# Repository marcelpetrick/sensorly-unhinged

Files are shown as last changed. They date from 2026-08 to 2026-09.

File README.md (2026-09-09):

# sensorly-unhinged








A battery-powered indoor temperature and humidity node, developed as **one
electrical platform in two physical implementations** so that the cost of
compactness can be measured instead of guessed.

**Author: Marcel Petrick <mail@marcelpetrick.it>**

**License: GPLv3 or later. See `LICENSE`.**

**Note: project is generated with AI.**

```
                    ESP32-C6-MINI-1 + SHT45-AD1F + BQ24074 + TPS62840
                    1S LiPo · USB-C · deep sleep · BLE provisioning · MQTT/TLS
                                          |
                 +------------------------+------------------------+
                 |                                                 |
         Variant A - Compact                        Variant B - Thermally isolated
         30 × 34 mm, one rectangle                  28 × 51 mm, milled sensor island
         sensor 11.3 mm from the                    on a 3.5 x 8 mm FR-4 neck,
         nearest heat source                        sensor 16.5 mm away;
                                                    thermal benefit unmeasured
```

| | |
|---|---|
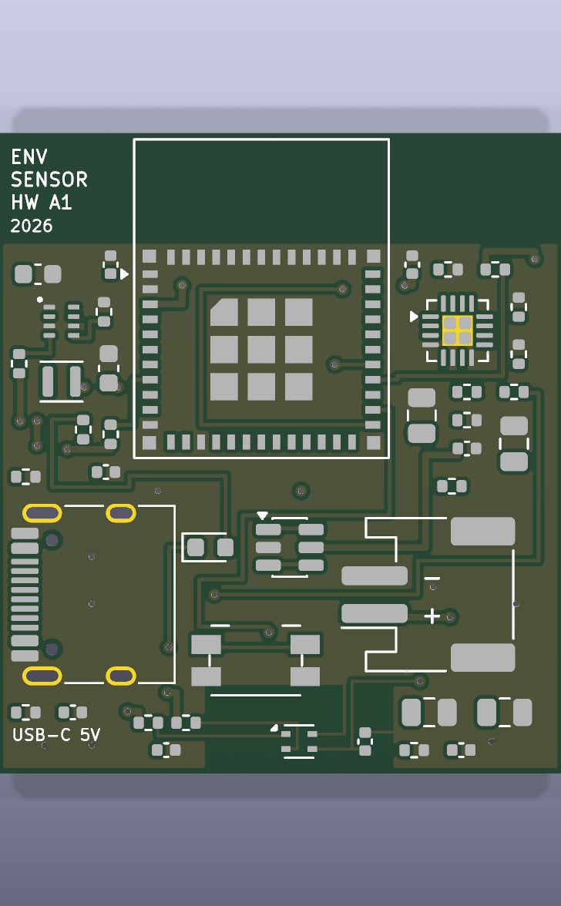
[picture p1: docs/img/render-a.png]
Variant A
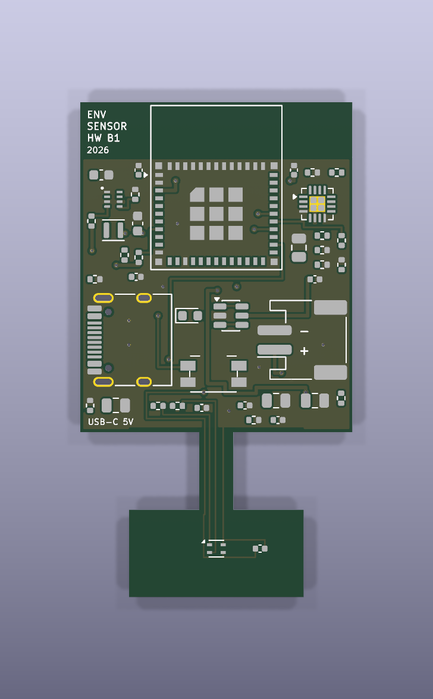
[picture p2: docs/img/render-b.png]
Variant B
|  |  |
| **A — Compact** (HW A1) | **B — Thermally isolated** (HW B1) |
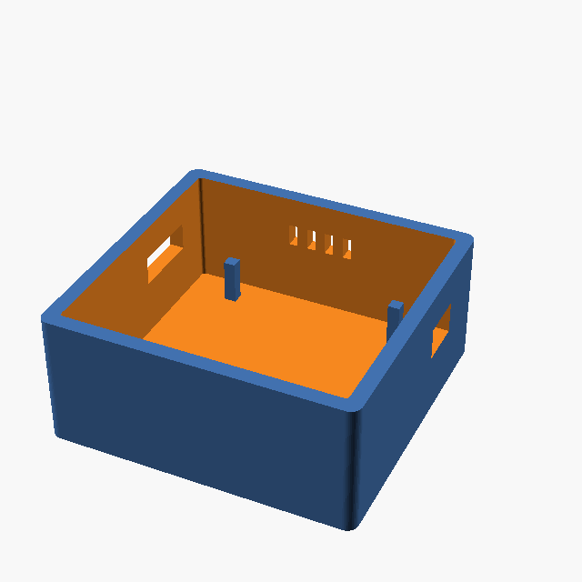
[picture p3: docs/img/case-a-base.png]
Case A
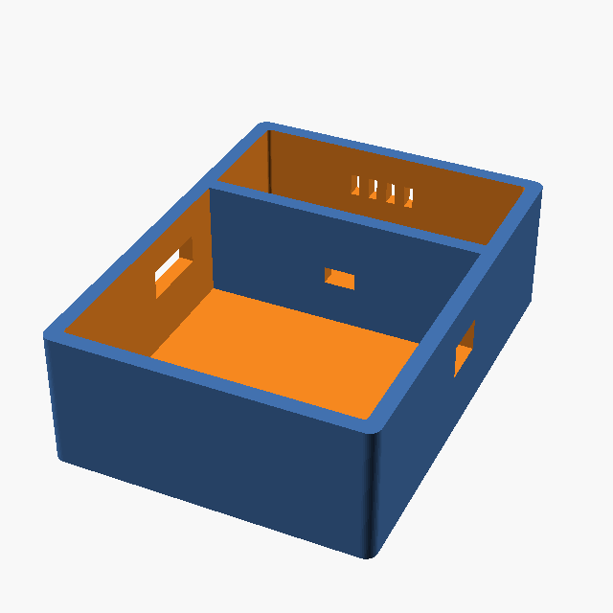
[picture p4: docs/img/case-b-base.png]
Case B
|  |  |
| 47.0 × 39.2 × 18.8 mm, one chamber | 47.0 × 56.2 × 18.8 mm, two chambers, wall at the neck |

Build 5 of each, put them next to a reference instrument, and let the data pick
the design. The decision gate is written down in
[`docs/50-thermal-ab-test-plan.md`](docs/50-thermal-ab-test-plan.md) *before* the
boards exist, including the thresholds under which A wins.

## Status

**Engineering prototype; not ready for fabrication or use.** The
[twenty-finding review](docs/90-expert-review.md) records corrective work and
unresolved qualification. `make outputs` produces explicitly marked draft
review files. `make release-check` requires complete routing, clean DRC/parity
and the evidence listed in `hardware/release-readiness.json`. A development
pipeline pass does not imply a working sensor or safe battery charging.

**Partially routed:** 59 unconnected items on A and 60 on B. The sensor routes
and some power/ground fan-out are generated; the fine-pitch escapes and other
main-board connections remain incomplete. Development DRC has zero errors,
with explicitly limited warnings; it is not a clean manufacturing DRC.
Phase 6 of 14 — see [`docs/00-plan.md`](docs/00-plan.md).

```
KiCad ERC      0 violations
KiCad DRC      0 errors, 7 / 17 development warnings on A / B (KiCad 10.0.6)
Sch/PCB parity 0 differences  (both are generated from one model)
Ratsnest       A: 59 remaining; B: 60 remaining (see hardware/drc-budget.json)
Outputs        4-layer gerbers, drill, CPL, assembly PDF, STEP, schematic PDF, BOM
```

schematic

## Build

Everything runs from `make`. If a step cannot, it is not part of the build.

```bash
./localPipeline.sh   # everything below, with a PASS/FAIL summary
```

Or step by step:

```bash
make license   # every authored source carries an SPDX header
make check     # generator rule checks   (Python only, no KiCad needed)
make test      # fault-injection regressions for electrical, build and model failures
make gen       # regenerate the schematic, both boards, project files, rules, SVGs
make erc       # KiCad ERC on the shared schematic
make drc       # KiCad DRC + schematic/PCB parity gate on both variants
make bom       # BOM + netlist from the shared design model
make thermal   # regenerate the thermal model from the live geometry
make cost      # regenerate the manufacturing estimate from the real design
make mech      # enclosure model + checks + OpenSCAD params (STL if openscad)
make outputs   # gerbers, drill, CPL, assembly PDF, STEP
make render    # KiCad 3D renders
make mech-render # optional enclosure PNG previews (requires a graphics display)
make power     # illustrative battery-side charge budget; replace inputs with measurements
make release-check # fails until routing and qualification are complete
make release-package RELEASE_TAG=hw-a1 # gated ZIP + SHA-256 for one printed revision
make all
```

Python-only checks include `check`, `test`, `bom`, `thermal`, `cost`, and `power`.
ERC/DRC, board renders and exports require KiCad 10 (`kicad-cli`); mesh checks
require OpenSCAD. Offline checks alone cannot establish hardware readiness.

GitHub's **Hardware Quality** workflow runs the same `localPipeline.sh` gate and
retains draft Gerbers, reports and enclosure meshes for 14 days. The separate,
manual **Hardware Release** workflow accepts only a tag matching the revision
printed on the selected PCB (`hw-a1` or `hw-b1` today). It cannot package or
publish until `make release-check` proves clean routing, clean DRC/parity and
all seven qualification-evidence categories. Publishing is opt-in and draft by
default; a successful package contains a SHA-256 checksum and source provenance.

## How the two boards stay one design

`tools/boardgen/` holds the parts, values, netlist, net classes and design
rules **once**. `variants.py` is the only variant-specific file, and it contains
outline, sensor position and thermal zones — nothing electrical. Both
`.kicad_pcb` files are emitted from that model, so a rule change cannot silently
apply to only one board.

The four sensor-island nets are routed by the generator rather than by hand,
because they carry a rule — 0.15 mm wide, no vias, nothing else near them — and
the same rule is written into each variant's `.kicad_dru`. A number that only
lives in a designer's memory gets widened the first time a route is awkward.

## Documents

| | |
|---|---|
| [`AGENTS.md`](AGENTS.md) | working agreement — read before changing anything |
| [`docs/00-plan.md`](docs/00-plan.md) | 14 phases with gates, schedule, risks, non-goals |
| [`docs/10-requirements.md`](docs/10-requirements.md) | numbered requirements, locked vs open |
| [`docs/20-component-selection.md`](docs/20-component-selection.md) | why SHT45 and not BME280; why C6 and not C3 |
| [`docs/30-electrical-design-spec.md`](docs/30-electrical-design-spec.md) | the circuit, every value traced to a datasheet |
| [`docs/40-floorplans.md`](docs/40-floorplans.md) | A vs B, and what the layout decided |
| [`hardware/outputs/schematic/env-sensor.pdf`](hardware/outputs/schematic/env-sensor.pdf) | the schematic, as built |
| [`docs/45-thermal-model.md`](docs/45-thermal-model.md) | generated screening model |
| [`docs/50-thermal-ab-test-plan.md`](docs/50-thermal-ab-test-plan.md) | the experiment and its decision gate |
| [`docs/60-manufacturing-cost.md`](docs/60-manufacturing-cost.md) | generated cost estimate, from the real joint count |
| [`docs/61-cost-reduction.md`](docs/61-cost-reduction.md) | what would make it cheaper, and what each saving costs |
| [`docs/62-fabrication-3-boards.md`](docs/62-fabrication-3-boards.md) | who makes three boards, and what the antenna needs from them |
| [`docs/70-what-the-board-can-do.md`](docs/70-what-the-board-can-do.md) | what firmware alone unlocks — three radios, one board |
| [`docs/80-enclosure.md`](docs/80-enclosure.md) | generated enclosure model, and the requirements it breaks |
| [`docs/vision.md`](docs/vision.md) | the original transcript this was distilled from |

## Layout

```
docs/            requirements, specs, trade studies, test plans
hardware/
  lib/           project footprint library (vendored + authored, verified)
  variant-a/     HW A1 - compact
  variant-b/     HW B1 - thermally isolated
  outputs/       gerbers, drill, BOM, CPL, STEP  (regenerated by CI)
hardware/schematic/  one generated schematic, shared by both variants
tools/boardgen/  the shared model: design, schematic, geometry, placer, router, checks
mechanical/      OpenSCAD enclosures, generated parameters from the board
firmware/        ESP-IDF application (not started)
```

## Licence

**GPL-3.0-or-later** — see [`LICENSE`](LICENSE). That covers everything authored
here: the generator, the schematic and both boards, the enclosure model, the
documents. Every authored source file carries an SPDX header, the generated
KiCad files carry it in their title block, and `make license` fails the build if
one is missing — a licence that only exists at the repository root stops
travelling the moment a file is copied out.

Two things in the tree are not ours and keep their own terms:

| | |
|---|---|
| `hardware/lib/sensorly.pretty/*` and `hardware/lib/sensorly.kicad_sym` (except the two authored parts) | from the [official KiCad libraries](https://gitlab.com/kicad/libraries), CC-BY-SA 4.0 **with the KiCad library exception** — which explicitly permits unlimited use in your own designs without imposing licence terms on the design itself. See `hardware/lib/README.md`. |
| Datasheet figures quoted in `docs/` | the manufacturers'. Cited, not reproduced. |

The KiCad library exception is what makes this combination clean: the footprints
can sit inside a GPL project without the CC-BY-SA terms propagating to the board.

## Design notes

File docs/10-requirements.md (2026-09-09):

# 10 — Product Requirements v1

Every row is a **target** until a prototype measurement promotes it. Rows marked
🔒 are locked and may only change through an ADR.

## Functional

| ID | Requirement | Target | Verified by |
|---|---|---|---|
| F-01 | Measure air temperature | ±0.3 °C system accuracy, in enclosure, in still air | Test 1 + reference comparison |
| F-02 | Measure relative humidity | ±3 %RH system accuracy, in enclosure | Test 6 |
| F-03 | Measurement interval | 5 min, configurable 1–60 min | firmware config test |
| F-04 | Upload interval | 15 min, configurable | firmware config test |
| F-05 | Connectivity 🔒 | 2.4 GHz Wi-Fi, WPA2/WPA3 | bring-up |
| F-06 | Provisioning 🔒 | BLE (no screen, no keyboard, no AP-mode captive portal) | bring-up |
| F-07 | Telemetry 🔒 | MQTT over TLS, JSON payload | backend integration |
| F-08 | Outage buffering | ≥ 500 measurements retained in flash | firmware failure test |
| F-09 | Firmware update 🔒 | OTA, signed | OTA test |
| F-10 | Battery reporting | battery voltage + charging flag in every payload | bring-up |
| F-11 | Device identity 🔒 | per-device serial `ENV-00xx` + per-device credentials | factory test |
| F-12 | Self-test | factory test mode reporting PASS/FAIL per subsystem | 20 stored test records |

## Electrical / power

| ID | Requirement | Target |
|---|---|---|
| E-01 | Battery 🔒 | 1S LiPo, protected cell, replaceable |
| E-02 | Capacity 🔒 | 550 mAh LP702040 configured pack; PCM + 10 kΩ NTC, three-wire PicoBlade harness |
| E-03 | Charging 🔒 | USB-C, 5 V, **100–250 mA** (deliberately slow — the charger is the largest heat source in the product) |
| E-04 | Runtime | > 3 months per charge at F-03/F-04 defaults |
| E-05 | Deep-sleep system current | < 25 µA total (MCU + regulator Iq + leakage) |
| E-06 | System rail | 3.0 V or 3.3 V — **decided by measurement**, see EDS open item |
| E-07 | Peak supply capability | ≥ 500 mA (module TX peaks ~382 mA) |
| E-08 | Charging-state visibility | firmware must know USB is present and flag readings as thermally suspect |

## Mechanical / thermal

| ID | Requirement | Target |
|---|---|---|
| M-01 | Variant A envelope | PCB ~30 × 34 mm; selected-pack case about 47 × 39 × 19 mm |
| M-02 | Variant B envelope | PCB ~28 × 48 mm incl. 12–20 mm sensor tongue |
| M-03 | Sensor air access 🔒 | vents directly at the sensor, small dead volume |
| M-04 | Antenna clearance 🔒 | ≥ 15 mm free space around the module antenna; no battery, metal or copper behind it |
| M-05 | Thermal isolation (B) 🔒 | two routed slots, narrow FR-4 neck, four thin traces, **no inner-layer copper across the neck**, no thermal vias |
| M-06 | Chamber separation (B) 🔒 | enclosure wall between sensor chamber and electronics chamber |
| M-07 | Battery position 🔒 | not behind the antenna, not under the sensor; 0.5 mm XY clearance and 1.0 mm thickness/swelling allowance |
| M-08 | Enclosure | 3D printed for Rev 1 and Rev 2; battery user-replaceable |

## Manufacturing

| ID | Requirement | Target |
|---|---|---|
| P-01 | PCB 🔒 | 4-layer FR-4, standard thickness, standard finish |
| P-02 | Assembly 🔒 | turnkey SMT, essentially single-sided |
| P-03 | Minimum passive 🔒 | 0402 normal minimum; 0603 where space allows; no 0201 |
| P-04 | No exotic processes 🔒 | no BGA, no blind/buried vias, no rigid-flex, no press-fit |
| P-05 | Test access 🔒 | pogo-compatible test pads for power, programming, I²C and charger status |
| P-06 | Quantities 🔒 | Rev 1: 5 × A + 5 × B. Rev 2/series: 20 |
| P-07 | Revision marking 🔒 | revision string on silkscreen (`HW A1`, `HW B1`, …) |

## Compliance (Germany / EU) — Rev 1 posture

| ID | Requirement |
|---|---|
| C-01 | Use a pre-certified radio module (ESP32-C6-MINI-1) and keep its integration conditions; the finished product still requires its own assessment. |
| C-02 | Document the RED/EMC assessment path; do **not** run a certification campaign for 20 prototypes. |
| C-03 | Li-ion transport rules apply to shipping cells — plan for it, do not discover it. |
| C-04 | WEEE/battery-directive obligations noted for any distribution beyond personal use. |
| C-05 | Security: unique per-device credentials, signed OTA, no shared cloud password across the fleet (CRA direction of travel). |

## Non-goals for Rev 1

Mains power · display · rigid-flex or FPC sensor cable (that is Variant C) ·
air quality / CO₂ / pressure · Matter certification · injection moulding ·
double-sided assembly · fuel-gauge IC · formal RED certification campaign ·
more than 20 units.

## Open questions

| # | Question | Closes at |
|---|---|---|
| R-1 | 3.0 V vs 3.3 V rail | prototype power measurement |
| R-3 | Exact vent geometry / open area | thermal Test 5 response-time data |
| R-4 | TWT available on deployment APs? | firmware bring-up |
| R-5 | Sensor tongue neck width vs mechanical strength | first bare-PCB inspection |
| R-8 | **Board retention.** Only 2 lid hold-down pillars fit on A and 1 on B — no bare board is left. Rev 2 should carry two **nylon** M2 holes; the M-04 objection to fasteners near the antenna is about metal, and nylon is not metal. | Rev 2 |
| R-9 | Qualify the selected pack's controlled drawing, NTC curve, protection behavior, lead routing, swelling space and assembled retention | before enclosed charging |

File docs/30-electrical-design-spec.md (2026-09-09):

# 30 — Rev 1 Electrical Design Specification (EDS)

Status: **locks the schematic**. Rev A1 / B1 share this document entirely.
Every value below traces to a datasheet section or a calculation shown inline.
Anything not yet decided sits in §10 Open items — it is not silently assumed.

Datasheet sources used:
- ESP32-C6-MINI-1/1U Datasheet **v1.5** (Espressif) — Table 3-1 Pin Definitions, Table 6-8, Fig. 11-1 land pattern
- TPS62840 **SLVSEC6D** (TI) — §6 Pin Functions, Table 1 RSET, §9.2.2 externals
- BQ24072/73/74/75/79 **SLUS810N** (TI) — Table 7-2 EN1/EN2, §7.5 K-factors, §10.2.2
- SHT4x Datasheet v7.x (Sensirion), SHT45-AD1F product page
- [LP702040 drawing FD_3245_20](https://www.li-polymer-battery.com/wp-content/uploads/2021/09/LP702040-550mAh-1032AT-2Molex-51021-0300.pdf) and [configured-pack page](https://li-polymer-battery.com/3-7v-rechargeable-li-polymer-battery-lp702040-550mah-with-ntc-and-molex-connector/) — selected pack and purchasability
- [Semitec 103AT thermistor data](https://www.semitec-global.com/products/thermistor_at/) — pack NTC family/R-T data
- [Molex 53261 series](https://www.molex.com/en-us/products/series-chart/53261) and drawing 532610271-SD — J2 land pattern and ratings
- [Nexperia 2N7002](https://assets.nexperia.com/documents/data-sheet/2N7002.pdf) and [onsemi 2N7002L](https://www.onsemi.com/pdf/datasheet/2n7002l-d.pdf) — Q1 primary/alternate G-S-D pinout and limits

---

## 1. Rail architecture

```
USB-C VBUS ─┬─ ESD ─ IN ┐
            │           │  BQ24074  power path
            └─ CC1/CC2  │  ┌──────────────┐
                        └──┤ IN       OUT ├──► VSYS ──► TPS62840 ──► +3V0 ──► ESP32-C6
                           │              │                 (buck)      │
 LP702040 + PCM + NTC ─────┤ BAT      TS  ├── pack 10k NTC              ├──► SHT45  (island in B)
              1S LiPo      │ ISET ILIM    │                             └──► LED / pull-ups
                           └──────────────┘
```

| Net | Nominal | Notes |
|---|---|---|
| `VBUS` | 5.0 V | USB-C, sink only |
| `VSYS` | mode/load dependent | BQ24074 `OUT`: battery-fed without USB; do not assume a 3.6 V minimum throughout discharge |
| `VBAT` | 3.0–4.2 V | protected 1S LiPo at `BAT` |
| `+3V0` | **3.30 V baseline** | historical net name retained for both build options; R6 sets actual voltage |
| `GND` | — | single net, solid L2 plane (except the Variant-B neck) |

---

## 2. U1 — ESP32-C6-MINI-1-N4

Module, not bare silicon: carries flash, crystal, RF matching, PCB antenna and
Espressif's RED/CE type examination. 13.20 × 16.60 × 2.40 mm, 53 pads
(48 perimeter + 5 ground), land pattern per datasheet Fig. 11-1.

### 2.1 Pin assignment (locked)

| Net | GPIO | Module pin | Rationale |
|---|---|---|---|
| `SDA` | IO6 | **15** | `LP_I2C_SDA` — lets the LP core read the sensor without waking the HP core (future power option) |
| `SCL` | IO7 | **16** | `LP_I2C_SCL` |
| `VBAT_SENSE` | IO2 | **5** | `ADC1_CH2` |
| `CHG_N` | IO23 | **29** | charger `/CHG`, open-drain, external 100 k pull-up |
| `PG_N` | IO22 | **28** | charger `/PGOOD` — this is the "USB is present" flag required by E-08 |
| `LED_N` | IO19 | **25** | status LED, active low |
| `BTN_PROV` | IO9 | **23** | strapping pin with internal weak pull-up: button low at reset = download mode, low at runtime = start BLE provisioning. One button, two jobs. |
| `USB_DM` | IO12 | **17** | native USB Serial/JTAG |
| `USB_DP` | IO13 | **18** | native USB Serial/JTAG |
| `UART_TX` | TXD0/IO16 | **31** | test pad only (fallback console) |
| `UART_RX` | RXD0/IO17 | **30** | test pad only |
| `TEST_MODE` | IO20 | **26** | test pad; fixture pulls low to enter factory test |
| `USB_ISEL` | IO21 | **27** | charger EN1; 100 kΩ pull-down makes USB100 the reset/fault default; firmware may assert only after USB configuration |
| `CHARGE_ENABLE` | IO18 | **24** | drives Q1 gate; external pull-down defaults low, and Q1 can pull charger `/CE` low only after firmware validates pack temperature |
| `PACK_TS` | IO3 / ADC1_CH3 | **6** | reads the pack's 103AT-2 NTC/charger TS voltage; not a spare GPIO |
| *(reserved)* | IO0, IO1 | 12, 13 | `XTAL_32K_P/N` — **left free** for an optional 32.768 kHz crystal if deep-sleep timing accuracy proves insufficient |
| *(spare)* | IO4, IO5, IO14 | 9, 10, 19 | available for later use |
| **NC** | IO8, IO15 | 22, 20 | strapping pins (boot-mode / JTAG-select) — deliberately unconnected |
| `+3V0` | 3V3 | 3 | |
| `EN` | EN | 8 | see §2.2 |
| `GND` | GND | 1, 2, 11, 14, 36–53 | all tied, all via-stitched |

**Deliberate choices to note in review:**
- USB D+/D− *are* connected (the vision document left this optional). The native
  USB Serial/JTAG on the C6 removes any need for a UART bridge IC, makes
  bring-up and debugging vastly easier, and costs two traces plus one ESD array.
  Production programming still uses the pogo fixture.
- IO8 and IO15 are left NC rather than used as spares: both are latched
  strapping pins, and an unexpected external load on them is a classic
  "boots on the bench, not in the enclosure" failure.

### 2.2 Support circuitry

| Ref | Value | Purpose / source |
|---|---|---|
| C1 | 22 µF / 6.3 V X5R 0805 | bulk at supply entrance. Espressif requires ≥ 10 µF; TX peaks reach ~382 mA (datasheet §6.4) |
| C2 | 100 nF / 16 V X7R 0402 | HF decoupling, at pin 3 |
| C3 | 1 µF / 16 V X7R 0402 | mid-frequency decoupling |
| R1 | 10 kΩ 0402 | EN pull-up to +3V0 |
| C4 | 1 µF 0402 | EN RC delay (≈10 ms with R1) — "do not leave EN floating" (datasheet Table 3-1) |
| SW1 | SMD tactile, 3.5 × 2.9 mm | `BTN_PROV` → GND, no external pull-up needed (internal weak PU) |
| C5 | 100 nF 0402 | SW1 debounce |
| D1 | LED 0603, green | status |
| R2 | 3.3 kΩ 0402 | LED series — ~0.5 mA at 3.0 V; the LED is a diagnostic, not a lamp |

Active-low current path: `+3V0 → R2.1 → R2.2 → D1.2 (A) → D1.1 (K)
→ U1.25 (LED_N)`. Pin names are verified against the vendored KiCad LED
symbol and LED_0603 footprint; their geometry and rotation are unchanged.
`make test` guards this path and charger timer wiring for both variants.

---

## 3. U2 — SHT45-AD1F (environmental sensor)

DFN-4, 1.5 × 1.5 × 0.5 mm, no central pad. I²C address **0x44**.

| Symbol pin | Name | Net |
|---|---|---|
| 1 | SDA | `SDA` |
| 2 | SCL | `SCL` |
| 3 | VDD | `+3V0` |
| 4 | VSS | `GND` |

| Ref | Value | Notes |
|---|---|---|
| C6 | 100 nF 0402 | VDD decoupling, placed **on the island** immediately at pin 3 — the only passive allowed there |
| R3, R4 | 10 kΩ 0402 | SDA/SCL pull-ups to +3V0 — **placed on the main board, never on the island** (§3.1) |

### 3.1 Sensor-island electrical rules (apply to both variants; mandatory for B)

1. Exactly **four** nets cross to the sensor: `+3V0`, `GND`, `SDA`, `SCL`.
2. Those four traces are **0.15 mm** wide across the neck and are the *only*
   copper there. No pour, no plane, no stitching vias, no thermal vias.
3. Inner layers L2 and L3 carry **no copper at all** across the neck.
4. `GND` reaches the sensor as a trace, not as a plane. The sensor's ground is
   a stub of the main plane, deliberately high-impedance thermally.
5. No LED, regulator, charger, inductor or battery within the island.
6. Pull-ups sit on the main board so their (small) dissipation stays there.

The B spatial DRC rules name these four nets explicitly, including supply and
ground, and enforce 0.15 mm on every track entering the island rule area.
Membership in the broad Power net class does not permit VBAT/VBUS/VSYS there.
The spatial width rule follows generic width defaults so it takes precedence.
KiCad expression semantics: [custom rules](https://docs.kicad.org/10.0/en/pcbnew/pcbnew.html#custom_design_rules).
The generator also counts conductors through successive neck cross-sections:
one trace per named net, all on F.Cu at 0.15 mm. C6 must connect locally on B's
island; a second ground detour through the neck is a thermal-rule failure even
though it introduces no new electrical net. B routes the ground tap before its
supply feed and searches for plane access just above the neck, always excluding
the neck from via placement. These search seeds are geometry assumptions, not
fixed electrical values. A has no neck and retains its existing routing order
and fan-out. Both variants retain the same circuit and netlist.

**Why trace width is the primary lever** — first-order conduction through the
Variant-B neck (3.5 mm wide × 8.0 mm long × 1.6 mm FR-4, four 0.15 mm traces in
35 µm copper), using k(FR-4) ≈ 0.3 W/m·K and k(Cu) = 385 W/m·K:

| Path | Conductance |
|---|---|
| FR-4 bridge | 0.3 × (3.5e-3 × 1.6e-3) / 8e-3 = **0.21 mW/K** |
| 4 × copper trace | 4 × 385 × (0.15e-3 × 35e-6) / 8e-3 = **1.01 mW/K** |
| **Total neck** | **≈ 1.2 mW/K** |

The four hair-thin traces conduct **five times more heat than the entire FR-4
bridge**. Widening them to 0.3 mm would double total neck conduction. This is
the single most important number in the Variant-B design, and it is why §3.1.2
is a hard rule rather than a preference. (First-order estimate, 1-D conduction,
no convection along the neck — to be validated by Test 1–4.)

---

## 4. U3 — TPS62840DLC (system regulator)

SON-8 (DLC), 1.5 × 2.0 mm. 1.8–6.5 V in, 750 mA, **60 nA typical operating Iq**
(datasheet Table: I<sub>Q_VIN</sub> 36 nA typ / I<sub>Q_VOS</sub> 56 nA typ).

| Pin | Name | Net |
|---|---|---|
| 1 | GND | `GND` |
| 2 | VIN | `VSYS` |
| 3 | MODE | `GND` — low = Power-Save Mode, automatic PFM/PWM. Must be terminated. |
| 4 | EN | `EN_REG`, connected to `VSYS` **only through R5**; removing R5 isolates EN for fixture control (never leave the enabled pin floating) |
| 5 | VSET | via R6 to `GND` |
| 6 | STOP | `GND` — normal operation (STOP costs 70 µA, never used here) |
| 7 | SW | `L1` |
| 8 | VOS | `+3V0`, routed directly to C8 with a short trace |

| Ref | Value | Source |
|---|---|---|
| L1 | **2.2 µH**, DFE201612E-2R2M (2.0 × 1.6 × 1.2 mm), DCR ≈ 116 mΩ | datasheet Table 4 |
| C7 | 4.7 µF / 10 V X5R 0603 (input) | "a 4.7-µF ceramic capacitor is required" at VIN |
| C8 | 10 µF / 6.3 V X5R 0603 (output) | datasheet §9.2.2.2 |
| R5 | 0 Ω 0402 | EN tie (a resistor, not a short, so EN can be lifted for current measurement) |
| **R6** | **267 kΩ 1 % 0402 → V<sub>OUT</sub> = 3.3 V baseline** | datasheet Table 1 (E96 nominal) |
| *R6 characterization* | *52.3 kΩ 1 % → V<sub>OUT</sub> = 3.0 V* | controlled characterization only; same table |

### 4.1 Rail margin and controlled characterization

The shared baseline is now **3.3 V**. The [ESP32-C6-MINI-1 datasheet,
Recommended Operating Conditions](https://www.espressif.com/sites/default/files/documentation/esp32-c6-mini-1_datasheet_en.pdf)
specifies 3.0–3.6 V at the module. A nominal 3.0 V leaves no allowance for
regulator error, trace loss or TX transients. R6 = 267 kΩ selects 3.3 V for the
DLC part ([TI SLVSEC6D, Table 1](https://www.ti.com/lit/ds/symlink/tps62840.pdf)).
The historical `+3V0` net name is not a voltage guarantee.

All ten initial units use 267 kΩ for the primary A/B experiment. Only after
baseline testing may matched A/B units be reworked to 52.3 kΩ for a separate
3.0 V characterization run, with new as-built records. This does not qualify
3.0 V for normal use; EDS-5 remains open.

Measure module-pin minimum/maximum voltage during boot, TX and supply switching
across the selected pack's usable discharge range. A buck in 100% duty cannot
maintain its setpoint below dropout. Stop operation before the rail leaves the
module specification; test brownout/recovery and retained records. Required
cutoff depends on measured path loss, pack and transient load, not just nominal
cell voltage. Owner: hardware/firmware maintainer; gate: prototype power test.

---

## 5. U4 — BQ24074RGTR (charger + power path)

VQFN-16 3 × 3 mm with exposed pad (EP → `GND`).

| Pin | Name | Net / value |
|---|---|---|
| 1 | TS | `PACK_TS`: J2.2 → selected pack's **103AT-2 NTC** → J2.1/GND; also U1 ADC1_CH3 (see §5.2) |
| 2, 3 | BAT | `VBAT` |
| 4 | /CE | `CHARGE_EN_N`: R18 = 47 kΩ to `VBUS`, Q1 drain; VBUS disables charging before MCU power-up |
| 5 | EN2 | `GND` — resistor-programmed ILIM mode cannot be selected in normal operation |
| 6 | EN1 | `USB_ISEL` (IO21) + R8 = 100 kΩ to GND |
| 7 | /PGOOD | `PG_N` (open drain) + R9 = 100 kΩ pull-up to `+3V0` |
| 8, 17(EP) | VSS | `GND` |
| 9 | /CHG | `CHG_N` (open drain) + R10 = 100 kΩ pull-up to `+3V0` |
| 10, 11 | OUT | `VSYS` |
| 12 | ILIM | R11 (see below) |
| 13 | IN | `VBUS` |
| 14 | TMR | **NC** — default safety timers enabled; grounding this pin disables them (TI SLUS810N, Pin Functions) |
| 15 | ITERM | R12 (see below) |
| 16 | ISET | R13 (see below) |

EN2 is hard-low. EN1 low selects USB100; EN1 high selects USB500 (datasheet
Table 7-2). R8 keeps EN1 low while the ESP32 is off, reset or high-impedance.
The 500 mA state therefore requires an explicit firmware action after USB
enumeration/configuration; no boot transient can select it.

### 5.1 Charge current — the most thermally consequential resistor on the board

Datasheet K-factors: K<sub>ISET</sub> = 890 AΩ, K<sub>ILIM</sub> = 1550 AΩ,
K<sub>ITERM</sub> = 0.0300 (ISET mode).

| Ref | Function | Equation | Value | Result |
|---|---|---|---|---|
| R13 | fast charge | nominal 890/4420; worst case 975/(4420 × 0.99) | **4.42 kΩ 1 %** | 201 mA nominal, **≤223 mA** worst case |
| R11 | ILIM fallback | nominal 1550/8000; worst case 1720/(8000 × 0.99) | **8.00 kΩ 1 %** | **194 mA nominal, ≤217 mA** if EN2 is reworked high; mode is unreachable as built |
| R12 | termination | nominal 0.0300 × 3010/4420 | **3.01 kΩ 1 %** | ≈20.4 mA nominal, ≤26.1 mA worst case |

The 4.42 kΩ value is selected against E-03's 250 mA ceiling, using the BQ24074
maximum K<sub>ISET</sub> and the resistor's negative tolerance. It is also below
both public pack figures: the product page says 225 mA and drawing FD_3245_20
says 275 mA. The stricter figure governs until the supplier resolves that
conflict in writing. Nominal arithmetic alone is not the safety limit. The
optional 8.87 kΩ slow build remains available for thermal tests.

**Dissipation check.** The BQ24074 is a linear charger, so
P = (V<sub>IN</sub> − V<sub>BAT</sub>) × I<sub>CHG</sub>. Using the bounded
223 mA charge current, (5.0 − 3.4) × 0.223 = **0.357 W** in a 3 × 3 mm QFN.
This is not a
worst-case bound: input/current tolerances, lower cell voltage and power-path
load require separate evaluation. Another point is
(5.0 − 3.8) × 0.223 = 0.268 W. **This is the largest heat source in the product —
larger than the radio, and unlike the radio it runs for hours.** It is the
reason Variant B exists and the reason `PG_N` is wired to a GPIO: firmware must
flag or suspend environmental reporting while charging (E-08).

At 100 mA the same example is 0.16 W. The prototype run will tell us whether
the bounded 223 mA is acceptable inside the enclosure or whether the series build drops to
100 mA and a longer charge time.

### 5.2 Pack temperature and charge qualification

J2.2 connects the selected pack's Semitec 103AT-2 NTC directly to TS and to
U1 ADC1_CH3. The BQ24074 direct-NTC window is approximately 0–50 °C for that
thermistor, while pack drawing FD_3245_20 permits charging only from 0–45 °C.
The charger TS input alone therefore cannot enforce the pack's upper limit.

R18 = 47 kΩ pulls `/CE` directly to VBUS. This reaches a valid high before the
BQ24074's 4.35 V minimum operating input, rather than depending on the later
3 V MCU rail. Q1 (onsemi 2N7002LT1G; G-S-D pins 1-2-3) isolates IO18 from
VBUS. R7 = 100 kΩ holds Q1's gate low at reset or with missing firmware, so Q1
is off and charging is disabled. Firmware may drive `CHARGE_ENABLE` high only
after `PG_N` indicates VBUS and repeated calibrated
`PACK_TS` readings prove the NTC is inside the pack's 0–45 °C charge range with
an uncertainty guard band. It must release CE on out-of-range, implausible,
open/short, ADC, watchdog or timing fault. The BQ24074's own TS hot/cold window
and floating-TMR safety timers remain independent backups.

R18 is checked against TI's approximately 285 kΩ internal CE pull-down:
at the 4.35 V minimum operating input, 4.35 × 285/(285 + 47) = **3.73 V**, above
the 1.4 V high threshold; nominally CE crosses 1.4 V at 1.63 V VBUS, below
charger UVLO. When Q1 is on, R18 asks it to sink only about 5/47 kΩ = **106 µA**.
The onsemi part's maximum 2.5 V gate threshold is specified at 250 µA, so a
3.0 V GPIO drive has margin at this lower drain load. The slow-ramp/startup
waveform is nevertheless part of EDS-9Q because the internal pull-down is only
specified as approximate.

Obtain written confirmation that the shipped pack matches FD_3245_20, then
calculate the firmware thresholds from the Semitec 103AT-2 R/T curve and the
BQ24074 worst-case 72–78 µA TS current. Test cold, hot, sensor-open,
sensor-short, charge termination, safety-timer expiry and recovery on five
packs. Charging in a closed enclosure remains prohibited until that evidence
is linked from `hardware/release-readiness.json`; the circuit implementation
alone is not qualification.

| Ref | Value | Purpose |
|---|---|---|
| C9 | 10 µF / 16 V X5R 0805 | IN bypass (datasheet: 1–10 µF) |
| C10 | 10 µF / 6.3 V X5R 0805 | OUT bypass |
| C11 | 10 µF / 6.3 V X5R 0805 | BAT bypass |
| C12 | 100 nF 0402 | IN HF bypass |

---

## 6. Battery measurement

Requirement F-10, E-05.

| Ref | Value |
|---|---|
| R14 | 2.2 MΩ 1 % 0402, `VBAT` → `VBAT_SENSE` |
| R15 | 2.2 MΩ 1 % 0402, `VBAT_SENSE` → `GND` |
| C13 | 100 nF 0402 at `VBAT_SENSE` |

Divider ratio 0.5: 4.20 V → 2.10 V, comfortably inside ADC1 range with 12 dB
attenuation. Source impedance 1.1 MΩ with C13 gives RC = 110 ms. After first
energization use at least 550 ms (5 RC, engineering target), not 20 ms, and
validate ADC acquisition/calibration against a meter. The continuously powered
divider is already settled on normal deep-sleep wake. See `71-firmware-contract.md`.

**Deviation from the vision document, deliberately.** The vision specified a
*switched* divider (MOSFET or high-side switch) to avoid continuous drain. We
use a permanent divider instead:

- continuous drain = 4.2 V / 4.4 MΩ = **0.95 µA**, i.e. **3.8 % of the 25 µA
  sleep budget** (E-05) and ≈ 8 mAh per *year* against a 500–1000 mAh cell;
- a switched divider costs a MOSFET plus a gate resistor, a GPIO, board area,
  and adds its own off-state leakage and a failure mode where a stuck switch
  reports a flat battery on a full cell;
- the divider sits in the electronics chamber and dissipates 4 µW — thermally
  irrelevant.

Buying 0.95 µA back is not worth three extra parts on a board this size. Recorded
here so the reviewer sees it was a decision, not an oversight.

---

## 7. USB-C (J1) — charge and debug, sink only

| Ref | Part / value | Notes |
|---|---|---|
| J1 | USB-C receptacle, 16-pin SMD, through-hole mounting lugs | mechanical strength is the selection criterion, not pin count |
| R16, R17 | 5.1 kΩ 1 % 0402, CC1→GND, CC2→GND | UFP (sink) advertisement — **two separate resistors, never one shared** |
| U5 | USBLC6-2SC6, SOT-23-6 | ESD on D+/D− and VBUS |
| C14 | 100 nF 0402 | VBUS local |
| — | shield → `GND` | direct tie for Rev 1; document if EMC testing later wants an RC |

D+/D− route to IO13/IO12 as a differential pair, 90 Ω target, kept short and
away from the antenna and the inductor.

### 7.1 Source-current policy — fail-safe USB100, enumerated USB500

The supported policy is explicit:

1. On attach, reset, firmware crash or unconfigured operation, R8 holds EN1 low
   while EN2 is hard-low. The BQ24074 USB100 state limits total input current to
   100 mA maximum (system load plus battery charge).
2. A USB 2.0/3.x data host may be used for charging/debugging. Firmware may set
   `USB_ISEL` high only after the device reaches the USB configured state and
   must clear it on suspend, deconfiguration, detach or USB-stack failure. This
   selects USB500, whose datasheet maximum is 500 mA.
3. USB-C power adapters and charge-only/unknown sources are supported only at
   the 100 mA default because this design does not decode Rp current or charging
   port signatures. They never justify `USB_ISEL=1`.
4. Radio operation from USB with a missing or deeply depleted pack is not
   supported: ESP32 transmit peaks can exceed the 100 mA default. The protected
   battery supplies the transient through the BQ24074 power path. Factory
   battery-less testing uses the declared regulated fixture supply and disables
   radio until USB configuration.

R11 is retained because TI requires ILIM to be terminated, but EN2 low makes its
mode unreachable as assembled. Its 8.00 kΩ value also bounds a deliberate EN2
rework to 217 mA worst case. Qualify with a USB current analyzer: attach/reset,
configuration, suspend/resume, detach, firmware crash, low-battery TX and VBUS
transients on representative USB 2.0 and USB 3.x hosts plus a charge-only source.
The policy and circuit are locked; measured evidence is still required before
the USB release gate closes.

---

## 8. Selected battery and connector (locked architecture)

The shared A/B pack is **LiPol drawing FD_3245_20**, an LP702040 1S1P assembly:
550 mAh minimum / 560 mAh typical, 3.7 V / 2.04 Wh, PCM protected, Semitec
103AT-2 NTC, 45 ± 3 mm AWG-28 UL1571 leads and Molex 51021-0300 connector.
The drawing's maximum assembled envelope is 42 × 20.5 × 7.3 mm. Cavity order is:

| J2 / housing cavity | Wire | Net |
|---:|---|---|
| 1 | black | `GND` (−) |
| 2 | yellow | `TS` / NTC |
| 3 | red | `VBAT` (+) |

J2 is Molex **53261-0371**, the 1.25 mm PicoBlade right-angle SMT header mating
with 51021-0300. The board silk prints `− T +` in cavity order. Its footprint is verified against
Molex drawing 532610271-SD; incoming inspection must continuity-check every pack
before mating because reverse polarity can destroy the charger and vent a cell.

The supplier webpage establishes that this configuration can be purchased in
five-piece prototype quantity and the dated drawing defines the assembly.
Procurement must obtain written lot confirmation, reconcile the page's 225 mA
with the drawing's 275 mA maximum charge current, and supply the applicable
transport test record. No visually similar
two-wire or unprotected LP702040 is an approved substitute. This configured
pack is a single-source prototype risk; a second pack source must be qualified
or explicitly accepted before the 20-unit series.

---

## 9. Design for test (J3 pogo field)

Test pads: **1.5 mm** round exposed copper, **2.54 mm** grid, all on the bottom
side, all within one rectangular region so the fixture is a simple plate.

| # | Pad | Purpose |
|---|---|---|
| 1 | `GND` | fixture ground (two pads, opposite corners) |
| 2 | `VBUS` | inject 5 V without a cable |
| 3 | `VSYS` | power-path output check |
| 4 | `+3V0` | rail check |
| 5 | `VBAT` | battery injection / cell voltage |
| 6 | `EN` | force reset |
| 7 | `BTN_PROV` (IO9) | force download mode |
| 8 | `UART_TX` | console |
| 9 | `UART_RX` | console |
| 10 | `USB_DP` | native USB flashing via fixture |
| 11 | `USB_DM` | native USB flashing via fixture |
| 12 | `SDA` | I²C bring-up / sensor probe |
| 13 | `SCL` | I²C bring-up / sensor probe |
| 14 | `CHG_N` | charger state |
| 15 | `PG_N` | USB-present state |
| 16 | `TEST_MODE` (IO20) | fixture pulls low → factory test firmware |

---

## 10. Open items (this document does **not** close them)

| # | Item | Closing gate |
|---|---|---|
| EDS-1 | Exact USB-C receptacle MPN (JLCPCB basic-part availability drives this) | before prototype order |
| EDS-4 | Whether the bounded 223 mA charging design is thermally acceptable in the enclosure, or the 100 mA option is required | thermal Test 3 |
| EDS-5 | 3.0 V vs 3.3 V — R6 value for the series build | prototype power + RF measurement |
| EDS-6 | Whether the 32.768 kHz crystal on IO0/IO1 is needed | deep-sleep timing drift measurement |
| EDS-7 | Antenna: flush with board edge (Rev 1) vs overhanging the outline | RF test in the finished enclosure |
| EDS-8 | Neck width 3.0 / 3.5 / 5.0 mm for Variant B | first bare-PCB mechanical inspection + Test 1 |
| EDS-9Q | Qualify LP702040 supplier drawing, pack NTC thresholds, protection, timer/fault behavior and assembled retention; owner: hardware maintainer | before enclosed battery charging |
| EDS-10Q | Measure the locked USB100/USB500 policy on representative hosts and fault transitions; owner: hardware/firmware maintainer | before unrestricted USB use |

## 11. Review checklist for this spec

- [ ] every ESP32 module pin number re-checked against datasheet v1.5 Table 3-1
- [ ] SHT4x pin 1 orientation re-checked against the Sensirion land pattern
- [ ] BQ24074 EP tied to GND with a via array
- [ ] no strapping pin loaded (IO8, IO9, IO15, MTMS/IO4, MTDI/IO5)
- [ ] every open-drain charger output has exactly one pull-up
- [ ] CC1 and CC2 have separate 5.1 kΩ resistors
- [ ] battery connector polarity printed on silkscreen
- [ ] all four island nets, and only those four, cross the neck at 0.15 mm

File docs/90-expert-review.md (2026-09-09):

# 90 — Expert review and corrective work

Reviewed 2026-09-08 against `038b3ca`. Ranked by consequence, then likelihood.
This is a prototype design review, not a declaration of electrical safety,
manufacturability, RF performance, or measured accuracy.

The strongest idea is the controlled comparison of compactness against thermal
isolation. A shared electrical model, vendored libraries, explicit requirements,
and generated layouts make design intent unusually inspectable. Keep those.
The central weakness is that successful generation is too easily confused with
a working instrument. Neither board is connected completely, and several
important physical assumptions contradict the generated geometry.

As a product, the strongest potential promise is trustworthy indoor readings
with predictable maintenance. The repository still needs an explicit deployment
profile: who operates the MQTT service, how users recognize stale/charging-biased
data, and what battery replacement and provisioning feel like. Extra radio
capabilities do not answer those questions. The firmware contract and charge
budget make those omissions visible without expanding Rev 1's non-goals.

| Rank | Severity / domain | Finding and evidence at review baseline | Corrective work |
|---|---|---|---|
| 1 | Critical / battery | TMR is grounded, disabling safety timers while EDS claims they are enabled. TS is fixed and CE grounded; enclosed charging is called acceptable without pack qualification. | Leave TMR open for default timers; remove unsupported safety acceptance. Pack-temperature protection remains a release blocker. |
| 2 | Critical / manufacturing | Both boards have 58 unconnected items, but `make outputs` and CI publish a “fab-package”. | Separate draft exports from a release target that rejects unfinished routing and unresolved qualification. Routing remains open. |
| 3 | High / electrical | D1 anode (pin 2) is grounded; its cathode reaches a GPIO through R2. The active-low LED cannot work. | Wire supply → R2 → anode, cathode → GPIO; regenerate both boards and schematic. |
| 4 | High / electrical | Folding `EN_REG` into `VSYS` puts both R5 terminals on one net. Lifting R5 cannot disable U3. | Preserve the enable net and test resistor isolation. |
| 5 | High / power integrity | Nominal 3.0 V is the ESP32 module's minimum, leaving no tolerance or load-transient margin. EDS describes dropout as graceful. | Use 3.3 V as the baseline; reserve 3.0 V for controlled characterization and require measured rail limits. |
| 6 | High / USB power | R11 permits ~502 mA independent of source advertisement or USB configuration. The documentation implies any USB source is suitable. | Specify the supported bench source and require source-current qualification before release; host negotiation remains open. |
| 7 | High / mechanical | The lid locating lip is a solid plate and pillars start at `lid_total`, extending 1.2 mm too far when assembled. | Use a perimeter lip and measure pillar reach from the lid seating surface. |
| 8 | High / mechanical | B's divider at y=33.5 overlaps the full-width body ending at y=34; the USB aperture is centred on the PCB plane, covering only half the connector height. | Place the divider inside the actual neck and centre the USB opening on the connector; add geometry checks. |
| 9 | High / product fit | The 35×30×5 mm planning battery does not fit either permitted bay; volume-derived mAh is presented as available capacity. | Check the actual planning dimensions and stop inferring purchasable cell capacity; selected pack/retention remain open. |
| 10 | High / battery life | The >3-month requirement has no numerical energy allocation and the enclosure cannot hold the assumed capacity. | Add a reproducible battery-side charge budget and feasible-upload calculation. |
| 11 | High / thermal model | The model assumes four full-width copper planes to A's sensor, but `_zones` removes all pours around it; the README promises “57x less conduction”. | Label the slab calculation as a hypothetical bound, derive shared constants, remove predicted accuracy claims. |
| 12 | High / experimental design | One-minute MQTT logging changes the default duty cycle; reference placement is geometrically inconsistent; rail subgroups are pooled; decision branches overlap. | Define acquisition independently of upload, matched positions/rails, reference uncertainty, and an ordered inconclusive-capable decision gate. |
| 13 | High / firmware and UX | F-03…F-12 have no implementation; stale, charging-biased or unauthenticated readings have no executable product contract. | Define an implementation/acceptance contract and expose missing firmware as a release blocker. Firmware and device testing remain open. |
| 14 | High / sourcing | `bom.py` calls every nonempty alternate “qualified”, including U3's incompatible TPS62841 and alternative footprints. | Distinguish candidates from qualification and report single-source risks honestly. |
| 15 | High / assembly | BOM grouping ignores `Part.dnp`; CPL export does not explicitly exclude DNP/fixture pads. | Carry population state through BOM and filter placement exports. |
| 16 | High / verification | DRC accepts entire warning types and missing parity as success. This machine reports 12/14 accepted warnings versus README's 5/4. | Validate report structure and review exact warning identities rather than unlimited categories. |
| 17 | High / build reliability | Shell loops in `outputs`, `mech`, `render`, and `drc` can conceal earlier tool failures behind a final successful command. | Make failures propagate, retain diagnostics, and test failed-tool behavior. |
| 18 | High / reproducibility | Filled-board cache excludes schematic/library dependencies; `make -j all` may run generation and checks concurrently. | Declare dependencies and serialize mutation-dependent aggregate builds. |
| 19 | High / thermal rules | B's neck rule allows every Power net, including VBAT/VBUS/VSYS; the width rule covers only SDA/SCL. | Limit the neck to the four named nets and constrain power traces there too. |
| 20 | High / model integrity | Net-to-pad dictionaries silently overwrite duplicate assignments; unknown pads and shorted resistor terminals can reach generated files. | Validate connectivity before writing artifacts, with fault-injection regression tests. |

Repository corrections can be verified here. Battery safety, finished routing,
RF/rail measurements, physical enclosure fit, and firmware behavior cannot be
closed by a document or a green generator check. The final disposition below
will record what was actually verified.

Model integrity: `tools/boardgen/validate.py` runs before schematic generation.
Fault-injection tests reject duplicate references, multiply assigned pins,
unknown pads and bypassed passives, including the original R5 regression.

Build failure propagation: Make recipes use `-eu` and delete failed targets.
Mesh export retains OpenSCAD diagnostics; optional PNG previews are explicitly
`make mech-render` so a headless mesh gate needs no graphics display.
Filled-board prerequisites include schematic, symbols, footprints, project rules
and the Makefile. Aggregate builds are serialized even with `make -j` because
generation writes inputs to subsequent checks.
DRC development waivers are capped per violation type and item UUID set in
`hardware/drc-budget.json`; missing parity, omitted severity checks, ignored
checks and reports for another board fail. Release requires zero warnings.
KiCad 10 disables five checks by default; the generated project enables them
explicitly so the report cannot silently omit those checks.
Mesh verification rejects missing/nonfinite files and reads both ASCII and
binary STL; all three axes, including pillar height, are checked.
Isolated build tests inject failing KiCad/OpenSCAD executables and verify that
the first failed export terminates its recipe without a success message.

Verification exposed another model-integrity failure under finding 20: J1's four
SH pads have different lengths, but the parser kept only the last length. After
the LED correction this caused a real 0.18 mm clearance on B against a 0.20 mm
rule. The parser now conservatively retains the largest repeated-pad dimensions;
the library land pattern itself is unchanged.
`make mech` also renders the seated lid/base intersection for each variant;
it accepts only OpenSCAD's explicit empty-intersection result, not a generic
export failure. This checks the corrected lid/divider relationship in 3D.
Enabling the default-ignored via-centering check exposed a 0.1 mm CHG_N stub
past a via centre. The generator trims only collinear endpoints already wholly
inside same-net via copper; it neither moves vias nor redirects other routes.
`make test-kicad` injects VBAT and widened GND tracks into scratch copies of B
and requires KiCad to report the corresponding island-rule violations.
The routing audit also found five physical B neck traces: C6 ground detoured to
the main board. C6 taps are now confined to the island, and every neck cut must
contain exactly four conductors. This corrects finding 19 beyond net-class rules.
The injected tracks use B.Cu to avoid KiCad associating a touching test track
with an existing F.Cu sensor net; both tests assert the actual named DRC rule.
An additional fault-injection test verifies that one reviewed warning passes
but two occurrences of the same warning exceed its allowance and fail.

## Final disposition

The review is documented and corrective changes are retained as atomic local
commits after `038b3ca`. **This is still an unfinished prototype, not a released
instrument.** Repository-level corrections address findings **3, 4, 5, 7, 8,
10, 11, 12, 14, 15, 16, 17, 18, 19 and 20**. This means the identified circuit,
geometry, tooling or documentation defect is corrected; it does not mean the
resulting physical product has been qualified.

Five findings are only partially addressed:

| Finding | Completed here | Required to close |
|---|---|---|
| 1 — Battery safety | Selected LP702040 drawing FD_3245_20; J2 is three-wire; the 103AT-2 drives TS and an ADC; CE now defaults disabled until firmware validates the pack's tighter 0–45 °C range; charge current is bounded; default timers remain enabled. | Confirm the production lot, implement the firmware gate and pass `51-power-safety-qualification.md`; no enclosed charging before then. |
| 2 — Manufacturing readiness | Draft outputs clearly separated from gated release. | Finish A's 59 and B's 60 unconnected items, resolve release warnings, and review the finished layouts. |
| 6 — USB current | EN2 is hard-low; EN1 has a 100 kΩ pull-down and IO21 control. The locked policy is USB100 by default and USB500 only while configured by a data host. Firmware behavior and tests are specified. | Implement the ESP-IDF state machine and pass representative-host/fault measurements in `51-power-safety-qualification.md`. |
| 9 — Battery fit | Both generated enclosures now fit FD_3245_20's 42 × 20.5 × 7.3 mm maximum envelope, reserve XY and swelling allowance, use the shorter PicoBlade header, and meet the target case thickness. | Physically inspect all five packs in both printed cases, including insulation, retention and the 45 ± 3 mm lead path. |
| 13 — Firmware/product behavior | Added the [firmware and acceptance contract](71-firmware-contract.md). | Implement the ESP-IDF application and pass the contract's device tests. |

The [release evidence inventory](../hardware/release-readiness.json) additionally
requires measured rail/runtime, assembly/sourcing, RF and instrument-accuracy
qualification. None of those evidence slots has been filled with assumptions.
The [charge budget](35-power-budget.md) and thermal calculations are planning
models, not measured battery life or accuracy.

The pack/charger architecture and supported USB policy were implemented on 2026-09-09
in response to findings 1, 6 and 9. Their release evidence remains deliberately
empty: selecting and modeling parts is not physical qualification. Remaining
engineering order is to obtain the controlled pack drawing and source samples,
finish routing and J2 assembly review, implement the minimal USB state machine,
then run `51-power-safety-qualification.md` before any enclosed charging and the
revised A/B experiment. The current generated boards remain non-release drafts.

### Verification record — 2026-09-09

`./localPipeline.sh` completed with exit status 0 against committed design
sources at `eafb7d3`, using Python 3.14.7 and KiCad 10.0.6. All 14 pipeline
stages passed; none was skipped.

| Check | Observed result |
|---|---|
| Offline regression tests | 44 passed, including injected electrical, report, packaging and export failures. |
| KiCad negative-rule tests | 2 passed: forbidden VBAT and widened GND in B's island region are rejected. |
| Generator and reproducibility | Zero model-rule errors; schematic, both boards and generated reports regenerate identically. |
| Electrical rules | Zero ERC violations. |
| PCB rules and parity | A: 0 errors, 7 reviewed warnings, 0 parity differences, 59 unconnected items. B: 0 errors, 17 reviewed warnings, 0 parity differences, 60 unconnected items. |
| Mechanical geometry | Four STL parts match XYZ bounds; seated lid/base intersections are empty for both variants. One generated board-retention warning plus the recorded physical fit checks remain open. |
| Documentation and BOM | 19/19 checked figures match the model; BOM generated with 43 lines/43 populated placements. This is not sourcing qualification. |
| Draft export | Four-layer Gerbers, drill files, CPL and STEP produced for both variants. Board and enclosure previews refreshed. |
| Release rejection | `make release-check` exited 2 as expected: A/B warnings and routing gaps plus all seven missing qualification evidence categories blocked release. |

Local diagnostic logs are `_build/review-pipeline.log` and
`_build/review-release-check.log` (ignored build artifacts; rerun the commands to
reproduce). The committed record here preserves the results without treating
temporary logs as release evidence. No hardware was fabricated, powered,
charged, radio-tested or measured during this review. No firmware implementation
or physical qualification is claimed.

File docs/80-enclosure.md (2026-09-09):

# 80 — Enclosure (generated)

<!-- Generated by `make mech` from tools/boardgen/enclosure.py. -->

The case is derived from the board model: outline, sensor position,
antenna keep-out and every connector position are read from it, never
retyped. `mechanical/env-sensor-case.scad` turns these numbers into
solids.

The lid uses a perimeter locating ring. Hold-down reach is measured
from the lid seating face, not from the ring tip; `make mech` checks
the full XYZ mesh extent to catch PCB interference.

Variant B's divider lies wholly inside the physical neck span, with
printing clearance from the body and island; the electrical rule
zone boundary is not used as a mechanical wall position.

The perimeter lip is relieved where it crosses B's divider. The
OpenSCAD `interference` mode intersects the closed lid with the base;
the expected result is empty. This does not prove pack/PCB fit.

USB opening height is centred on the connector body above the PCB,
not on the PCB surface. Cable-shell reach through the recessed wall
still requires a physical fit check with the intended cable.

## Component heights

| Ref | Height | Source |
|---|---:|---|
| SW1 | 3.50 mm | Panasonic EVQ-PU tactile - TBC against the datasheet |
| J2 | 3.40 mm | Molex PicoBlade 53261-0371 drawing, mated height |
| J1 | 3.16 mm | HRO TYPE-C-31-M-12, 8.94 x 7.35 x 3.16 |
| U1 | 2.40 mm | ESP32-C6-MINI-1 datasheet v1.5 S10.1, 13.2 x 16.6 x 2.4 |
| C1 | 1.45 mm | 0805 MLCC, typical maximum |
| C9 | 1.45 mm | 0805 MLCC, typical maximum |
| C10 | 1.45 mm | 0805 MLCC, typical maximum |
| C11 | 1.45 mm | 0805 MLCC, typical maximum |
| L1 | 1.20 mm | Murata DFE201612E, 2.0 x 1.6 x 1.2 |
| U4 | 1.00 mm | VQFN-16 3x3, typical maximum |
| U2 | 0.50 mm | SHT4x DFN, 1.5 x 1.5 x 0.5 |

## Result

| | Variant A | Variant B |
|---|---:|---:|
| Outer size (mm) | 47.0 × 39.2 × 18.8 | 47.0 × 56.2 × 18.8 |
| Internal cavity height | 14.8 mm | 14.8 mm |
| Battery bay below board | 7.3 mm | 7.3 mm |
| Clearance above board | 4.1 mm | 4.1 mm |
| Tallest part | SW1 at 3.50 mm | SW1 at 3.50 mm |
| Modeled maximum pack envelope | 42.0 × 20.5 × 7.3 mm | 42.0 × 20.5 × 7.3 mm |
| Selected pack | LP702040, 550 mAh | LP702040, 550 mAh |
| Selected pack fits modeled bay | yes | yes |
| Vent slots over the sensor | 1 in the lid + 4 in the wall | 2 in the lid + 4 in the wall |
| Lid hold-down pillars | 2 | 0 |
| Chambers | 1 | 2, divided at the neck |
| Solid material beyond the antenna | 2.6 mm | 2.6 mm |

## Selected battery and connector

Both cases are sized for the selected **LP702040 550 mAh** protected pack. Drawing FD_3245_20 specifies 550 mAh minimum, maximum assembled dimensions 42 × 20.5 × 7.3 mm, a Semitec 103AT-2 NTC and a 45 ± 3 mm three-wire Molex 51021-0300 PicoBlade harness. J2 is the mating 53261-0371 right-angle header at 3.40 mm mated height.

The generated case is **18.8 mm** thick. The model reserves 0.5 mm around every pack edge and 1.0 mm above the drawing's maximum pouch thickness for manufacturing tolerance and swelling. The support shelves begin above that allowance; nothing rigid may occupy it.

Incoming inspection must confirm the drawing and cavity order `1=black/-`, `2=yellow/NTC`, `3=red/+` before mating. An assembled lead-bend/retention test remains part of the battery qualification gate.

## Board retention, and a decision coming back around

The board rests on four ribs and is meant to be pinned by short pillars from the lid onto bare copper-free board. The generator searches the placement for room rather than assuming a corner is empty, and finds **2 on Variant A** but only **0 on Variant B** - B's electronics chamber carries all 43 populated parts in a narrower body, and there is no bare board left.

The first attempt put two of B's pillars *on the sensor island*: plastic bridging the lid straight into the thermally isolated part, which would have quietly wrecked the experiment the island exists for. That is now a hard check.

The real fix is two M2 nylon screws through the lid into bosses - and the board has no holes for them, because `40-floorplans.md` decided against mounting holes on the grounds that M-04 forbids metal near the antenna and a nylon boss costs 19 mm² of a 1000 mm² board. That was a reasonable call in the PCB phase and it is now a retention problem in the mechanical phase. Nylon screws are not metal; the antenna objection does not actually apply to them. **Rev 2 should carry two nylon M2 holes in the electronics chamber**, which costs a little copper and solves this cleanly.

## Battery qualification still requires hardware

The selected pack passes the parametric plan-view and height checks in both variants. That is a design check, not evidence that a pouch, its protection board and leads tolerate the printed retention scheme. Before enclosed charging, inspect supplier samples, print and assemble both cases, then run the EDS §5.2 temperature, timer and fault tests.

**Variant A checks:** all pass

**Variant B checks:** 
- ⚠️ only 0 lid hold-down pillar(s) fit - the electronics chamber has no bare board left. The board needs a different retention scheme; see the note below

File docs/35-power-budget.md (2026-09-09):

# 35 — Battery-side power budget

`make power` runs an explicit scenario, not a runtime prediction. Inputs are
usable rated pack capacity, sleep current and integrated **battery-side** charge
per sample/upload. Event charge is additional to the continuous sleep baseline;
include wake, association, retries, TLS, flash writes and shutdown. Measuring at
the battery includes regulator/power-path loss. Do not mix rail-side and
battery-side charge without conversion.

For the default 5/15-minute schedule there are 288 samples and 96 uploads/day.
25 µA continuous sleep consumes 0.6 mAh/day. The selected LP702040 pack is rated
550 mAh; an illustrative 80% usable-capacity assumption permits 4.89 mAh/day
for 90 days. The default illustrative
upload charge is 160,000 µA·s (80 mA for two seconds); with 2,000 µA·s per sample
the scenario exceeds that allowance. These are chosen scenarios, not datasheet
claims or measured performance. Rated capacity does not close E-04: usable
capacity, cutoff loss, aging and event charge must still be measured on the
selected protected pack.

Run `python3 -m tools.power_budget --help` for measured-input overrides. A
negative max_upload_uas means sleep and sampling alone exceed the target.
Runtime must exceed the declared test duration, not merely equal it. Use the
actual calendar interval for a literal three-month claim; 90 days is a planning
approximation. Include aging, temperature, self-discharge and cutoff losses in
usable capacity. Owner: hardware/firmware maintainer; gate: E-04/E-05 closure
with current traces and repeated normal/outage runs, not this calculator.

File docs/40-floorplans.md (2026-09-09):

# 40 — Floorplans A and B

Both boards are emitted from one model (`tools/boardgen/`). The parts, values,
netlist, net classes and design rules are identical; `variants.py` is the only
file that differs between them, and it contains outline, sensor position and
thermal zones — nothing electrical.

| | Variant A | Variant B |
|---|---|---|
| | **A — Compact**, HW A1 | **B — Thermally isolated**, HW B1 |

KiCad renders of the same two files: `img/render-a.png`, `img/render-b.png`.

## Side by side

| | **A — Compact** | **B — Thermally isolated** |
|---|---|---|
| PCB | 30 × 34 mm (1020 mm²) | 28 × 51 mm (1310 mm² incl. island) |
| Layers | 4, FR-4, 1.6 mm | identical |
| Parts | 41 placements | identical |
| Sensor position | bottom edge, board centre | on a 18 × 9 mm island |
| Neck | — | 3.5 × 8.0 mm FR-4, 4 × 0.15 mm traces |
| Nearest heat source to the sensor | **11.3 mm** (D1) | **16.5 mm** (R13) |
| Idealized slab / neck conductance (not actual A/B coupling) | **70 mW/K** | **1.2 mW/K** |
| Hypothetical slab / neck ratio | — | **57×**, not a performance claim |
| Assembly difficulty | identical (single-sided SMT, same stencil apertures) | identical |
| Panel area / PCB cost | lower | ~28 % more area |
| Mechanical risk | none | the neck: 3.5 mm of FR-4 carrying an island |
| Enclosure | one chamber, vents at the sensor edge | two chambers with a dividing wall at the neck |

## What the layout actually decided

**The connectors moved to the side edges.** In B the bottom edge is where the
thermal neck leaves the board, and both variants share one placement table — so
the USB-C receptacle sits on the left edge and the PicoBlade pack header on the right in *both*.
This is a good example of the shared-model discipline paying off: a decision
forced by B automatically applies to A, and the two boards stay comparable.

**The antenna keep-out costs 170 mm².** Espressif ask for ~15 mm clear around
the module antenna. Neither board is 30 mm wider than the module, so in-plane we
give the antenna the **full width of the board for its whole length** and buy the
rest of the clearance from the enclosure. That is ~17 % of variant A's area
spent on a strip with no copper on any layer. It is also the only place on the
board with room for a silkscreen title block, which is where it now lives.

**There are no mounting holes.** M-04 forbids metal fasteners near the antenna;
a nylon M2 boss costs ~19 mm² on a board this size; and the printed enclosure can
register the board on ribs against the USB-C and pack-header cut-outs. Revisit at Rev 2
if that retention proves unreliable.

**Reference designators are not on the silkscreen.** Forty 0402s on 30 × 34 mm
cannot be silk-labelled legibly — KiCad's silk DRC said so, 93 times. The
assembly drawing (`F.Fab`/`B.Fab`, exported to `hardware/outputs/*/assembly/`)
carries every reference. The silkscreen carries what a human needs while holding
the board: name, revision, battery polarity, USB and pogo labels.

## Thermal interpretation

`45-thermal-model.md` compares a hypothetical solid slab with B's thin neck.
The slab has a **112×** copper/FR-4 conductance ratio, but A's actual sensor
quiet zone removes pours on every layer. Neither this ratio nor 57× describes
the actual comparison. The experiment must remain capable of choosing A.

## Why B is not obviously right either

1. **The neck is 3.5 mm of FR-4 holding an island.** Bare-board handling, depanel
   and assembly all apply force there. First bare-PCB inspection has to check it
   (open item EDS-8: 3.0 / 3.5 / 5.0 mm).
2. **Both variants depend on their enclosure.** Chamber walls, ribs, vents and
   battery placement create heat paths omitted by the slab calculation.
3. **28 % more board area, a longer enclosure, and a shape that is harder to
   panelise.** Real money at 20 units, and more at 200.
4. The four island traces are the entire electrical path to the sensor and they
   are 0.15 mm wide with no redundancy. An I²C bus that flakes there is a scrap
   board, not a rework.

## Routing status — stated plainly

Both boards are **partially routed**: **54** ratsnest items on A and **58** on B
with KiCad 10.0.6. What the generator routes, and why:

| | |
|---|---|
| **Sensor island** — 4 nets | They carry a *rule* (0.15 mm, no vias, nothing else near them) that is also written into each `.kicad_dru`, so DRC enforces it against whoever routes the rest. |
| **Power fan-out** | Stubs to In2 plane vias where the router finds clearance; several pads remain unconnected. |
| **GND** | F.Cu/B.Cu pours and stitching, with isolated fragments explicitly tracked as development warnings. |
| **Whatever else it could reach** | Track/via counts are printed by `make gen`; KiCad connectivity is the completion criterion. |

The rest — mostly escapes from the 0.5 mm-pitch charger and the
USB-C receptacle's interleaved D+/D− pairs — is a KiCad session.
`hardware/drc-budget.json` records each variant's count and warning identities.

**Why the router stops there.** It has no rip-up and no shoving: once a net is
placed it stays, so a net routed early can permanently block one routed later.
That is a deliberate trade. A better autorouter exists — freerouting, via
Specctra DSN — but its output is a one-off artifact, and this repository's
central claim is that a rule change regenerates *both* boards identically. Route
by hand or by freerouting once, and the next time the neck width moves, someone
has to do it again and hope they make the same decisions twice.

KiCad DRC on both variants: **0 errors, 0 unreviewed warnings, 0 schematic
parity differences.**

## Prior expectation, to be falsified

75 % on B. The number is a prior, not a result. `50-thermal-ab-test-plan.md`
is how we find out, and it is designed to be able to say "A is good enough" —
which, for a room-comfort sensor that spends 99.9 % of its life asleep and cold,
is a real possible answer.

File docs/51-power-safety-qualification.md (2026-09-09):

# 51 — Battery and USB power qualification

This protocol supplies the missing physical evidence for EDS-9Q and EDS-10Q.
Passing generated ERC/DRC does not satisfy it. Owner: hardware maintainer, with
firmware maintainer for the USB state-machine cases. Raw logs, instrument IDs,
calibration dates, board/pack serials and photos go under
`measurements/power-safety/<run-id>/`; the release manifest links the reviewed
run summary.

Primary sources are the [BQ24074 datasheet](https://www.ti.com/lit/ds/symlink/bq24074.pdf),
[LP702040 drawing FD_3245_20](https://www.li-polymer-battery.com/wp-content/uploads/2021/09/LP702040-550mAh-1032AT-2Molex-51021-0300.pdf),
the [configured LP702040 product page](https://li-polymer-battery.com/3-7v-rechargeable-li-polymer-battery-lp702040-550mah-with-ntc-and-molex-connector/),
and the [Molex 53261 series record](https://www.molex.com/en-us/products/series-chart/53261).
Q1 limits and pinout come from the
[onsemi 2N7002L datasheet](https://www.onsemi.com/pdf/datasheet/2n7002l-d.pdf),
with [Nexperia 2N7002](https://assets.nexperia.com/documents/data-sheet/2N7002.pdf)
as the recorded second source.
The supplier page is not a controlled pack drawing; any conflict is resolved in
favor of the signed drawing obtained with the lot, then reviewed as a design
change if it alters the locked interface.

## Stop conditions

Do not charge a pack in either enclosure until the supplier-document, incoming
inspection, TS fault and current-limit stages below pass on the bench. Stop a
test immediately for swelling beyond the controlled drawing, damaged insulation,
unexpected odor/noise, pack voltage or temperature outside the supplier limits,
reversed/unstable current, or failure of a commanded charge suspension. Isolate
the unit using the lab's lithium-battery incident procedure; do not continue to
collect data from a suspect pack.

## Pack and charger qualification

Use at least five production-intent LP702040 assemblies from the intended lot.

| Stage | Method | Acceptance |
|---|---|---|
| Supplier record | Obtain written confirmation that the lot matches FD_3245_20, including 103AT-2, 45 ± 3 mm AWG-28 UL1571 leads, cavity order and applicable transport-test record. Reconcile the web page's 225 mA and drawing's 275 mA charge limits. | Every field is present and the more restrictive unresolved limit is used. |
| Incoming inspection | Photograph and measure every pack; continuity-check cavity 1 to negative, cavity 3 to positive, and cavity 2 only to the NTC. Measure NTC resistance at a recorded room temperature before mating. | Polarity is `1=black/-`, `2=yellow/NTC`, `3=red/+`; maximum envelope is 42 × 20.5 × 7.3 mm and resistance agrees with 103AT-2 data. |
| Geometric fit | Install each pack in printed A and B bases with the production insulation/retention materials. Inspect the 45 ± 3 mm lead path and connector mating/unmating. Close the lid and run the existing interference check plus physical inspection. | No pinch, sharp bend, abrasion, compression or rigid material occupies the 0.5 mm XY / 1.0 mm Z allowance; the pack cannot reach the antenna or sensor chamber. |
| NTC characterization | Stabilize a pack and calibrated reference at multiple temperatures spanning 0–45 °C. Record pack NTC resistance, ADC code and TS voltage. Establish firmware enable/disable guard bands from the 103AT-2 curve, ADC uncertainty and BQ24074's 72–78 µA TS bias before applying charge current. | Firmware permits CE only when the full temperature uncertainty interval is within 0–45 °C on all five packs; charger TS remains an independent wider backup window. |
| TS/firmware faults | With a battery simulator or protected pack at safe state of charge, open and short the NTC conductor separately; inject stale ADC, conversion-error and watchdog paths; then restore it. Record `CHARGE_ENABLE`, CE, BAT current, `/CHG`, `/PGOOD`, TS and VBUS. Include a no-battery cold attach and slow VBUS ramp to verify startup ordering. | R7 holds Q1 off and R18 raises CE with VBUS before charger operation. Every invalid/fault condition turns Q1 off, releases CE and stops charging; no missing firmware or sensor fault can enable charging. |
| Charge current | At safe pack temperatures and declared initial states of charge, log input current, BAT current/voltage and charger/pack temperature in USB100 and enumerated USB500. | Input never exceeds the respective 100 mA / 500 mA datasheet maximum; BAT charge current never exceeds the design's 223 mA worst-case bound. |
| Termination/recharge | Charge every pack through normal termination, observe recharge behavior after controlled discharge, and repeat across the supplier's allowed temperature range. | No limit from the controlled pack drawing is exceeded; termination and recharge are repeatable and `/CHG` agrees with measured current. |
| Safety timers | Use a battery simulator/electronic load to hold precharge and fast-charge conditions; do not abuse a pouch cell to create timeout. TMR remains physically open. | Precharge timeout occurs within 1440–2160 s and fast-charge timeout within 14400–21600 s, the BQ24074 floating-TMR limits. |
| Enclosed charge | Only after all prior stages pass, run one full charge in each finished A/B enclosure while logging charger, pack, sensor and ambient temperature. | No supplier limit or mechanical stop condition is crossed; data are retained for thermal Test 3. |

## USB source-policy qualification

Use a calibrated USB current/voltage analyzer and at least two USB 2.0 hosts,
two USB 3.x hosts (including USB-C where available), and one charge-only USB-C
source. Test with a normally charged pack, the lowest permitted operating pack
voltage, and no pack where the case permits it. The no-pack case keeps radio off.

| Event | Required state and acceptance |
|---|---|
| Cable attach, reset and boot | `USB_ISEL=0`; total input is at or below 100 mA. |
| Before USB configured | `USB_ISEL=0`, including long enumeration and rejected-device cases. |
| Configured by data host | Firmware may set `USB_ISEL=1`; total input remains at or below 500 mA. |
| Suspend, deconfigure and detach | Firmware clears `USB_ISEL` before/at the transition; no retained 500 mA authorization. |
| Charge-only/unknown source | It never reaches configured state, so `USB_ISEL` remains low and input stays at or below 100 mA. |
| Watchdog reset or induced USB-stack crash | External R8 returns EN1 low without firmware; input returns to the USB100 bound. |
| Low-pack radio transmit after configuration | Source remains within 500 mA and the battery safely supplies any power-path supplement current. |
| Missing/depleted pack before configuration | Firmware does not start radio; it reports/records a bounded power-policy fault where possible. |

Capture GPIO, VBUS, input current, VBAT, BAT current, `PG_N`, `CHG_N` and USB
stack state on one time base. A table saying “worked” is not evidence. Any
source-specific workaround becomes a documented supported-source restriction,
not an unrecorded exception.

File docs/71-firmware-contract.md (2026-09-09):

# 71 — Firmware implementation and acceptance contract

**Not implemented.** There is no ESP-IDF application in this repository yet.
The hardware build must not report F-03…F-12 as passing. This contract defines
the work needed to turn the boards into instruments; a contract is not firmware.
Owner: firmware maintainer. Record device-test evidence before the firmware
entry in `hardware/release-readiness.json` can close.

## Acquisition and trustworthy telemetry

Wake → inspect reset cause → acquire sensor with radio stopped → check read/CRC
→ persist sample → optionally connect/upload → stop radio → deep sleep.
Use bounded timeouts and retries. Failure must still reach sleep. Never substitute
zero, a previous value, or an unmarked stale value for a failed sensor read.

Every sample carries schema version, serial (`ENV-00xx` per F-11), variant,
hardware revision, firmware hash, boot identity, monotonic sequence, acquisition
time, clock-valid flag, units, temperature/RH, battery voltage, USB-present and
charging states, and quality flags. Unavailable values are null. Label USB-present
readings thermally suspect even after charging terminates; retain a cooldown
quality state whose duration is established by Test 3. Batch receive time must
never overwrite acquisition time. The consumer can show last-seen age and
quality without inventing accuracy from a numeric payload.

Persist at least 500 measurements in a bounded journal with CRC and recovery
from power loss during writes. Delete only after acknowledgement under the
defined MQTT delivery contract. Duplicate delivery is allowed and deduplicated
by serial/boot/sequence. Declare and count overflow; never silently overwrite
unacknowledged samples. Bound outage radio activity with exponential backoff and
a maximum energy budget, so an absent AP cannot exhaust the battery.

## Provisioning, credentials and updates

BLE provisioning requires a physical button action and per-device proof of
possession, expires after a bounded window, and is disabled in normal sleep.
Explain provisioned, connecting, queued/offline and failed states using brief LED
patterns; leave the LED off in sleep. Factory reset requires a deliberate long
press and removes credentials while preserving the immutable serial.

Use unique device credentials and broker permissions scoped to that serial;
authenticate the broker certificate and hostname. Define trustworthy time
bootstrap before certificate validation; an unset clock must not disable TLS
checks. Never print credentials or commit private keys. Store secrets using the
selected ESP-IDF protection features, and document provisioning/recovery.

OTA accepts only authorized signed images for this hardware, verifies before
activation, keeps a bootable rollback image, and marks the new image healthy
only after self-test. Test interrupted download, interrupted activation, corrupt
and unsigned images, wrong hardware, and a crashing image. Key lifecycle and
irreversible eFuse choices need a reviewed production procedure and hardware
tests; no key-burning operation is part of this review.

## USB input-current state machine

Charging is separately fail-safe. `CHARGE_ENABLE` is IO18 and drives Q1's gate;
external R7 holds the gate low at reset. Separate R18 pulls BQ24074 `/CE` to
VBUS, so charging is disabled before the MCU rail exists. After `PG_N` asserts,
sample `PACK_TS` on IO3/ADC1_CH3 repeatedly,
convert using the Semitec 103AT-2 curve and the measured BQ24074 TS bias, and
drive `CHARGE_ENABLE` high only when the entire uncertainty interval lies inside the pack
drawing's 0–45 °C charge range. Release CE immediately on out-of-range,
implausible/open/short readings, ADC error, stale sample, watchdog warning,
suspend or loss of VBUS; clearing the GPIO turns Q1 off and releases CE high.
Thresholds and hysteresis are generated from reviewed
calibration constants, not raw ADC magic numbers. Until this code and its tests
exist, the board must remain in its default charging-disabled state.

`USB_ISEL` is IO21 and drives BQ24074 EN1. Configure it as an input/high-Z or
drive it low from the first startup instruction; the external 100 kΩ pull-down
then guarantees USB100. Drive it high only from the native USB stack's
**configured** callback. Clear it before acknowledging suspend,
deconfiguration or detach, and on every USB-stack error path. A charge-only
adapter never configures the USB device and therefore remains at 100 mA.

Do not infer source current from `PG_N`, VBUS voltage or the Type-C Rd resistors.
They establish presence/attachment, not host configuration. Do not start Wi-Fi
from USB100 with a missing or deeply depleted pack; report a power-policy fault
and remain in bounded low-power/debug operation. Persist no “500 mA allowed”
state across reset. Telemetry and factory output must expose the selected
USB100/USB500 state alongside USB-present and charging state.

## Required executable acceptance cases

Measure-before-radio ordering; sensor timeout/CRC failure; flash write power
loss; 501 queued records; duplicate/missing MQTT acknowledgement; AP and broker
outages; bad broker certificate/hostname; expired provisioning; unauthorized OTA;
brownout during OTA; rollback; button factory reset; USB-present cooldown; deep
sleep timing and energy; battery ADC calibration; fixture PASS/FAIL records;
USB100 at reset/charge-only attach; USB500 only after configuration; USB100
before suspend/deconfigure/detach; firmware-crash fallback; low-battery TX while
recording source current; CE disabled at reset; valid-temperature charge enable;
hot/cold/open/short/stale-NTC disable and watchdog recovery.

The divider's Thevenin resistance is 1.1 MΩ with 100 nF: RC = 110 ms. A 20 ms
delay is not startup settling. Wait at least 5 RC (550 ms, an engineering settling
target) after first energization, then verify ADC acquisition and calibration
against an external meter across the selected pack range. The divider remains
powered during normal deep sleep; repeated wakeups need not repeat startup delay
unless discharge or power switching occurred.

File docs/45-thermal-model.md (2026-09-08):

# 45 — Thermal Screening Model (generated)

<!-- Generated by `make thermal` from tools/boardgen/thermal.py. Do not edit:
     change the model, re-run, commit both. -->

Purpose: compare idealized conduction paths and expose assumptions. Neck
dimensions come from the generated model, but the A-sized solid copper slab
does not represent A's actual copper-free sensor zone. This calculation cannot
rank the finished instruments or predict their temperature errors.

k(FR-4) = 0.30 W/m·K · k(Cu) = 385 W/m·K · 35 µm copper · 1.6 mm FR-4

### Hypothetical slab comparison — not the routed board

A's generated sensor quiet zone excludes pours on all four layers.
The full-width copper slab below therefore overstates its copper path.
Its ratio is NOT actual A/B isolation or a prediction of accuracy.

| Idealized path | Conductance |
|---|---:|
| Full-width A-sized slab, FR-4 | 0.62 mW/K |
| Full-width A-sized slab, copper | 69.2 mW/K |
| Full-width slab total | 70 mW/K |
| B neck FR-4 | 0.21 mW/K |
| Four 0.15 mm traces | 1.01 mW/K |
| Neck total | 1.22 mW/K |
| Hypothetical slab / neck ratio | 57× |

Thickness and trace width come from the shared electrical model.
Conductivity values and convection are explicit engineering assumptions,
not measurements of this laminate or enclosure.

### Illustrative convection sensitivity

Coupling = G / (G + 2 h area). The two-face assumption ignores case
obstruction. h values are scenarios, not classified room conditions.

| h (W/m²·K) | Slab coupling | Neck coupling |
|---:|---:|---:|
| 5 | 0.97 | 0.43 |
| 10 | 0.95 | 0.27 |
| 25 | 0.89 | 0.13 |

No measured electronics-to-ambient thermal resistance exists to
derive a chamber temperature rise. Air exchange, rib conduction,
radiation and transients are omitted. No kelvin error or assertion
that A cannot win is justified. Tests 1–4 establish the real result.

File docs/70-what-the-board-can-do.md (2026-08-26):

# 70 — What This Board Can Do

The question behind this document: *once the hardware exists, what do I get by
writing only software?*

The short answer is that the board is a **general-purpose 2.4 GHz wireless node
with a laboratory-grade hygrometer and a battery**, and that the radio silicon
is considerably more capable than the product it was chosen for. Most of the
list below costs firmware and nothing else.

---

## 1. The raw capability surface

What the parts physically give you, before any decisions:

| | |
|---|---|
| **Compute** | RISC-V @160 MHz, 4 MB flash, plus a **separate low-power RISC-V core** that can run while the main core sleeps |
| **Radios (all three, same chip)** | Wi-Fi 6 (802.11ax, 2.4 GHz) · Bluetooth LE 5.3 · **IEEE 802.15.4** |
| **Sense** | ±0.1 °C / ±1.0 %RH, factory calibrated, PTFE filtered, with an on-chip heater |
| **Power** | 1S LiPo, USB-C charge with power path, ~7 µA deep sleep, battery voltage on an ADC |
| **Know its own state** | USB present, charging, battery volts, RSSI, reset reason |
| **Talk to you** | one LED, one button, native USB serial/JTAG, 16 pogo test pads |
| **Grow** | 8 spare GPIOs and the I²C bus brought out to test pads |

---

## 2. Three radios, one board — this is the big one

The ESP32-C6 was chosen for Target Wake Time. What comes with it is that the
*same board, unmodified*, can be any of these depending on what you flash:

| Firmware | What it becomes | Why you'd want it |
|---|---|---|
| **Wi-Fi + MQTT/TLS** | the baseline: talks to Home Assistant, InfluxDB, Grafana, or anything | no extra infrastructure, works today |
| **Matter over Thread** | a native Apple Home / Google Home / Alexa sensor | no custom app, no cloud account, no bridge — it just appears |
| **Zigbee** | a Zigbee2MQTT / deCONZ sensor | joins an existing Zigbee mesh, very low power |
| **BLE sensor / beacon** | broadcasts readings as BLE advertisements | phone reads it directly, no network at all; months of battery |
| **ESP-NOW** | peer-to-peer link to another ESP32 | no router, no association, milliseconds to send, ideal for a shed or garage out of Wi-Fi range |
| **Thread + Wi-Fi at once** | a sensor *and* a Thread border router | one node covers both worlds |

That is not a hardware roadmap. It is a firmware choice, one build flag deep.
It is also the strongest argument for having spent the extra euro on the C6
rather than the C3 — the C3 can do only the first and the fourth.

**Battery consequence.** Thread and BLE are dramatically cheaper per message
than Wi-Fi, because there is no association, no DHCP and no TLS handshake. If
runtime ever disappoints on Wi-Fi, Matter-over-Thread is the escape hatch, and
it needs no new PCB.

---

## 3. What one sensor measures once you do the arithmetic

The SHT45 reports two numbers. Those two numbers, plus air pressure assumed at
sea level, give you a surprising amount:

- **Dew point** — the temperature at which condensation starts on a surface.
- **Absolute humidity** (g/m³) — the honest measure of "how much water is in
  this air". Unlike RH, it does not change when the room warms up, so it is what
  you compare between two rooms.
- **Vapour pressure deficit** — the number greenhouses and grow tents actually
  control.
- **Mould risk** — surface RH on a cold wall, from indoor dew point and an
  assumed wall temperature. This is the number that tells a German flat owner
  whether to open a window, and it is genuinely useful.
- **Comfort index / "should I ventilate now?"** — comparing indoor absolute
  humidity to an outdoor feed makes airing-out advice correct rather than
  folklore: in winter, cold outdoor air is *drier* even at 90 %RH.
- **Rate of change** — d(T)/dt shows heating cycles, open windows and doors
  opening, without any extra sensor.

The on-chip **heater** is a real instrument, not a footnote: pulse it and watch
the RH recover, and you get a self-check of whether the sensor is still
breathing or has been sealed in by dust.

---

## 4. What the board knows about itself

Every payload can carry, for free:

`battery_v` · `charging` · `usb_present` · `rssi_dbm` · `firmware` ·
`reset_reason` · `uptime` · `wifi_retries` · `queued_samples`

That turns a fleet of twenty into something you can operate: which unit is
about to go flat, which one sits at the edge of coverage, which one rebooted
last night. It also makes the A/B experiment possible at all — `charging` is
what lets us mark readings as thermally suspect.

**A quietly useful trick:** a unit left plugged in reports `usb_present`. When
mains fails, the flag drops and the node keeps running on its own battery — so
the fleet doubles as a **power-outage logger** with timestamps, for free.

---

## 5. The low-power core changes what "always on" means

`SDA`/`SCL` are on IO6/IO7 deliberately: those are the pins the **LP I²C**
peripheral can reach. That means firmware can eventually read the sensor from
the low-power core while the main CPU stays powered down, and only wake the big
core when something is worth reporting.

Concretely, that unlocks:
- **fast sampling, rare transmission** — 10-second resolution on a battery,
  because 10-second sampling no longer means 10-second wakeups;
- **event-driven reporting** — wake the radio only when temperature moves more
  than a threshold, or when dew point crosses a line;
- **min/max/mean between uploads** instead of instantaneous snapshots, which is
  what you actually want from a 15-minute reporting interval.

None of that needs a hardware change. All of it needs firmware.

---

## 6. Local storage: it survives your network

4 MB of flash holds a ring buffer of ≥ 500 measurements (requirement F-08).
With a compact record that is comfortably **days** of history at the default
interval. The router can reboot, the broker can be down, you can move house —
the data queues and drains when the network comes back.

Room enough as well for two OTA slots, so updates are safe and reversible.

---

## 7. The eight spare pins and the exposed I²C bus

Free GPIOs: **IO3, IO4, IO5, IO14, IO18, IO21**, plus **IO0/IO1** held in
reserve for an optional 32.768 kHz crystal. `SDA` and `SCL` are on test pads
TP12/TP13.

That is a real extension port. Without touching the PCB you could hang on:

| Add | Bus | What it turns the node into |
|---|---|---|
| SCD40/SCD41 | I²C | a **CO₂** monitor — the single most useful indoor-air number after temperature |
| LPS22HH / DPS310 | I²C | barometric pressure, and with it altitude and weather trend |
| SGP41 / BME688 | I²C | VOC / air-quality index (on the *bus*, away from our sensor — which is exactly where a heated part belongs) |
| VEML7700 / LTR-303 | I²C | ambient light, occupancy inference, blind automation |
| Reed switch or PIR | GPIO | door/window state, or presence |
| E-paper display | SPI on spare GPIOs | a battery-powered room display |

Note the pattern: **the thing this design deliberately refused to put next to
its own thermometer — a heated gas sensor — it can still support, on a wire,
where the heat belongs.** That was the point of rejecting the BME680 rather
than the point of rejecting air quality.

---

## 8. What it honestly cannot do

Worth being explicit, so nobody plans on it:

- **No display, no sound, no motion sensing** as built.
- **No mains metering, no relay, no actuator.** It observes; it does not switch.
- **No GPS, no cellular, no LoRa.** 2.4 GHz only, indoor range.
- **No CO₂, VOC or pressure** without adding a part (§7).
- **No external antenna** — that is the `-1U` module variant and a different
  footprint.
- **Wall-clock time survives a reset but not a flat battery**; there is no
  coin-cell RTC. Time comes from the network on boot.
- **±0.3 °C is a system target, not a promise**, and it is the whole reason
  Variant B exists. Firmware cannot fix a thermal path.
- **It is not certified.** Pre-certified module, personal project, no RED/EMC
  campaign. That is a legal boundary, not a technical one.

---

## 9. A reasonable firmware order

If you want the shortest path from bare board to something useful:

| Stage | What you write | What you get |
|---|---|---|
| 1 | blink, USB console, I²C scan | the board is alive and the sensor answers |
| 2 | SHT45 driver + ADC read | temperature, humidity, battery over serial |
| 3 | deep sleep + RTC wake | measured battery life; the first real number |
| 4 | Wi-Fi + MQTT/TLS | readings in Home Assistant |
| 5 | BLE provisioning + NVS | no hard-coded credentials; a device you can hand to someone |
| 6 | ring buffer + bounded retries | survives the router rebooting |
| 7 | factory-test mode on `TEST_MODE` | twenty units become a production run |
| 8 | OTA | you stop unscrewing enclosures |
| 9 | derived metrics (§3), LP core (§5) | it stops being a thermometer and starts being useful |

Stages 1–4 are a weekend. Stages 5–8 are what turn ten prototypes into twenty
deployable devices, and they are where the effort actually goes.

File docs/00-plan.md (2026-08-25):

# 00 — Master Plan (distilled)

One page. Everything else in `docs/` is detail hanging off this.

## The product

A battery-powered indoor temperature/humidity node: ESP32-C6 + SHT45, USB-C
charged 1S LiPo, deep-sleep duty cycled, MQTT/TLS telemetry, BLE provisioning,
3D-printed enclosure. Target: >3 months per charge, ±0.3 °C / ±3 %RH **as a
finished product in its case** — not as a datasheet number.

## The central bet

> One electrical platform. Two physical implementations. Decide by measurement.

**Variant A — Compact.** Everything on ~30 × 34 mm. Smallest possible node.
**Variant B — Thermally isolated.** ~28 × 48 mm, the sensor sits on a milled
tongue joined by a narrow FR-4 neck with four thin traces and *no* inner-layer
copper; the enclosure splits into a sensor chamber and an electronics chamber.

Both share schematic, netlist, BOM and firmware. Build 5 + 5, put them side by
side, measure the systematic offset, then pick. Prior expectation: B wins with
~75 % probability — but the point is that we will have the data.

## Phase plan and gates

| Phase | Work | Deliverable | Gate |
|---|---|---|---|
| **0** | Requirements | `10-requirements.md` | targets agreed |
| **1** | Component selection | `20-component-selection.md` | ✅ done |
| **2** | Electrical design spec | `30-electrical-design-spec.md` | every value has a source |
| **3** | Schematic (shared) | `hardware/schematic/` | ERC clean, review checklist signed |
| **4** | Libraries | verified symbols/footprints | pin-1, rotation, land pattern checked vs datasheet |
| **5** | Floorplans A + B | `40-`/`41-floorplan-*.md`, `boardgen` model | envelopes fit the enclosure concept |
| **6** | Layout A ∥ Layout B | two `.kicad_pcb` | DRC clean, RF + thermal keepouts honoured |
| **7** | Enclosures A + B | `mechanical/` OpenSCAD | vents at the sensor, 15 mm antenna clearance |
| **8** | Production package | `hardware/outputs/rev-a1`, `rev-b1` | gerber/drill/BOM/CPL/STEP, DFM reviewed |
| **9** | Prototype order | 5 × A + 5 × B PCBA | quotes compared, boards on order |
| **10** | Firmware bring-up | ESP-IDF app + factory test | self-test PASS on every board |
| **11** | **A/B thermal experiment** | `50-thermal-ab-test-plan.md` + data | **the decision gate** |
| **12** | Rev 2 | corrected board + enclosure | issues from Rev 1 closed |
| **13** | 20-unit series | serialised, tested, deployed | 20 test records in `measurements/` |

Phases 6 and 7 run **A and B in parallel** — that is the whole point of the
parametric generator in `tools/boardgen/`: both boards are emitted from one
model, so a rule change cannot silently apply to only one variant.

## Schedule (focused part-time)

W1 requirements + parts · W2 schematic + libraries · W3 layout A∥B + enclosure
concept · W4 DRC/DFM + order prototypes · W5–6 firmware, backend, fixture,
printed cases · W6–7 bring-up, power, RF, **thermal A/B** · W8 Rev 2 ·
W9–10 Rev 2 build + verify · W11 freeze · W12–13 build/program/test the 20.

≈ 8–13 weeks clean sheet → tested small series.

## Budget envelope (planning only, not a quote)

Prototype programme (5+5, boards + batteries + cases + accessories):
≈ €300–600 low-cost route, ≈ €500–1100 EU-centric route.
Final 20 units: ≈ €20–45 per finished unit, excluding engineering time and
formal compliance.

## Top risks

| Risk | Mitigation |
|---|---|
| **Thermal bias** (the product-defining risk) | sensor island, thin neck, no inner copper, chamber wall, measure-before-radio, reduced charge current — and Variant B exists precisely to bound it |
| **Charger heat** ≥ radio heat | 100–250 mA charge current, physical separation, charging-state flag in telemetry |
| Battery life | deep sleep + bounded retries + batched uploads + TWT; measured, not assumed |
| RF range in case | module antenna keep-out, no LiPo behind the antenna, range test in the finished enclosure |
| RH contamination | filtered sensor variant, no-clean flux, material rules, heater schedule |
| 20 inconsistent handbuilds | turnkey PCBA, frozen BOM, pogo fixture, factory-test firmware, serial numbers, stored records |

## Non-goals for Rev 1

No rigid-flex, no BGA, no blind/buried vias, no 0201, no custom RF, no
mains power, no display, no injection moulding, no formal RED certification
campaign (module pre-certification + documented assessment only), no
double-sided assembly, no fuel-gauge IC.

## Success criterion

Not "a PCB that works". A platform that can be **rebuilt, re-measured and
improved without losing its design history**. Rev 1 is an experiment. Rev 2 is
an engineering product. The 20-unit run is the first controlled series.

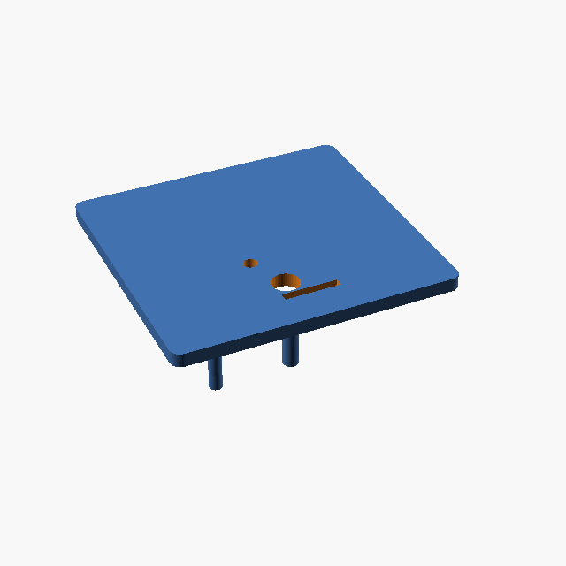
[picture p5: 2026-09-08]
docs/img/case-a-lid.png

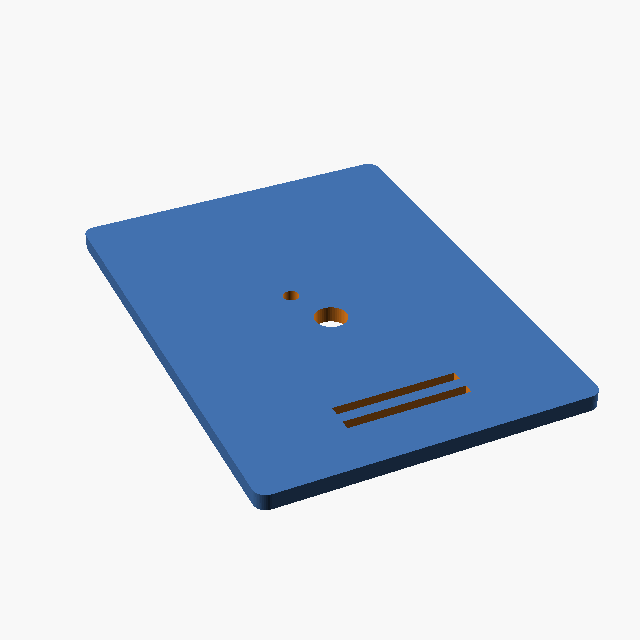
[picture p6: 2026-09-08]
docs/img/case-b-lid.png

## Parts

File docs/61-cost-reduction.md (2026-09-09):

# 61 — Cost Reduction (generated)

<!-- Generated by `make cost` from tools/cost.py. Do not edit. -->

`60-manufacturing-cost.md` costs the design as drawn and stays as it is. This
file asks the separate question: **what would actually make it cheaper, and what
does each saving cost us?**

Same rate table, same researched sources, same caveat — planning estimates, not
quotes.

## The ladder

Each row includes the ones above it.

| Change | Assembly (USD) | Per finished unit | Saved |
|---|---:|---:|---:|
| Baseline — two separate orders | $84–118 | €26.28–47.58 | — |
| Panelise A and B on one panel | $52–70 | €22.55–41.32 | 14–13 % |
| + all-SMD USB-C, fewer extended parts | $33–43 | €20.45–38.37 | 22–19 % |
| + SHT40-AD1F instead of SHT45-AD1F | $33–43 | €18.70–36.26 | 29–24 % |

## Why each one works

**Panelise A and B on one panel.** A and B carry the **identical BOM**, so one panel means one setup, one stencil and one feeder load instead of two. Costs one panel fee ($8.21) and buys back everything else.

**+ all-SMD USB-C, fewer extended parts.** A fully-SMD USB-C receptacle removes the 4 through-hole shield lugs, and with them the hand-soldering line entirely. Sourcing the connector, inductor, button and battery header from the basic library halves the per-part feeder fees.

**+ SHT40-AD1F instead of SHT45-AD1F.** Keeps the PTFE membrane — the part that protects the multi-year measurement — and drops only the accuracy bin, ±0.2 °C / ±1.8 %RH instead of ±0.1 / ±1.0. Same footprint, same I²C address, same driver.

## The single biggest lever is free

Panelising A and B together saves roughly
$32 on the assembly line and costs
nothing in the design. It works only because of the decision made at the very
start — *one electrical platform, two physical implementations*. Two genuinely
different boards could not share a feeder setup.

There is one condition, and it belongs on the order: **the panel rails and
break-off tabs must not sit in the antenna keep-out or across Variant B's
3.5 mm neck.** A tab in the neck puts a stress riser at the weakest point of
the board. See `62-fabrication-3-boards.md`.

## What we are deliberately not doing

| Change | Saves | Why not |
|---|---:|---|
| ESP32-C3-MINI-1 instead of C6 | ~$1.60–1.70/board | Loses 802.15.4 and TWT — that is Thread, Zigbee and Matter gone, which is most of what `70-what-the-board-can-do.md` promises. One euro is the cheapest option this project buys. |
| MCP73831 instead of BQ24074 | ~$0.30/board | Loses the power path, so the load hangs off the cell while charging, and loses the NTC input. Different footprint too. Bad trade at any price. |
| SHT40-AD1B (no membrane) | ~$1.20/board more than the -AD1F | Contamination is the dominant multi-year failure mode. Removing the filter to save a euro is exactly the saving that costs you the product in year three. |
| Drop the LED and button | ~$0.30/board | Provisioning and status would move to USB-only. Not worth it. |
| 3 + 3 prototypes instead of 5 + 5 | ~4 × board BOM | Statistically, this is the expensive one. See below. |

## About building fewer prototypes

Cutting 5 + 5 to 3 + 3 saves roughly
$37–62 of components — real money,
but the smallest lever on this page, and it is the only one that costs
*information* rather than features.

`50-thermal-ab-test-plan.md` already says five samples support a difference with
a range, not a p-value. With three, the within-group range is estimated from
three numbers, and a single outlier — one bad solder joint on one sensor, one
unit sitting nearer a radiator — moves the group mean enough to flip the
decision gate. The gate's 0.15 °C and 0.3 °C thresholds were chosen assuming
n = 5.

If budget forces it: **build 3 + 3, but treat the result as a screen rather than
a decision.** If A and B separate by more than a degree it will be obvious with
three. If they separate by two tenths, three units cannot tell you that, and the
honest response is to build more before choosing — which costs more than doing
it once with five.

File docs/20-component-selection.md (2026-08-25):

# 20 — Component Selection Trade Study (sensor + MCU)

Status: **decided for Rev 1**, revisit at the Rev 2 gate
Date: 2026-08-25
Supersedes: the provisional picks in `docs/vision.md` §1 / §4 / §5

The vision document *assumed* SHT40 + ESP32-C6-MINI-1. This document tests that
assumption against the alternatives, including the ones explicitly raised in
review: **Bosch BME280/BME680**, other **ESP32 variants**, and **long-term
(multi-year) behaviour** rather than day-one accuracy.

---

## 0. The decision criteria

For *this* product, in priority order:

| # | Criterion | Why it dominates |
|---|---|---|
| 1 | **Temperature accuracy at the die**, incl. self-heating | The whole product exists to report temperature. A ±0.5 °C part makes the entire A/B thermal experiment unmeasurable — our expected A-vs-B difference is of the same order. |
| 2 | **Multi-year drift** | Devices get installed and forgotten. A sensor that is right in week 1 and 4 %RH wrong in year 3 has failed. |
| 3 | **Sleep current & measurement energy** | Target > 3 months on 500–1000 mAh. |
| 4 | **Contamination resistance** | Reflow flux, outgassing plastics, dust. This is the #1 cause of permanent RH offset in the field. |
| 5 | Availability / assembly (JLCPCB-class) | 5 + 5 then 20 units, turnkey. |
| 6 | Size | Matters for A. It is *criterion 6*, not criterion 1. |

Note criterion 1 vs 6: the vision doc's Approach A optimises for size. This
trade study deliberately does not.

---

## 1. Humidity / temperature sensor

### 1.1 Candidates

| Part | T accuracy (typ) | RH accuracy (typ) | T drift | RH drift | Package | Filter option | Notes |
|---|---|---|---|---|---|---|---|
| **Sensirion SHT40** | ±0.2 °C | ±1.8 %RH | <0.04 °C/y (max) | <0.25 %RH/y typ, <0.5 max | DFN 1.5×1.5×0.5 | SHT40-BD1B / SF2 cap | baseline in vision.md |
| **Sensirion SHT45** | ±0.1 °C (5–60 °C) | ±1.0 %RH (20–70 %) | <0.04 °C/y | <0.25 %RH/y | DFN 1.5×1.5×0.5, **pin-compatible** | **SHT45-AD1F = integrated PTFE membrane** | strictly better bin of the same die |
| Sensirion SHT43 | ±0.2 °C | ±1.8 %RH | **<0.01 °C/y** | <0.25 %RH/y | same | — | temperature-stability bin |
| **TI HDC3022** | ±0.1 °C class | **±0.5 %RH** | — | **0.19 %RH long-term** | 2.5×2.5 DEJ | **IP67 PTFE cover integral**, 99.99 % @100 nm | + on-chip *offset error correction* for ageing/contamination |
| Bosch BME280 | **±0.5 °C** (0–65 °C) | ±3 %RH | — | **0.5 %RH/y** | LGA 2.5×2.5×0.93 | none | adds pressure |
| Bosch BME680/688 | ±0.5 °C (+ heater self-heat) | ±3 %RH | — | — | LGA 3.0×3.0 | none | adds VOC gas, needs BSEC blob |
| Aosong AHT20/DHT-class | ±0.3 °C | ±2 %RH | poor/unspecified | poor | — | none | not considered further |

Sources: Sensirion SHT4x datasheet v7.x; SHT45-AD1F product page; TI HDC3022
datasheet; Bosch BST-BME280-DS002.

### 1.2 Why **not** BME280 — the honest version

The BME280 is a fine part and it is everywhere, but it is the wrong part *here*,
for three independent reasons:

1. **±0.5 °C beats our experiment.** The A/B question we are trying to answer is
   "how many tenths of a degree does compactness cost?". With a ±0.5 °C sensor,
   unit-to-unit spread swamps the effect we are measuring. We would need to
   individually calibrate all 10 prototypes against a reference just to run the
   test — which is the cost we were trying to avoid.
2. **±3 %RH nominal, 0.5 %RH/y drift.** After 3 years you are at ±4.5 %RH
   worst-case before enclosure effects. And RH error is *amplified by
   temperature error*: near 90 %RH, 1 °C of thermal bias ≈ 5 %RH of humidity
   error (Sensirion design guide). A part that is worse on *both* axes
   compounds, it does not average out.
3. **Documented field behaviour.** Independent side-by-side testing repeatedly
   reports BME280 units running 1–2 °C hot and, in bad cases, 15 %RH low against
   a bench of other sensors. Some of that is self-heating in the host design —
   which is exactly the failure mode this product is built to avoid — but it
   tells you the part has little margin to give away.

**Pressure is not a reason to pick it.** If barometric pressure is later wanted,
add a dedicated pressure sensor (e.g. LPS22HH/DPS310) on the same I²C bus for
~€1 — do not degrade the primary measurement to get a free secondary one.

**BME680/BME688 are actively disqualified.** The VOC gas element is a hotplate
that runs at 200–400 °C in pulses on the *same die* as the temperature and
humidity elements. Putting a deliberate heater inside a battery-powered
temperature sensor is a contradiction in terms; it also costs mA-scale current
and requires Bosch's closed-source BSEC binary, which conflicts with §3 of
`AGENTS.md`. If air quality is wanted later, it belongs on a separate,
mains-powered node.

### 1.3 The real contest: SHT45-AD1F vs HDC3022

This is close, and both are defensible.

| | **SHT45-AD1F** | **HDC3022** |
|---|---|---|
| RH accuracy | ±1.0 %RH | ±0.5 %RH |
| T accuracy | ±0.1 °C | ±0.1 °C class |
| Long-term RH | <0.25 %RH/y | 0.19 %RH stated |
| Contamination | integrated PTFE membrane | integrated IP67 PTFE cover |
| Ageing correction | on-chip heater (condensation/creep recovery) | **on-chip offset error correction** |
| Size | **1.5×1.5×0.5 mm** | 2.5×2.5 mm |
| Ecosystem | ESP-IDF + Sensirion drivers everywhere; Sensirion publish the definitive PCB/enclosure design guide this whole product is built on | good TI docs, thinner hobby/IDF ecosystem |
| Second source | SHT40/41/43/45 pin-compatible family | HDC3020/3021/3022 family |

**Decision: SHT45-AD1F, with SHT40-AD1B as the drop-in cost-down option and
HDC3022 as the qualified second source.**

Rationale:
- The SHT4x family gives us a **pin-compatible accuracy ladder** (SHT40 →
  SHT43 → SHT45) on *one footprint*. We can populate different bins across the
  10 prototypes without a board change — which is itself useful experimental
  freedom.
- Sensirion's design-in guidance (slots, copper removal, thin necks, chamber
  separation) is the literal basis of Variant B. Using their sensor keeps our
  design and our reference document aligned.
- The **-AD1F filter membrane directly addresses criterion 4**, which is the
  dominant long-term failure mode. This is the single most important upgrade
  over the vision doc's bare SHT40 and it costs about €1.
- HDC3022's ±0.5 %RH and offset-correction are genuinely attractive; it stays on
  the BOM as the alternate and as a candidate for the Rev 2 gate if our
  prototypes show RH creep.

**Change vs. vision.md:** SHT40 (bare) → **SHT45-AD1F (filtered)**. Same
footprint, same I²C address (0x44), same driver, ~€1–2 more per unit,
substantially better on the two criteria that actually matter over 3 years.

### 1.4 Long-term usage measures (independent of part choice)

These are firmware/process items, tracked in the EDS and the firmware backlog:

- **Periodic heater pulse.** SHT4x has an integrated heater specifically for
  removing condensation and reversing RH creep. Schedule a low-duty pulse
  (e.g. 200 mW / 100 ms, once per day, *and always after a >80 %RH excursion*),
  then discard readings for a defined cool-down. Energy cost is negligible;
  it measurably extends calibrated life.
- **No-clean flux, no aqueous wash near the sensor, sensor placed last** in the
  assembly sequence where the vendor allows it; sensor kept in its ESD/dry bag
  until placement. Contamination during *assembly* is the most common cause of
  a permanent offset on an otherwise perfect design.
- **Enclosure materials matter.** No silicone (siloxane poisoning), no
  fresh-printed PLA/ABS outgassing directly against the sensor cavity; bake or
  age printed parts before final assembly. Specify materials in the mechanical
  spec, do not leave it to whoever prints the case.
- **Annual field check.** Each device reports firmware version and a
  `sensor_health` field; a 10-minute side-by-side against a reference at
  deployment gives every unit an as-installed offset record.

---

## 2. MCU / radio

### 2.1 Candidates

| Part | Radio | Deep sleep | Why / why not |
|---|---|---|---|
| **ESP32-C6-MINI-1** | Wi-Fi 6 (11ax) 2.4 GHz, BLE 5.3, **802.15.4** | ~7 µA | **chosen** — see below |
| ESP32-C3-MINI-1 | Wi-Fi 4, BLE 5.0 | ~5 µA | cheaper (~€1 less), same 13.2×16.6 module outline, mature. But no TWT, no Thread/Zigbee/Matter path. |
| ESP32-H2-MINI-1 | **802.15.4 + BLE only, no Wi-Fi** | ~7 µA | *the best battery answer* — Thread/Zigbee avoids the Wi-Fi association cost entirely. Rejected for Rev 1 only because it requires a border router / Zigbee coordinator. Kept as the Variant-C radio option. |
| ESP32-C5 | dual-band 2.4/5 GHz Wi-Fi 6 | higher | 5 GHz is pure cost and power for a 100-byte-per-15-minutes payload. |
| ESP32-S3 | Wi-Fi 4, BLE | ~7 µA | dual-core Xtensa, USB-OTG, more RAM — all irrelevant here, more energy per wake. |
| ESP32 (original) | Wi-Fi 4, BT Classic | ~10 µA + slower boot | older, higher wake energy, no reason. |
| nRF52840 / STM32WB | BLE/Thread | ~1–2 µA | genuinely lower power, but abandons Wi-Fi and the ESP-IDF ecosystem. Out of scope. |

### 2.2 The point almost everyone gets wrong

For a duty-cycled Wi-Fi sensor, **deep-sleep current is not the battery
budget** — the wake-and-connect energy is. A wake cycle spends its energy on
scan → auth/assoc → DHCP → TLS handshake → publish, and that is *seconds* of
tens-to-hundreds of mA. 5 µA vs 7 µA of sleep current is noise by comparison.

That reframes the C3-vs-C6 question completely:

- **C3 wins on sleep current and price. It loses on the thing that matters.**
- **C6 supports 802.11ax Target Wake Time (TWT)**, which lets the node stay
  *logically associated* and wake only in negotiated slots — eliminating the
  20–50 ms association handshake and the DHCP round trip on every single upload.
  Reported real-world idle drain improvements are in the tens of percent.
- TWT requires a Wi-Fi 6 AP. **If the deployment AP is not Wi-Fi 6, C6 degrades
  gracefully to exactly the C3 behaviour** — we lose nothing but the €1.

So the C6 is bought as an *option on a better power mode*, plus an option on
Thread/Matter, for about one euro. On a 20-unit run that is €20 total. Take it.

### 2.3 Decision

**ESP32-C6-MINI-1-N4 confirmed** (module, not bare silicon — the module carries
the crystal, RF matching, antenna and an existing RED/CE type examination, which
removes the single largest RF risk from a 20-unit project).

Firmware must implement both paths and *measure* them on the prototypes:
1. classic deep-sleep + reconnect (baseline, always works),
2. TWT-assisted (used when the AP negotiates it).

That measurement is a Rev-1 prototype deliverable, not an assumption.

---

## 3. Summary of changes to the vision baseline

| Item | vision.md | This study | Impact |
|---|---|---|---|
| Sensor | SHT40 (bare) | **SHT45-AD1F** (filtered, ±0.1 °C / ±1.0 %RH) | same footprint & driver; +~€1.5; large long-term gain |
| Sensor 2nd source | — | **HDC3022** (alt footprint on B only, see EDS) | risk removed |
| BME280/680 | not considered | **rejected, with reasons** | avoids a common default |
| MCU | ESP32-C6-MINI-1 | **confirmed**, with the reasoning corrected (TWT, not sleep µA) | firmware must test TWT |
| MCU fallback | — | C3-MINI-1 pin-strategy noted; H2 as Variant-C | supply-chain resilience |
| Long-term care | contamination noted | heater schedule, material rules, assembly rules, health field | multi-year fitness |

---

## 4. Open questions this study did **not** close

| # | Question | Closes at |
|---|---|---|
| CS-1 | SHT45-AD1F vs SHT40-AD1B for the *final 20* — is ±1.0 %RH worth €1.5/unit at series scale? | Rev 2 gate, using prototype data |
| CS-2 | JLCPCB/LCSC stock + price for SHT45-AD1F and ESP32-C6-MINI-1-N4 at 10 and 20 pcs | before prototype order |
| CS-3 | Does the -AD1F membrane change the required vent geometry / response time? | mechanical design, verified in Test 5/6 |
| CS-4 | Is TWT actually available on the deployment APs? | firmware bring-up |

Sources:
[SHT4x datasheet](https://sensirion.com/resource/datasheet/sht4x) ·
[SHT45-AD1F](https://sensirion.com/products/catalog/SHT45-AD1F) ·
[HDC3022](https://www.ti.com/product/HDC3022) ·
[BME280 datasheet](https://www.bosch-sensortec.com/media/boschsensortec/downloads/datasheets/bst-bme280-ds002.pdf) ·
[field sensor comparison](https://olegtarasov.me/environmental-sensors/) ·
[ESP32-C6 TWT vs deep sleep](https://industrialmonitordirect.com/blogs/knowledgebase/esp32-c6-wi-fi-6-twt-power-saving-vs-deep-sleep-analysis)

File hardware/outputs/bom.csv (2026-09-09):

Qty | Populate | Refs | Value | Footprint | MPN | Manufacturer | Second source | Sourcing status | Notes
1 | yes | C1 | 22uF/6.3V X5R | C_0805_2012Metric |  |  |  | generic specification; purchasing must qualify exact MPN | ESP32 bulk, >=10uF required by Espressif
1 | yes | C2 | 100nF/16V X7R | C_0402_1005Metric |  |  |  | generic specification; purchasing must qualify exact MPN | ESP32 HF decoupling
1 | yes | C3 | 1uF/16V X7R | C_0402_1005Metric |  |  |  | generic specification; purchasing must qualify exact MPN | ESP32 mid-frequency decoupling
1 | yes | C4 | 1uF/16V X7R | C_0402_1005Metric |  |  |  | generic specification; purchasing must qualify exact MPN | EN RC delay (~10 ms)
1 | yes | C5 | 100nF/16V X7R | C_0402_1005Metric |  |  |  | generic specification; purchasing must qualify exact MPN | SW1 debounce
1 | yes | C6 | 100nF/16V X7R | C_0402_1005Metric |  |  |  | generic specification; purchasing must qualify exact MPN | sensor VDD decoupling - ONLY passive on the island
1 | yes | C7 | 4.7uF/10V X5R | C_0603_1608Metric |  |  |  | generic specification; purchasing must qualify exact MPN | buck input - 4.7 uF required at VIN
1 | yes | C8 | 10uF/6.3V X5R | C_0603_1608Metric |  |  |  | generic specification; purchasing must qualify exact MPN | buck output
1 | yes | C9 | 10uF/16V X5R | C_0805_2012Metric |  |  |  | generic specification; purchasing must qualify exact MPN | charger IN bypass
1 | yes | C10 | 10uF/6.3V X5R | C_0805_2012Metric |  |  |  | generic specification; purchasing must qualify exact MPN | charger OUT bypass
1 | yes | C11 | 10uF/6.3V X5R | C_0805_2012Metric |  |  |  | generic specification; purchasing must qualify exact MPN | charger BAT bypass
1 | yes | C12 | 100nF/16V X7R | C_0402_1005Metric |  |  |  | generic specification; purchasing must qualify exact MPN | charger IN HF bypass
1 | yes | C14 | 100nF/16V X7R | C_0402_1005Metric |  |  |  | generic specification; purchasing must qualify exact MPN | VBUS local
1 | yes | C13 | 100nF/16V X7R | C_0402_1005Metric |  |  |  | generic specification; purchasing must qualify exact MPN | ADC filter
1 | yes | D1 | LED_GREEN | LED_0603_1608Metric | KP-1608SGC | Kingbright | any 0603 green LED, Vf < 2.4 V at 0.5 mA | single-sourced, accepted risk for design exploration only; alternate is unqualified, do not substitute | status LED, active low
1 | yes | J1 | USB-C 16P | USB_C_Receptacle_HRO_TYPE-C-31-M-12 | TYPE-C-31-M-12 | HRO | GCT USB4085 (different land pattern - do not swap without relayout) | single-sourced, accepted risk for design exploration only; alternate is unqualified, do not substitute | USB-C receptacle, sink only, TH mounting lugs
1 | yes | J2 | Molex PicoBlade 3P | Molex_PicoBlade_53261-0371_1x03-1MP_P1.25mm_Horizontal | 53261-0371 | Molex | single-sourced connector family; accepted for prototypes pending pack qualification | single-sourced, accepted risk for design exploration only; alternate is unqualified, do not substitute | LP702040 pack: pin 1 GND(-), pin 2 PACK_TS/103AT-2, pin 3 VBAT(+)
1 | yes | L1 | 2.2uH | L_Murata_DFE201610P | DFE201612E-2R2M | Murata | DFE201210S-2R2M (thinner, same land pattern family) | single-sourced, accepted risk for design exploration only; alternate is unqualified, do not substitute | 2.2 uH, DCR 116 mOhm - datasheet SLVSEC6D Table 4
1 | yes | Q1 | 2N7002 | SOT-23 | 2N7002LT1G | onsemi | 2N7002,215 (Nexperia; same G-S-D pinout and SOT-23 land pattern) | single-sourced, accepted risk for design exploration only; alternate is unqualified, do not substitute | low-side /CE driver; VBUS pull-up keeps charging disabled at power-up
1 | yes | R1 | 10k 1% | R_0402_1005Metric |  |  |  | generic specification; purchasing must qualify exact MPN | EN pull-up
1 | yes | R2 | 3k3 1% | R_0402_1005Metric |  |  |  | generic specification; purchasing must qualify exact MPN | LED series, ~0.5 mA
1 | yes | R3 | 10k 1% | R_0402_1005Metric |  |  |  | generic specification; purchasing must qualify exact MPN | SDA pull-up - main board, never on the island
1 | yes | R4 | 10k 1% | R_0402_1005Metric |  |  |  | generic specification; purchasing must qualify exact MPN | SCL pull-up - main board, never on the island
1 | yes | R5 | 0R | R_0402_1005Metric |  |  |  | generic specification; purchasing must qualify exact MPN | EN tie - a resistor so EN can be lifted to measure Iq
1 | yes | R6 | 267k 1% | R_0402_1005Metric |  |  |  | generic specification; purchasing must qualify exact MPN | VSET -> 3.30 V. Characterization only: 52k3 -> 3.00 V
1 | yes | R7 | 100k 1% | R_0402_1005Metric |  |  |  | generic specification; purchasing must qualify exact MPN | Q1 gate pull-down: charge enable defaults low/off
1 | yes | R8 | 100k 1% | R_0402_1005Metric |  |  |  | generic specification; purchasing must qualify exact MPN | EN1 pull-down: USB100 is the fail-safe reset/unconfigured state
1 | yes | R9 | 100k 1% | R_0402_1005Metric |  |  |  | generic specification; purchasing must qualify exact MPN | /PGOOD pull-up
1 | yes | R10 | 100k 1% | R_0402_1005Metric |  |  |  | generic specification; purchasing must qualify exact MPN | /CHG pull-up
1 | yes | R11 | 8k00 1% | R_0402_1005Metric |  |  |  | generic specification; purchasing must qualify exact MPN | ILIM fallback: <=217 mA incl. KILIM and resistor tolerance; mode not selected
1 | yes | R12 | 3k01 1% | R_0402_1005Metric |  |  |  | generic specification; purchasing must qualify exact MPN | ITERM: 0.03*3010/4420 = 20.4 mA nominal
1 | yes | R13 | 4k42 1% | R_0402_1005Metric |  |  |  | generic specification; purchasing must qualify exact MPN | ISET: 890/4420 = 201 mA nominal; <=223 mA worst case
1 | yes | R18 | 47k 1% | R_0402_1005Metric |  |  |  | generic specification; purchasing must qualify exact MPN | /CE pull-up to VBUS: charger disabled before MCU power-up
1 | yes | R16 | 5k1 1% | R_0402_1005Metric |  |  |  | generic specification; purchasing must qualify exact MPN | CC1 pull-down - UFP advertisement
1 | yes | R17 | 5k1 1% | R_0402_1005Metric |  |  |  | generic specification; purchasing must qualify exact MPN | CC2 pull-down - separate resistor, never shared
1 | yes | R14 | 2M2 1% | R_0402_1005Metric |  |  |  | generic specification; purchasing must qualify exact MPN | VBAT divider top
1 | yes | R15 | 2M2 1% | R_0402_1005Metric |  |  |  | generic specification; purchasing must qualify exact MPN | VBAT divider bottom - 0.95 uA continuous, see EDS S6
1 | yes | SW1 | SW_PROV | Panasonic_EVQPUJ_EVQPUA | EVQ-PUJ02K | Panasonic | TS-1187A-B-A-B (generic 3.5x2.9) | single-sourced, accepted risk for design exploration only; alternate is unqualified, do not substitute | provisioning / boot button
1 | yes | U1 | ESP32-C6-MINI-1-N4 | ESP32-C6-MINI-1 | ESP32-C6-MINI-1-N4 | Espressif | ESP32-C6-MINI-1U-N4 (u.FL, needs external antenna) | single-sourced, accepted risk for design exploration only; alternate is unqualified, do not substitute | Wi-Fi 6 / BLE 5.3 / 802.15.4 module, 4 MB flash
1 | yes | U2 | SHT45-AD1F | Sensirion_DFN-4_1.5x1.5mm_P0.8mm_SHT4x_NoCentralPad | SHT45-AD1F-R2 | Sensirion | SHT40-AD1B (cost-down, same footprint) / HDC3022 (2nd source, alt FP) | single-sourced, accepted risk for design exploration only; alternate is unqualified, do not substitute | +-0.1 C / +-1.0 %RH, integrated PTFE filter membrane, I2C 0x44
1 | yes | U3 | TPS62840DLC | TI_DLC0008B_VSON-HR-8_2x1.5mm_P0.5mm | TPS62840DLCR | Texas Instruments | TPS62841DLCR (lower Vout range - NOT drop-in for 3.0 V) | single-sourced, accepted risk for design exploration only; alternate is unqualified, do not substitute | 750 mA buck, 60 nA Iq, 16 VSET-selectable outputs
1 | yes | U4 | BQ24074RGTR | VQFN-16-1EP_3x3mm_P0.5mm_EP1.6x1.6mm | BQ24074RGTR | Texas Instruments | BQ24075RGTR (same pinout, different DPPM/timer defaults) | single-sourced, accepted risk for design exploration only; alternate is unqualified, do not substitute | 1S Li-ion charger with power path, NTC, status outputs
1 | yes | U5 | USBLC6-2SC6 | SOT-23-6 | USBLC6-2SC6 | STMicroelectronics | PRTR5V0U2X | single-sourced, accepted risk for design exploration only; alternate is unqualified, do not substitute | USB ESD protection array

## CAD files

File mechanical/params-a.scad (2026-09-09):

// SPDX-FileCopyrightText: 2026 Marcel Petrick <mail@marcelpetrick.it>
// SPDX-License-Identifier: GPL-3.0-or-later
// Generated by tools/boardgen/enclosure.py for variant A (Compact). Do not edit.
variant = "a";
board_w = 30.0; board_h = 34.0; board_t = 1.6;
wall = 2.0; floor_t = 2.0; lid_t = 2.0;
clear_xy = 0.6; fillet = 1.5; tol = 0.35;
rib_w = 1.6; support_h = 0.8;
inner_w = 43.0; inner_h = 35.2; inner_z = 14.8;
board_z = 9.100000000000001; top_clear = 4.1;
outer_w = 47.0; outer_h = 39.2; outer_z = 18.8;
batt = [42.0, 20.5, 7.3];
// battery bay in BOARD coordinates; it may extend past the
// board edge, because the cavity is sized to the cell, not the PCB
batt_bay = [-6.0, 7.349999999999998, 36.0, 27.849999999999998];
divider_y = -1;
neck_slot = [0, 0];
antenna_keepout = [0.0, 0.0, 30.0, 5.9];
// [x, y, w, h] on the board, in board coordinates
vents = [[12.0, 30.299999999999997, 8.0, 1.2]];
vent_wall = "bottom";
// [centre, width, height] on the sensor-chamber wall
side_vents = [[10.6, 1.2, 3.0], [13.2, 1.2, 3.0], [15.799999999999999, 1.2, 3.0], [18.4, 1.2, 3.0]];
// [x, y, diameter] hold-down pillars, board coordinates
holddowns = [[12.6, 31.9, 2.2], [28.4, 31.1, 1.8]];
// [wall, x, y, width, height, z] - x,y in board coordinates
cutouts = [["left", 5.5, 24.5, 9.549999999999999, 3.5100000000000002, 1.58], ["lid", 13.7, 28.0, 4.0, 4.0, 0.0], ["lid", 11.3, 22.0, 2.0, 2.0, 0.0]];
board_outline = [[0, 0], [30.0, 0], [30.0, 34.0], [0, 34.0]];

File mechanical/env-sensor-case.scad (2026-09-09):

// SPDX-FileCopyrightText: 2026 Marcel Petrick <mail@marcelpetrick.it>
// SPDX-License-Identifier: GPL-3.0-or-later
// ENV sensor enclosure - common geometry for both variants.
//
// Do not edit the numbers here. Every dimension comes from params-<variant>.scad,
// which tools/boardgen/enclosure.py generates from the board model, so the case
// cannot drift away from the PCB it is meant to hold.
//
//   openscad -D 'part="base"' -o case-a-base.stl mechanical/case-a.scad
//   openscad -D 'part="lid"'  -o case-a-lid.stl  mechanical/case-a.scad
//
// The enclosure is part of the instrument: on Variant B the dividing wall at the
// neck and the vents over the island are what the thermal model's convection
// term actually depends on. See docs/45-thermal-model.md.

part = "base";      // "base" | "lid" | "both"
$fn = 48;

eps = 0.01;

// board position inside the cavity
bx = wall + (inner_w - board_w) / 2;
by = wall + (inner_h - board_h) / 2;
bz = floor_t + board_z;

module rrect(w, h, r) {
    hull() for (x = [r, w - r], y = [r, h - r]) translate([x, y]) circle(r);
}

module shell(height, r) {
    linear_extrude(height) rrect(outer_w, outer_h, r);
}

module cavity(height) {
    translate([wall, wall, 0])
        linear_extrude(height) rrect(inner_w, inner_h, max(0.5, fillet - wall));
}

// ---- cut-outs -------------------------------------------------------------
module wall_cutout(w, cx, cy, cw, ch, z) {
    // cx, cy are the board coordinates of the part the opening serves
    zz = bz + board_t + z;
    if (w == "left")
        translate([-eps, by + cy - cw / 2, zz - ch / 2])
            cube([wall + 2 * eps, cw, ch + tol]);
    else if (w == "right")
        translate([outer_w - wall - eps, by + cy - cw / 2, zz - ch / 2])
            cube([wall + 2 * eps, cw, ch + tol]);
    else if (w == "top")
        translate([bx + cx - cw / 2, -eps, zz - ch / 2])
            cube([cw, wall + 2 * eps, ch + tol]);
    else if (w == "bottom")
        translate([bx + cx - cw / 2, outer_h - wall - eps, zz - ch / 2])
            cube([cw, wall + 2 * eps, ch + tol]);
}

// The lid is the plate PLUS the locating lip, so anything cut in it has to go
// through both. Cutting only `lid_t` deep leaves the lip filling the slots
// straight back in - which is exactly what the first render showed.
lid_total = lid_t + 1.2;

module lid_cutout(centre_x, centre_y, d) {
    translate([bx + centre_x, by + centre_y, -eps])
        cylinder(d = d, h = lid_total + 2 * eps);
}

module vent_slots() {
    for (v = vents)
        translate([bx + v[0], by + v[1], -eps])
            cube([v[2], v[3], lid_total + 2 * eps]);
}

// Slots in the wall next to the sensor. Lid slots alone leave the sensor
// chamber a cup; M-03 wants ambient air at the sensor, not a pocket of it.
module side_vent_slots() {
    zz = bz + board_t + 1.0;
    for (s = side_vents) {
        if (vent_wall == "bottom")
            translate([bx + s[0] - s[1] / 2, outer_h - wall - eps, zz])
                cube([s[1], wall + 2 * eps, s[2]]);
        else
            translate([bx + s[0] - s[1] / 2, -eps, zz])
                cube([s[1], wall + 2 * eps, s[2]]);
    }
}

// Short pillars from the lid down onto bare board, so the PCB cannot rattle
// on its ribs. Positions come from the generator, which searched the placement
// for free space rather than assuming a corner was empty.
module holddown_pillars() {
    h = inner_z - (board_z + board_t);
    for (p = holddowns)
        translate([bx + p[0], by + p[1], lid_t - eps])
            cylinder(d = p[2], h = h + eps);
}

// ---- support --------------------------------------------------------------
module ribs() {
    // Four side-wall ledges support the board from above the pack. They begin
    // only after the full pack envelope plus swelling allowance; floor-to-PCB
    // pillars would pass straight through the selected pouch cell. Each ledge
    // reaches a side wall, so it is printable rather than a floating cube.
    ay1 = antenna_keepout[3];
    for (y = [ay1 + 3, board_h - 3]) {
        translate([wall, by + y - rib_w / 2,
                   floor_t + board_z - support_h])
            cube([bx - wall + rib_w, rib_w, support_h]);
        translate([bx + board_w - rib_w, by + y - rib_w / 2,
                   floor_t + board_z - support_h])
            cube([outer_w - wall - (bx + board_w - rib_w),
                  rib_w, support_h]);
    }
}

module divider() {
    // Variant B only: the wall between the electronics chamber and the sensor
    // chamber, with a slot for the PCB neck to pass through.
    if (divider_y > 0) {
        difference() {
            translate([wall, by + divider_y - wall / 2, floor_t])
                cube([inner_w, wall, inner_z]);
            translate([bx + board_w / 2 - neck_slot[0] / 2,
                       by + divider_y - wall / 2 - eps,
                       bz - tol])
                cube([neck_slot[0], wall + 2 * eps, neck_slot[1]]);
        }
    }
}

// ---- parts ----------------------------------------------------------------
module base() {
    difference() {
        union() {
            difference() {
                shell(floor_t + inner_z, fillet);
                translate([0, 0, floor_t]) cavity(inner_z + eps);
            }
            ribs();
            divider();
        }
        for (c = cutouts)
            if (c[0] != "lid") wall_cutout(c[0], c[1], c[2], c[3], c[4], c[5]);
        side_vent_slots();
    }
}

module lid() {
    union() {
        difference() {
            union() {
                linear_extrude(lid_t) rrect(outer_w, outer_h, fillet);
                // lip that locates the lid in the cavity
                difference() {
                    translate([wall + 0.3, wall + 0.3, lid_t])
                        linear_extrude(1.2)
                            difference() {
                                rrect(inner_w - 0.6, inner_h - 0.6,
                                      max(0.5, fillet - wall));
                                translate([1.2, 1.2])
                                    rrect(inner_w - 3.0, inner_h - 3.0, 0.5);
                            }
                    // The chamber wall reaches the lid seating plane. Relieve
                    // the ring where it crosses that wall, not the whole lid.
                    if (divider_y > 0)
                        translate([0, by + divider_y - wall/2 - tol, lid_t - eps])
                            cube([outer_w, wall + 2*tol, 1.2 + 2*eps]);
                }
            }
            vent_slots();
            for (c = cutouts)
                if (c[0] == "lid") lid_cutout(c[1], c[2], c[3]);
        }
        holddown_pillars();
    }
}

if (part == "base") base();
else if (part == "lid") lid();
else if (part == "interference") {
    intersection() {
        base();
        // Ignore the intended zero-volume seating-face contact. The epsilon
        // remains far smaller than any printable interference we need to catch.
        translate([0, 0, floor_t + inner_z + lid_t + eps]) mirror([0, 0, 1]) lid();
    }
}
else if (part == "both") { base(); translate([0, outer_h + 5, 0]) lid(); }
else assert(false, "unknown enclosure part");

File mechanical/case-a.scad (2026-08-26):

// SPDX-FileCopyrightText: 2026 Marcel Petrick <mail@marcelpetrick.it>
// SPDX-License-Identifier: GPL-3.0-or-later
// Generated wrapper for variant A. Edit env-sensor-case.scad or the generator, not this file.
include <params-a.scad>
include <env-sensor-case.scad>

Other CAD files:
mechanical/params-b.scad
mechanical/case-b.scad

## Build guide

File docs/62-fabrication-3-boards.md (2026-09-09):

# 62 — Fabricating Three Boards

The question: **who will make just three of these, and what does the antenna
need from them?**

Most low-cost fabs have a five-piece minimum. Two vendors sell in multiples of
three as their standard product, and three German fabs have no minimum at all.

---

## 1. Shortlist

| Vendor | Where | MOQ | 4-layer | Notes |
|---|---|---|---|---|
| **AISLER** | NL/DE, delivers from Germany | **multiples of 3** | yes | Priced purely by board area × quantity. Entry price €14.20. No import VAT, no customs, short shipping. Also offers assembly. **Best fit for this request.** |
| **OSH Park** | USA | **multiples of 3** | yes, $10/in² incl. 3 copies | FR408-HR, 1 oz outer / **0.5 oz inner**, 1.6 mm, 5 mil/5 mil, 10 mil drill, 9–14 days. US import + 19 % VAT into DE. |
| **Multi-CB** | Germany | **1 piece** | yes | No minimum quantity, express from 1 working day. Calculator-based. |
| **LeitOn** | Berlin, Germany | **1 piece** | yes, 3-day express on multilayer | German and Asian production at different price points. |
| **Beta LAYOUT (PCB-POOL)** | Germany | prototype pool | yes (4/6 layer) | Climate-neutral pool service, calculator up to 1000 pcs. |
| Eurocircuits | Belgium | pool, low | yes | EU, well-documented stackups. |
| JLCPCB / PCBWay | China | **5 pieces** | yes | Cheapest per board, but cannot do three, and adds freight + 19 % VAT. |

### What three boards actually costs, bare

Computed from the real outlines at OSH Park's published 4-layer rate:

| Board | Size | Area | OSH Park 4-layer (3 copies) | Per board |
|---|---|---:|---:|---:|
| A — Compact | 30 × 34 mm | 1.58 in² | $15.81 | $5.27 |
| B — Thermally isolated | 28 × 51 mm | 2.21 in² | $22.13 | $7.38 |
| **Both, 3 + 3 = 6 boards** | | | **$37.94** | **$6.32** |

AISLER prices by area as well and quotes instantly from the uploaded files;
their published entry point is €14.20 and roughly €9 for three small boards, so
for boards this size expect the same order of magnitude as OSH Park, with no
customs and a much shorter trip. **Get the real quote from the uploader — these
two lines are for sizing the decision, not for the accounting.**

### Recommendation

**AISLER for three boards.** It is the only vendor on the list that is
simultaneously a native "multiples of three" service, inside the EU, and short
on shipping. OSH Park is the direct alternative and its stackup is published in
detail, but see §3 — its inner copper is half the weight, which for *this*
project is not a neutral difference.

If the order ever grows past three, the calculus flips back to JLCPCB, where the
5-piece minimum stops being a constraint and the panelisation saving in
`61-cost-reduction.md` becomes available.

---

## 2. What the antenna needs from the fab — and what it doesn't

The radio is a **pre-certified module with its own PCB antenna**. That removes
most of what people assume an RF board needs. What is left is short and specific.

### It does need

1. **The outline routed as drawn, with the keep-out kept clear.** The antenna
   sits in a full-width strip at the top of both boards that carries no copper
   on any of the four layers. That is already in the Gerbers; the fab simply has
   to not add anything to it.

2. **No panel rails, tabs or mouse-bites inside the antenna strip — and
   absolutely none across Variant B's neck.** Every pooled service panelises
   internally, so break-off tabs land somewhere on your outline. In the antenna
   strip a tab is only cosmetic (bare FR-4, no copper, no RF effect). **In the
   3.5 mm neck it is a stress riser at the single weakest point of the board.**
   State this on the order in one sentence:

   > *Please keep break-off tabs off the narrow neck between the main board and
   > the sensor island, and off the top 6 mm of the board.*

3. **ENIG, not HASL.** The SHT45 is a 0.5 mm-pitch DFN and the charger is a
   3 × 3 mm QFN with a centre pad. HASL leaves a domed, uneven surface that
   makes fine-pitch placement and inspection worse. The price difference at
   three boards is small; the yield difference is not.

4. **Outline tolerance stated.** At a 3.5 mm nominal neck, ±0.2 mm of routing
   tolerance is ±6 % on the FR-4 conduction term — thermally irrelevant, but it
   is the mechanical margin on the thinnest feature of the board, so it is worth
   knowing which way the fab errs. Ask for the router bit diameter too.

### It does *not* need

- **Controlled impedance.** There is no RF trace on this board — the antenna is
  inside the module. The only differential pair is USB D+/D−, running about
  30 mm at full speed (12 Mbit/s). Specifying controlled impedance here would
  cost money and buy nothing. This is worth saying out loud, because "it has USB
  and an antenna, so it needs controlled impedance" is a reflex that quietly
  doubles small-batch quotes.
- **Special laminate.** Standard FR-4 is correct. The module's antenna was
  characterised against a normal carrier; low-loss laminate changes nothing that
  the keep-out has not already handled.
- **Soldermask restrictions over the antenna.** Mask is a thin dielectric and is
  fine there.
- **Any minimum feature we don't already meet.** Tightest features on the board
  are 0.15 mm island traces and 0.2 mm drills, both inside every vendor above.

---

## 3. The trap: stackup is an experimental variable

This one matters more than the price.

The hypothetical slab model's **112×** copper/FR-4 ratio assumes **1 oz (35 µm)
copper on all four layers**. A's actual sensor quiet zone excludes those pours,
so this is not a measured or routed-board conduction ratio. Stackup still
affects heat flow and must be controlled; its effect on the actual A/B result
must be measured. Obtain the selected fab's current stackup rather than assuming
any vendor uses the model's copper weights by default.

Two consequences, both non-negotiable:

- **Every board in the comparison must come from one fab, one stackup, one
  order.** Mixing an AISLER A with an OSH Park B would not be an A/B test of
  geometry; it would be an A/B test of copper weight.
- **Record the actual stackup with the results.** It belongs in
  `measurements/thermal/` alongside the data, and it is a new entry on the
  "what would make this experiment invalid" list in
  `50-thermal-ab-test-plan.md`.

If the boards do come back with 0.5 oz inner layers, re-run `make thermal` with
`T_CU` halved for the inner layers before comparing model to measurement.

---

## 4. What to send them

The development pipeline generates these review outputs:

```
hardware/outputs/rev-a/gerber/     11 layers, RS-274X
hardware/outputs/rev-a/drill/      Excellon + map
hardware/outputs/rev-b/gerber/
hardware/outputs/rev-b/drill/
```

Both variants are 4-layer FR-4, 1.6 mm, and both fit inside 50 × 50 mm. `make
outputs` and the Hardware Quality workflow deliberately mark these files as
**draft, not for fabrication**. Timestamp-bearing outputs are built by CI and
are not committed.

Only the manual Hardware Release workflow creates a distributable ZIP and its
SHA-256 checksum. Its requested tag must match the board revision printed on
the selected layout (`hw-a1` or `hw-b1` today), and it runs
`make release-package RELEASE_TAG=<tag>`. That target refuses to continue until
the release gate sees zero routing gaps, zero DRC/parity findings and real files
for every qualification category in `hardware/release-readiness.json`.

For assembled boards rather than bare ones, add:

```
hardware/outputs/rev-*/assembly/cpl-*.csv    placement
hardware/outputs/bom.csv                     with MPNs and second sources
hardware/outputs/rev-*/assembly/*.pdf        assembly drawing (F.Fab)
```

Note that at three boards, assembly is usually the wrong call: the setup,
stencil and feeder fees are per *order*, not per board, so they land on three
units instead of ten. Three bare boards hand-populated is the cheaper route if
you have a reflow plate; three assembled boards is the cheaper route if your
time is worth anything. The break-even is roughly where the assembly fixed cost
(~$35–45) equals the hours you would spend on 190 solder joints × 3.

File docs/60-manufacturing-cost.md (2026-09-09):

# 60 — Manufacturing Cost Estimate (generated)

<!-- Generated by `make cost` from tools/cost.py. Do not edit: change the rate
     table, re-run, commit both. -->

**These are planning estimates, not quotes.** The quantities below come from the
real board model — joints, components and areas are counted from the generated
files — but every *rate* is a researched input that goes stale. A real quote
from the vendor's own uploader replaces this file, it does not agree with it.

Rates researched 2026-09-09. USD→EUR at 0.92. German import VAT
19% applied to goods + freight.

## What is actually being built

| | |
|---|---:|
| Components per board (excl. test pads) | 43 |
| SMT solder joints | 196 |
| Through-hole joints (USB-C shield lugs) | 4 |
| Distinct BOM lines | 28 |
| Passives (0402/0603/0805) | 32 |
| Likely extended-library parts | 9 |
| Variant A area | 10.2 cm² |
| Variant B area | 14.3 cm² |

Both boards fit inside 50 × 50 mm, which is the size band where 4-layer
fabrication is cheapest — that is not an accident of the floorplan.

## Rev 1 prototypes — 5 × A + 5 × B

| Line | | Cost |
|---|---|---:|
| PCB fabrication | USD, pre-VAT | $4–18 |
| Assembly — setup, stencil, feeders, 196 joints × 10 | USD, pre-VAT | $84–118 |
| Components — 10 × board BOM | USD, pre-VAT | $93–154 |
| Freight to Germany | USD | $14–28 |
| **Landed PCBA, incl. 19% import VAT** | EUR | **€214–349** |
| Batteries, printed cases, labels — bought in the EU | EUR | €49–127 |
| **Total programme** | EUR | **€263–476** |
| **Per finished unit** | EUR | **€26.28–47.58** |

## Rev 2 series — 20 × the chosen variant

| Line | | Cost |
|---|---|---:|
| PCB fabrication | USD, pre-VAT | $11–32 |
| Assembly — setup, stencil, feeders, 196 joints × 20 | USD, pre-VAT | $48–67 |
| Components — 20 × board BOM | USD, pre-VAT | $186–309 |
| Freight to Germany | USD | $14–28 |
| **Landed PCBA, incl. 19% import VAT** | EUR | **€283–477** |
| Batteries, printed cases, labels — bought in the EU | EUR | €98–254 |
| **Total programme** | EUR | **€381–731** |
| **Per finished unit** | EUR | **€19.07–36.57** |

## Where the money goes

At these quantities the **components dominate**, and inside the components two
parts dominate: the ESP32-C6 module ($3.03–3.92)
and the SHT45-AD1F ($4.00–6.13).
Together they are roughly two thirds of the bill of materials. Everything else —
charger, regulator, connectors, 32 passives — is about a dollar and a half.

That has a direct consequence for the A/B decision: **variant B's extra 28 % of
board area is nearly free.** Fabrication is a small fraction of the total and
both boards sit in the same sub-50 mm price band. If B wins the thermal test, it
does not lose on cost.

The one lever that would move the number is the sensor. Dropping to SHT40-AD1B
saves roughly $1.50–2.50 per unit — about 8 % of the finished cost — at the price
of ±1.8 %RH instead of ±1.0 %RH and no filter membrane. That trade is open item
CS-1 and it should be decided on the Rev 1 humidity data, not on this table.

## Route comparison

| | China turnkey (JLCPCB-class) | EU (Aisler / Eurocircuits) |
|---|---|---|
| Boards + assembly | cheapest by a wide margin at these volumes | ~2–3× on the PCBA line |
| Lead time | 1–3 weeks incl. freight | days to ~1 week |
| VAT / customs | 19 % import VAT, paperwork, occasional delays | VAT handled domestically |
| Part sourcing | LCSC library, extended-part fees | you often supply or they source at distributor prices |
| When it wins | prototypes and small series like this one | when transit time, documentation or IPC class matter |

For 5 + 5 prototypes and a 20-unit series the China route is the obvious choice
on cost. The EU route becomes interesting the moment schedule matters more than
€200, or if the boards ever need IPC Class 2/3 documentation.

## What this estimate deliberately excludes

Engineering time. Test equipment and the reference hygrometer. The pogo fixture.
Failed prints and scrapped boards — budget one full spare set. Formal RED/EMC
testing, which is a five-figure line item and is why Rev 1 uses a pre-certified
module and stays a personal project.

## Sources

| Rate | Source |
|---|---|
| smt_setup_usd | JLCPCB Economic PCBA setup fee |
| stencil_usd | JLCPCB Economic PCBA stencil |
| smt_joint_usd | JLCPCB SMT assembly, per joint |
| manual_joint_usd | JLCPCB manual assembly, per joint |
| hand_solder_order_usd | JLCPCB hand-soldering labour, per order |
| extended_part_usd | JLCPCB fee per unique extended-library part |
| fab_5pcs_usd | JLCPCB 4-layer, <50x50 mm, 5 pcs (promotional floor to realistic with options) |
| fab_20pcs_usd | JLCPCB 4-layer, <50x50 mm, 20 pcs |
| freight_usd | JLCPCB express to Germany, small parcel |
| U1 | ESP32-C6-MINI-1-N4, LCSC C5736265: $3.92@1, $3.49@10, $3.24@30, $3.03@100 |
| U2 | SHT45-AD1F-R2, JLCPCB C5360602 (extended); DigiKey $6.13@1 |
| U3 | TPS62840DLCR, LCSC C2071859 from $0.48 |
| U4 | BQ24074RGTR, LCSC C54313 from $0.47 |
| U5 | USBLC6-2SC6, commodity ESD array |
| Q1 | onsemi 2N7002LT1G; DigiKey/Mouser planning range, checked 2026-09-09 |
| J1 | HRO TYPE-C-31-M-12, commodity 16P receptacle |
| J2 | Molex 53261-0371; Mouser Germany EUR 0.542@1 / 0.464@10 on 2026-09-09, converted with the report planning rate |
| L1 | Murata DFE201612E-2R2M shielded inductor |
| SW1 | SMD tactile switch |
| D1 | 0603 green LED |
| battery | provisional generic-pack allowance only; LP702040 FD_3245_20 supplier quote is TBC (EUR) |
| enclosure_self | 3D printed in-house, material + failures |
| enclosure_service | printed by a service, two parts |
| labels_screws | QR label, insulator, fasteners |

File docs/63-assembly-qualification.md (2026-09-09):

# 63 — Purchasing and assembly qualification

The BOM is a design BOM. Nonempty “Second source” text is a candidate list, not
qualification. Every specified part is currently single-sourced; that risk is
accepted only for design exploration. No purchasing substitution is authorized.
The BOM now carries this distinction explicitly and missing sourcing records
make `make bom` fail.

The TPS62841 candidate cannot supply the baseline rail. The HDC3022 and GCT USB
connector candidates require different footprints. The alternate radio module
changes the antenna system. None may be fitted automatically. For every MPN,
record source drawing/revision, pin numbering, land pattern, rotation, ratings,
availability and a signed assembly review before ordering. Generic passives also
need exact purchasable MPNs, effective capacitance at bias, voltage/tolerance and
inductor saturation checks. Owner: hardware maintainer; gate: prototype order.

Validate the KiCad CPL convention against the assembler's preview, with explicit
pin-1 checks for U1–U5, J1/J2 and D1. The library coordinates are not a guarantee
of the assembler's zero-degree orientation. Record the approved preview and
as-built BOM with the board revision. A later substitute invalidates that review.

`Populate=no` BOM lines identify DNP options and are never merged with fitted
parts. CPL export excludes DNP, and fixture-only footprints are explicitly
excluded from placement files. Qty is the number of references on a line;
assemble it only when Populate is yes. These are KiCad placement coordinates;
the assembler still must approve orientation and through-hole connector handling.
The committed BOM uses LF line endings for readable, reproducible Git diffs.

J2 is now the Molex 53261-0371 PicoBlade header and the selected LP702040 pack
uses a 51021-0300 three-circuit housing. Before releasing placement data, compare
the J2 pads, pin-1 marker and 90° board rotation with Molex drawing 532610271-SD
and the assembler preview. Before any pack is plugged in, incoming inspection
must continuity-check the configured harness as `1=black/-`, `2=yellow/NTC`,
`3=red/+`; connector keying does not protect the board from a supplier-built
harness with the wrong cavity order. The pack, its configured harness and the
header family are single-source prototype risks pending the second-source gate.

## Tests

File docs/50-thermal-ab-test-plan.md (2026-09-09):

# 50 — A/B Thermal Test Plan

The experiment compares complete enclosures at equal operating conditions.
Both variants may pass, fail, or remain inconclusive. No simulated isolation
ratio is treated as evidence.

## Units and controlled factors

Build five A and five B in one assembly lot using the same parts, pack model,
copper stackup, firmware binary and printing settings. The primary experiment
uses 3.3 V on all ten boards (EDS §4.1). Use F-11 serials ENV-0001…0005 for A,
ENV-0006…0010 for B, paired by offset five, and record
serial, component lot, R6, pack serial/capacity, PCB revision and firmware hash.
The selected LP702040 pack must pass the physical checks in
`51-power-safety-qualification.md` in both cases before this protocol starts.

Run any 3.0 V characterization separately after the primary experiment. Record
rework and analyze matched units before/after; never pool different rails as
five interchangeable samples of a geometry.

## Reference, positioning and uncertainty

Use a calibrated temperature/RH reference with certificate, stated uncertainty
and valid range. The ±0.3 °C system target cannot be verified just by observing
a mean within ±0.3 °C against an uncertain reference.

Place the ten DUTs on a circle of 150 mm radius around the reference, with equal
angular spacing and identical orientation. Nearest-neighbor centres are about
93 mm apart (2 × 150 × sin(18°)); do not also require 100 mm separation and a
100 mm reference distance. Map temperature/RH gradients at all ten positions
before testing; record their contribution to uncertainty. A and B alternate.
Rotate each unit by two positions between five repeated equilibrium/charging
runs, then repeat with A/B swapping adjacent positions. Record the permutation.
If room gradients exceed the error budget, use a controlled chamber or local
references rather than correcting away an unexplained variant effect.

Choose and document the reference, timing and spatial uncertainty budget before
collecting acceptance data. Use conservative total uncertainty U including
certificate, spatial gradient and timestamp mismatch. Guard-band temperature
acceptance with max(abs(DUT − reference)) + U ≤ 0.3 °C over the declared
operating conditions. RH uses the equivalent 3 %RH limit and its own U.
If uncertainty prevents classification, the result is inconclusive.

## Acquisition and radio schedule

Acquisition timestamps describe when the sensor converted, not when MQTT
received the batch. For Tests 1 and 4, sample every five minutes and upload
every fifteen minutes; buffer the samples between uploads. Do not introduce
one-minute MQTT traffic to observe a sleeping device. Read before radio start.
The reference logs at least once per minute, with synchronized UTC times.

For charging and step tests, acquire once per minute into local storage and
upload every fifteen minutes. This deliberate non-default cadence is identical
for A and B and is recorded in the run metadata. Establish a matched baseline
at this cadence before interpreting its charging excursion. Missing samples,
reset events and retransmitted batches remain visible.

## Tests

| Test | Condition and acquisition | Duration / analysis window |
|---|---|---|
| 1 | Battery, normal 5/15-minute cadence | 60-minute settling, then 12 hours |
| 2 | Battery, deliberate 1-minute sampling/upload stress | 60-minute settling, then 4 hours |
| 3 | Qualified enclosed charging, same initial measured state of charge, 1/15-minute cadence | 60-minute battery baseline, then charge through termination and cooldown |
| 4 | Battery, default 5/15-minute cadence | 60-minute settling, then 24 hours |
| 5 | Temperature step, nominal 18 → 26 °C, 1/15-minute cadence | Pre-step equilibrium then 2 hours; do not discard the transient |
| 6 | Humidity step, nominal 40 → 70 %RH, 1/15-minute cadence | Pre-step equilibrium then 2 hours; reference measures actual step |

Test 3 starts only after EDS-9Q battery-temperature/charge qualification.
Match charger current, source and pack between variants. Log actual current;
charger power is not a fixed value across the run. Continue until the
temperature returns to the predeclared equilibrium band, recording cooldown.

## Immutable records and metrics

CSV samples carry:
`run_id, serial, variant, position, acquired_at_utc, sequence, temperature_c,
humidity_rh, battery_v, rail_v, usb_present, charging, quality, reset_reason,
firmware_sha256, reference_temp_c, reference_rh`.

The run manifest records duty cycle, initial state of charge, reference
certificate/uncertainty, enclosure/pack/PCB identifiers, timestamps, and the
position permutation. Raw logs go to `measurements/thermal/`, never edited.
Retain invalid readings with quality flags; never turn a failed read into zero.
Deduplicate only by (serial, sequence, boot identity), keeping the raw data.

Report per-unit mean bias, maximum absolute error, standard deviation and
coverage. Summarize one result per unit per condition, with five paired A/B
differences; thousands of serially correlated samples are not thousands of
independent devices. Report unit spread and uncertainty, not just a group mean.
Charging excursion uses the matched 1/15-minute baseline. Step response is time
to 63% of the measured reference step from the pre-step baseline; report
insufficient settling or sampling resolution instead of inventing a time constant.

## Ordered decision gate

Apply these steps in order; endpoints belong to exactly one branch.

1. Invalid runs, insufficient coverage or unresolved uncertainty: repeat or
   improve the setup. No winner.
2. If neither variant meets guarded F-01/F-02 limits in normal operation, fix the
   design and repeat. Passing on average does not excuse a failing unit.
3. Reject B if any neck shows cracking, warping or intermittent continuity. A
   may advance only if it independently passes the functional requirements.
4. If exactly one variant passes, advance that variant subject to all other
   requirements and mechanical qualification.
5. If both pass, define D as mean absolute unit bias of A minus that of B in
   Test 4. Use the uncertainty interval for the paired comparison: if entirely
   below 0.15 °C, prefer compact A; if entirely above 0.30 °C, prefer B.
6. If the entire interval lies in [0.15, 0.30] °C, prefer B only when A's
   uncertainty-guarded charging excursion exceeds 1.0 °C. Otherwise prefer A.
   An interval crossing either threshold is inconclusive. A proposed charge
   current change requires repeating the relevant tests on both variants.

A product choice is not permission to fabricate or distribute. Release gates
also require power, firmware, RF, sourcing and mechanical evidence.

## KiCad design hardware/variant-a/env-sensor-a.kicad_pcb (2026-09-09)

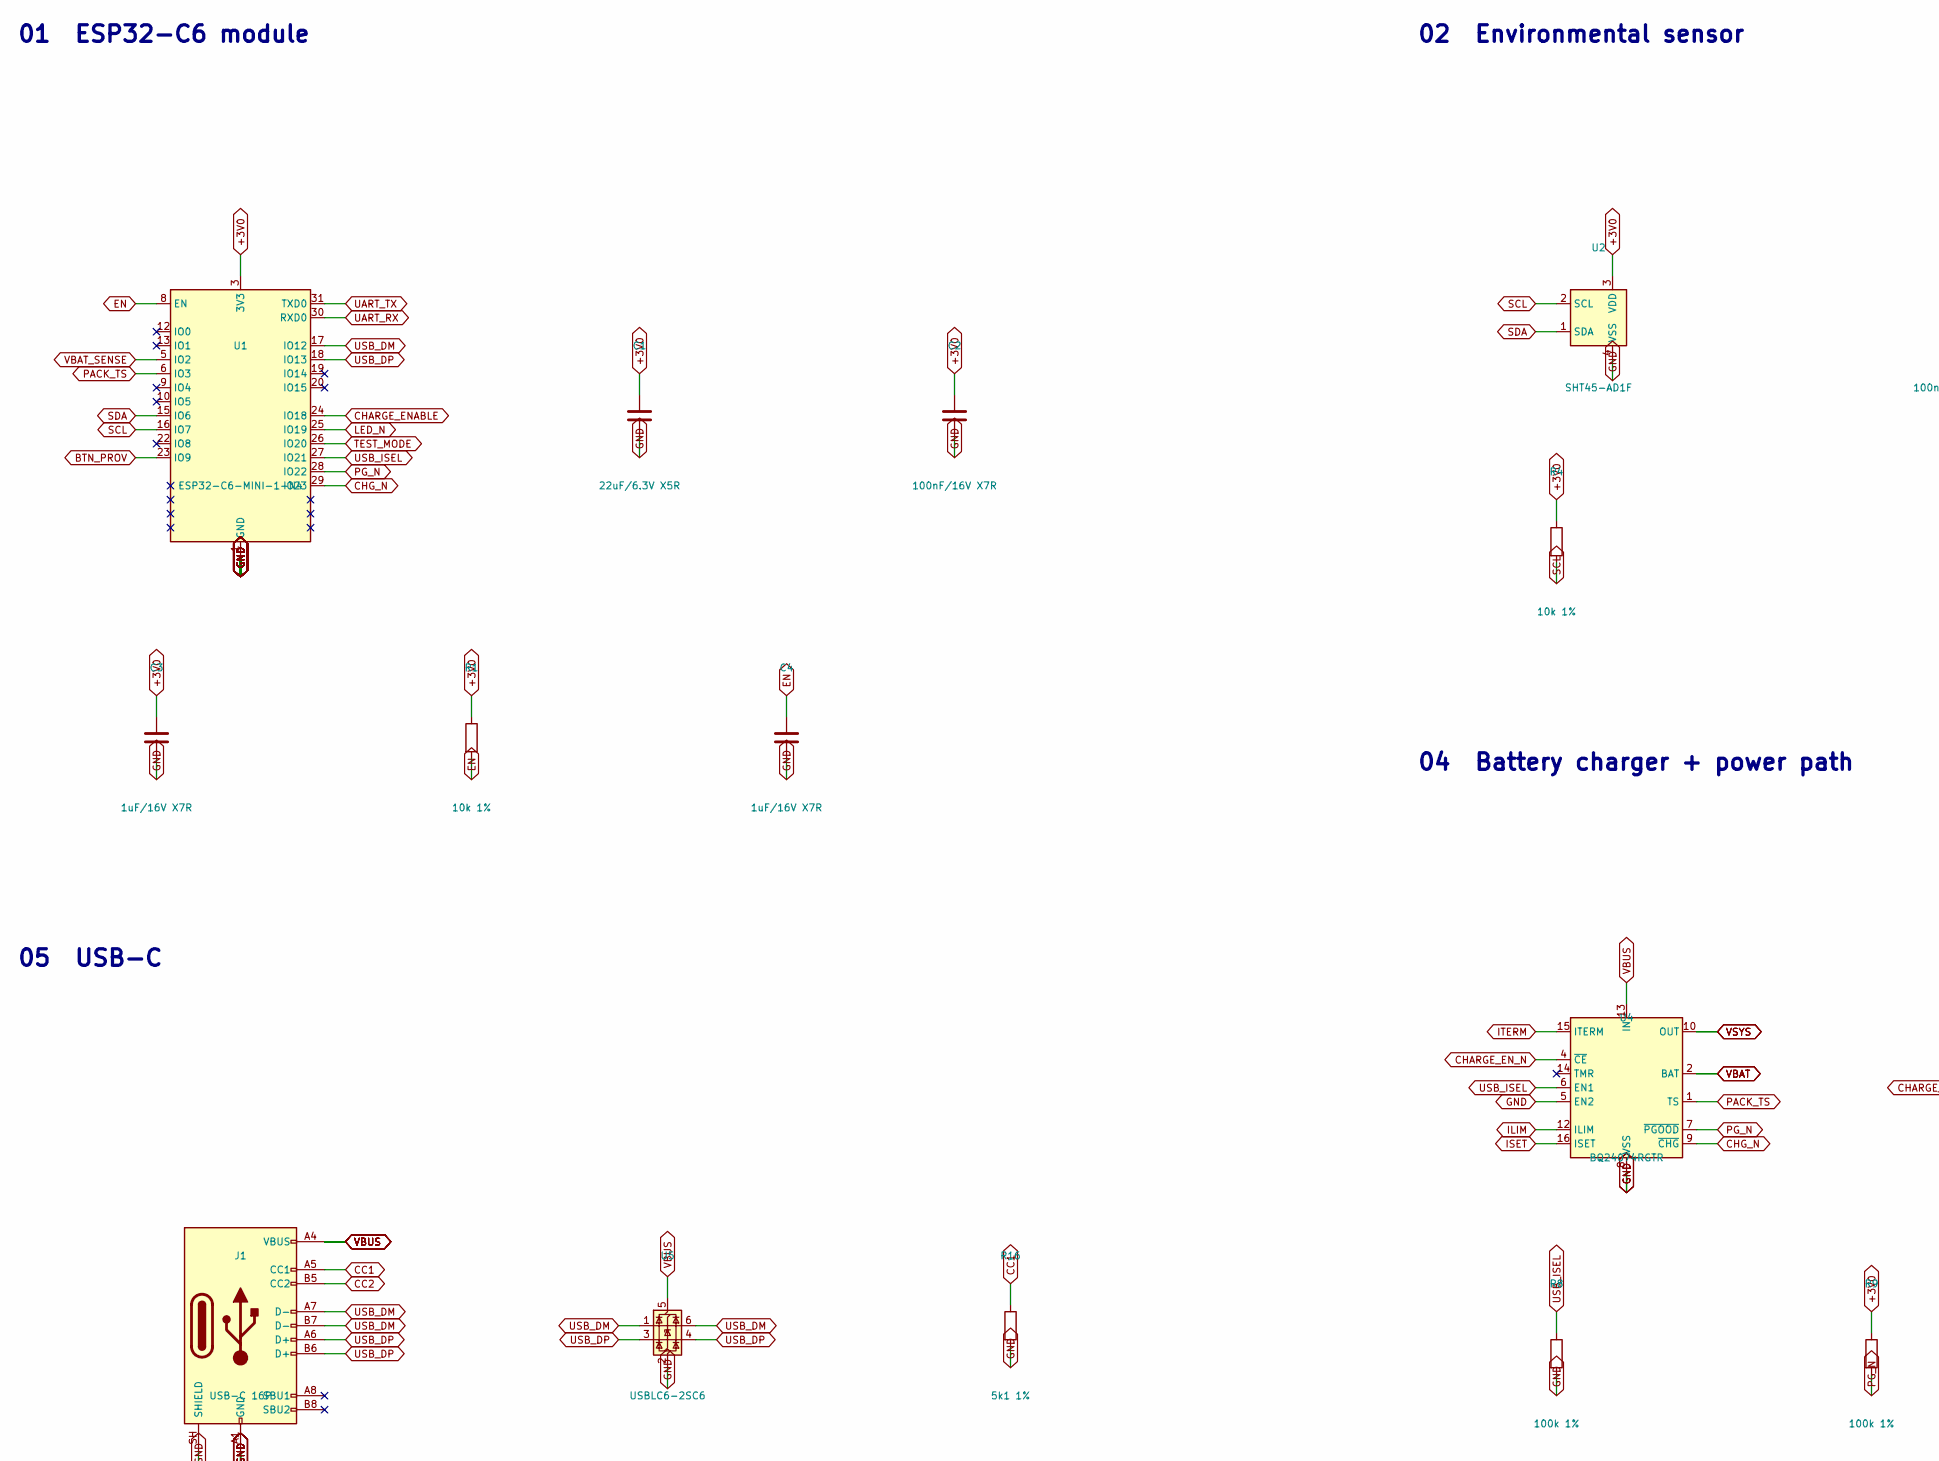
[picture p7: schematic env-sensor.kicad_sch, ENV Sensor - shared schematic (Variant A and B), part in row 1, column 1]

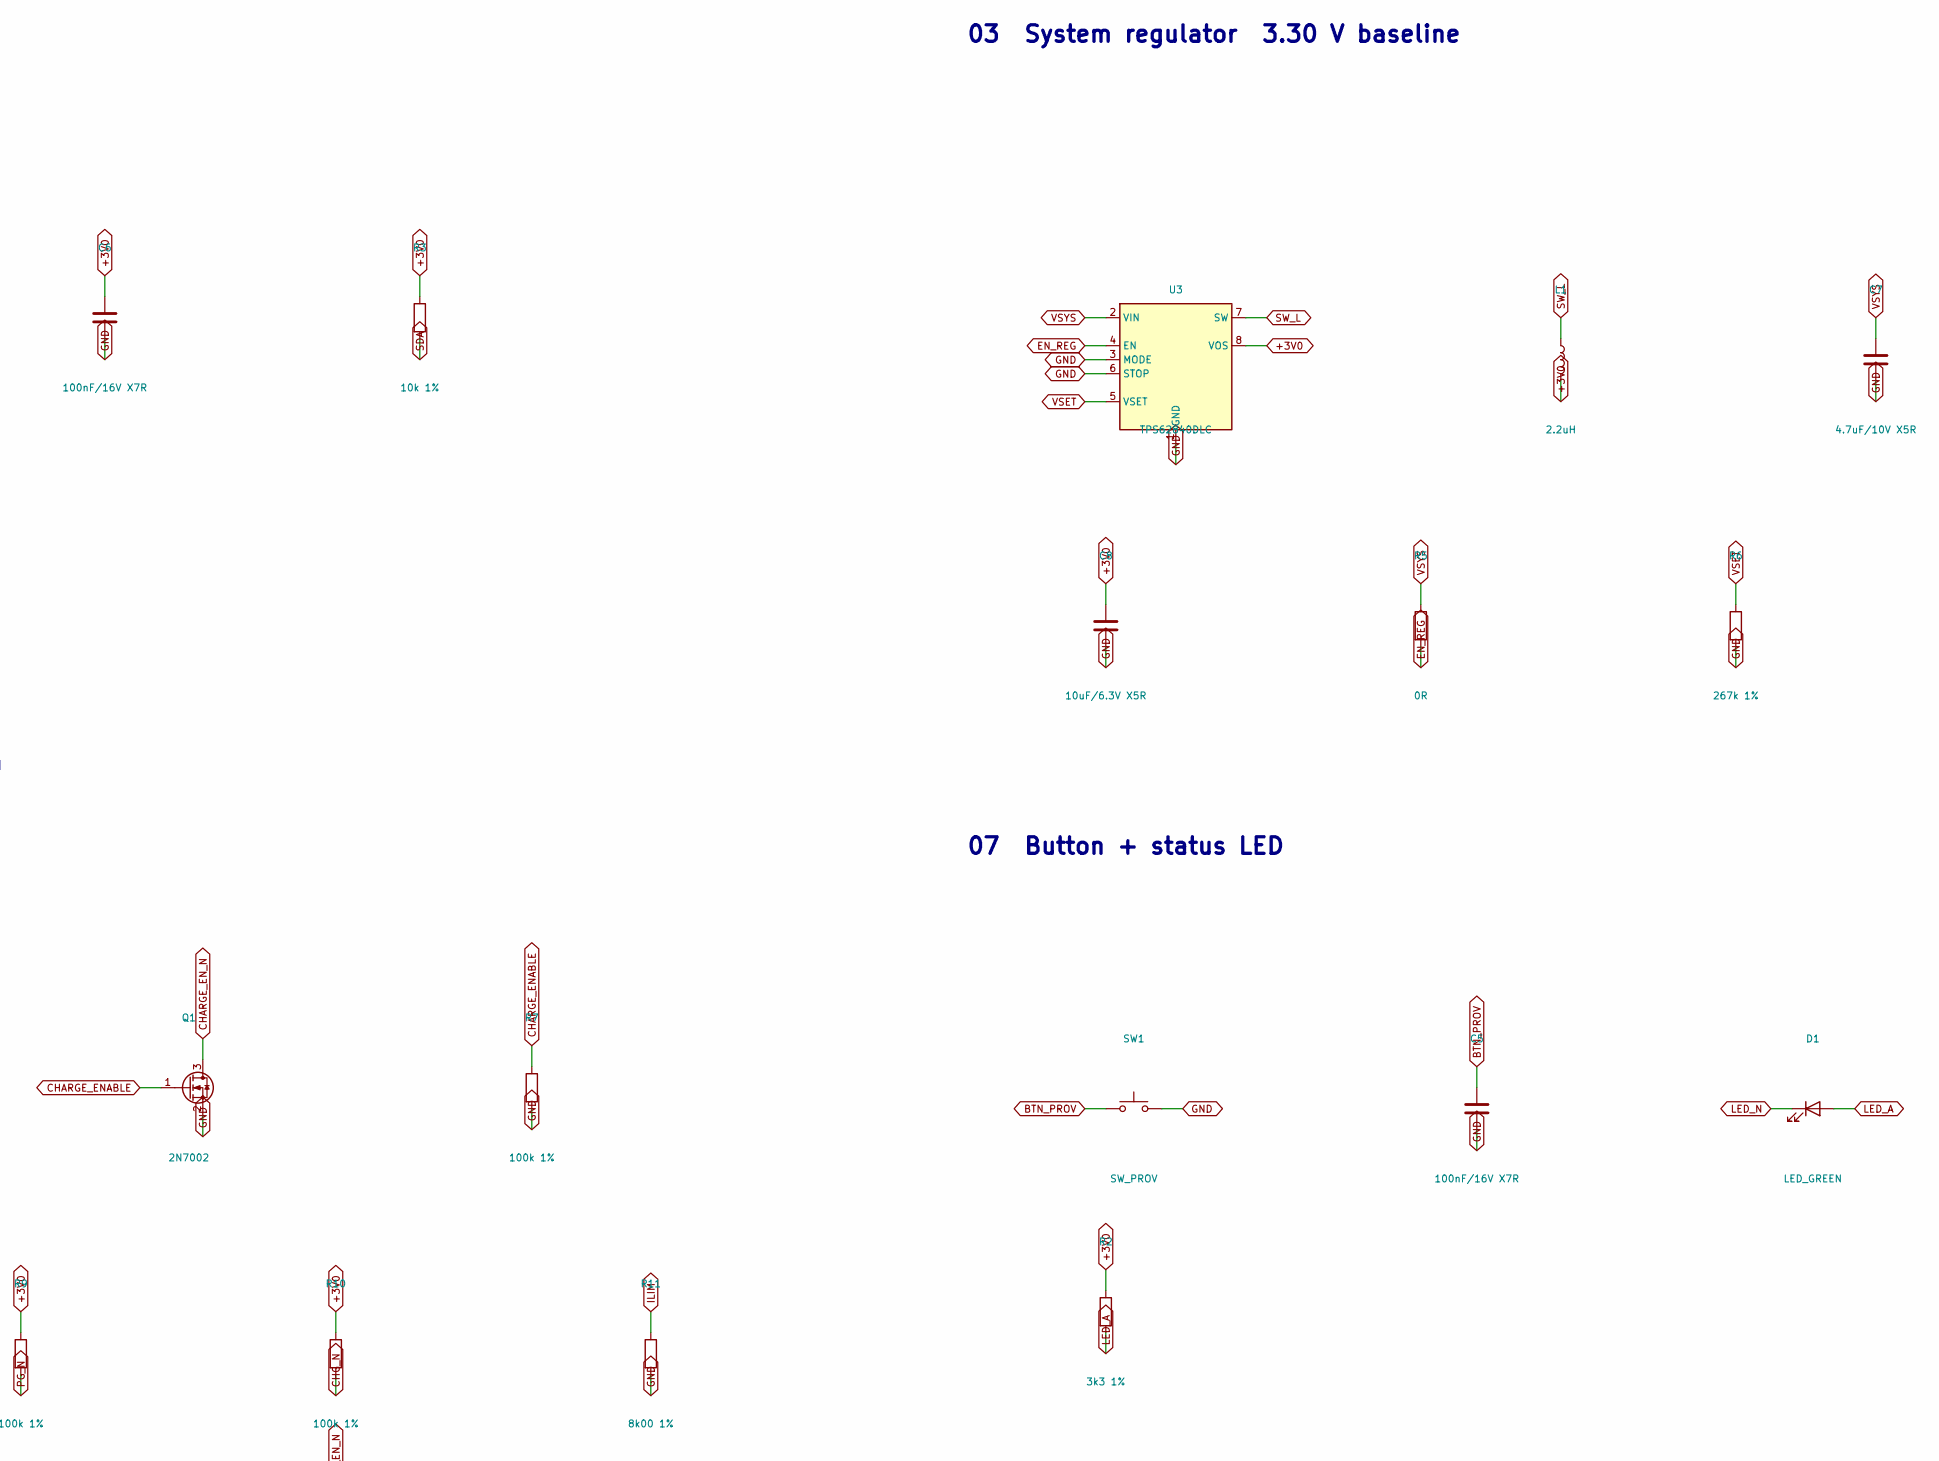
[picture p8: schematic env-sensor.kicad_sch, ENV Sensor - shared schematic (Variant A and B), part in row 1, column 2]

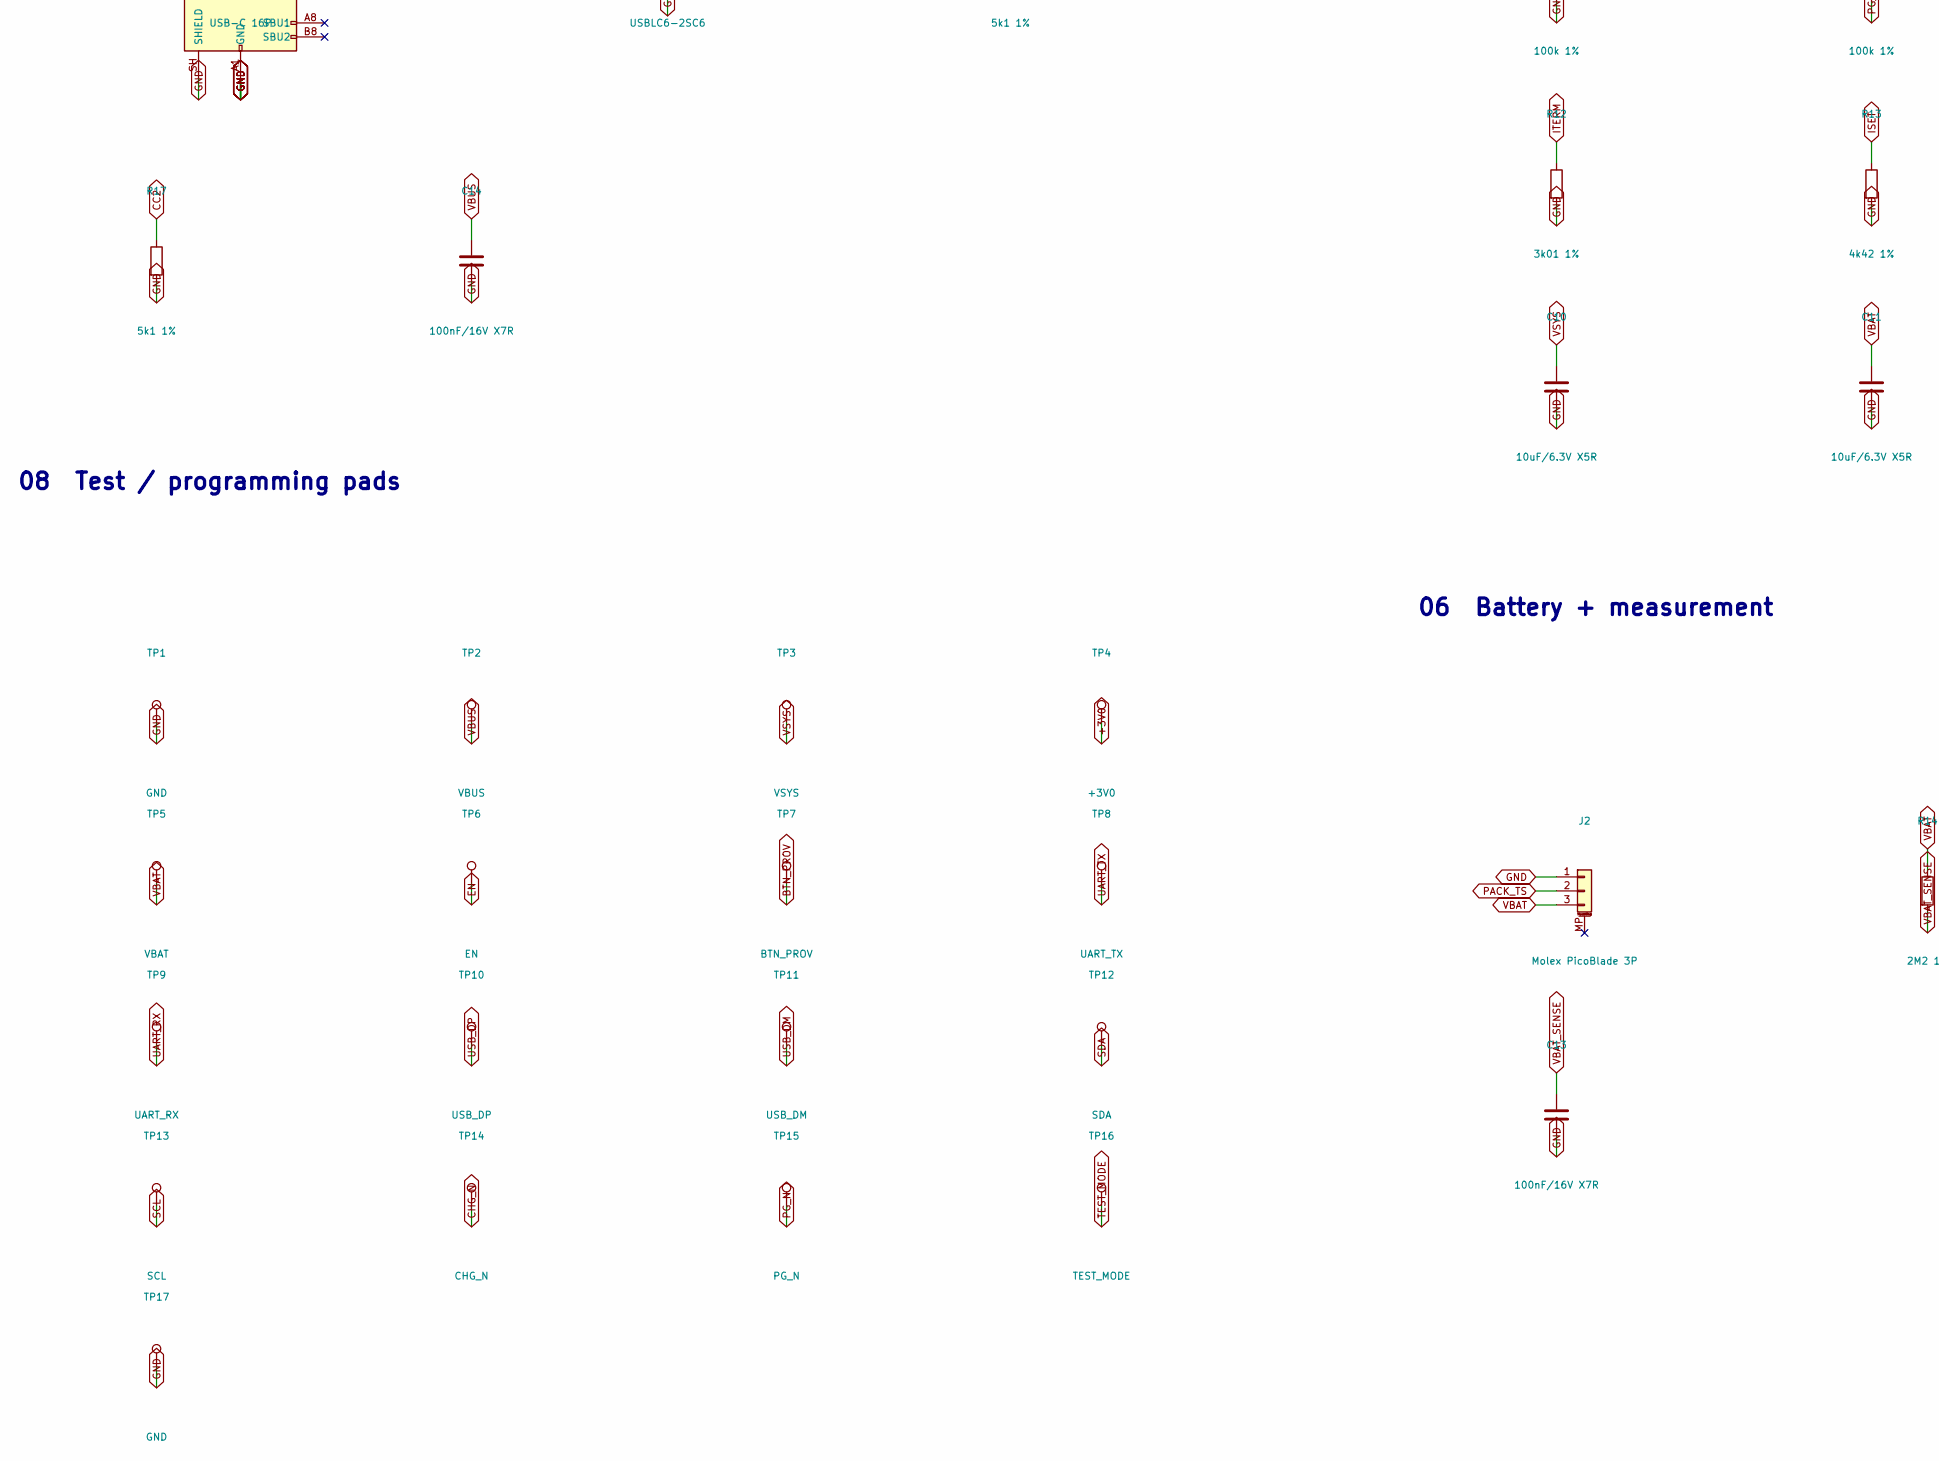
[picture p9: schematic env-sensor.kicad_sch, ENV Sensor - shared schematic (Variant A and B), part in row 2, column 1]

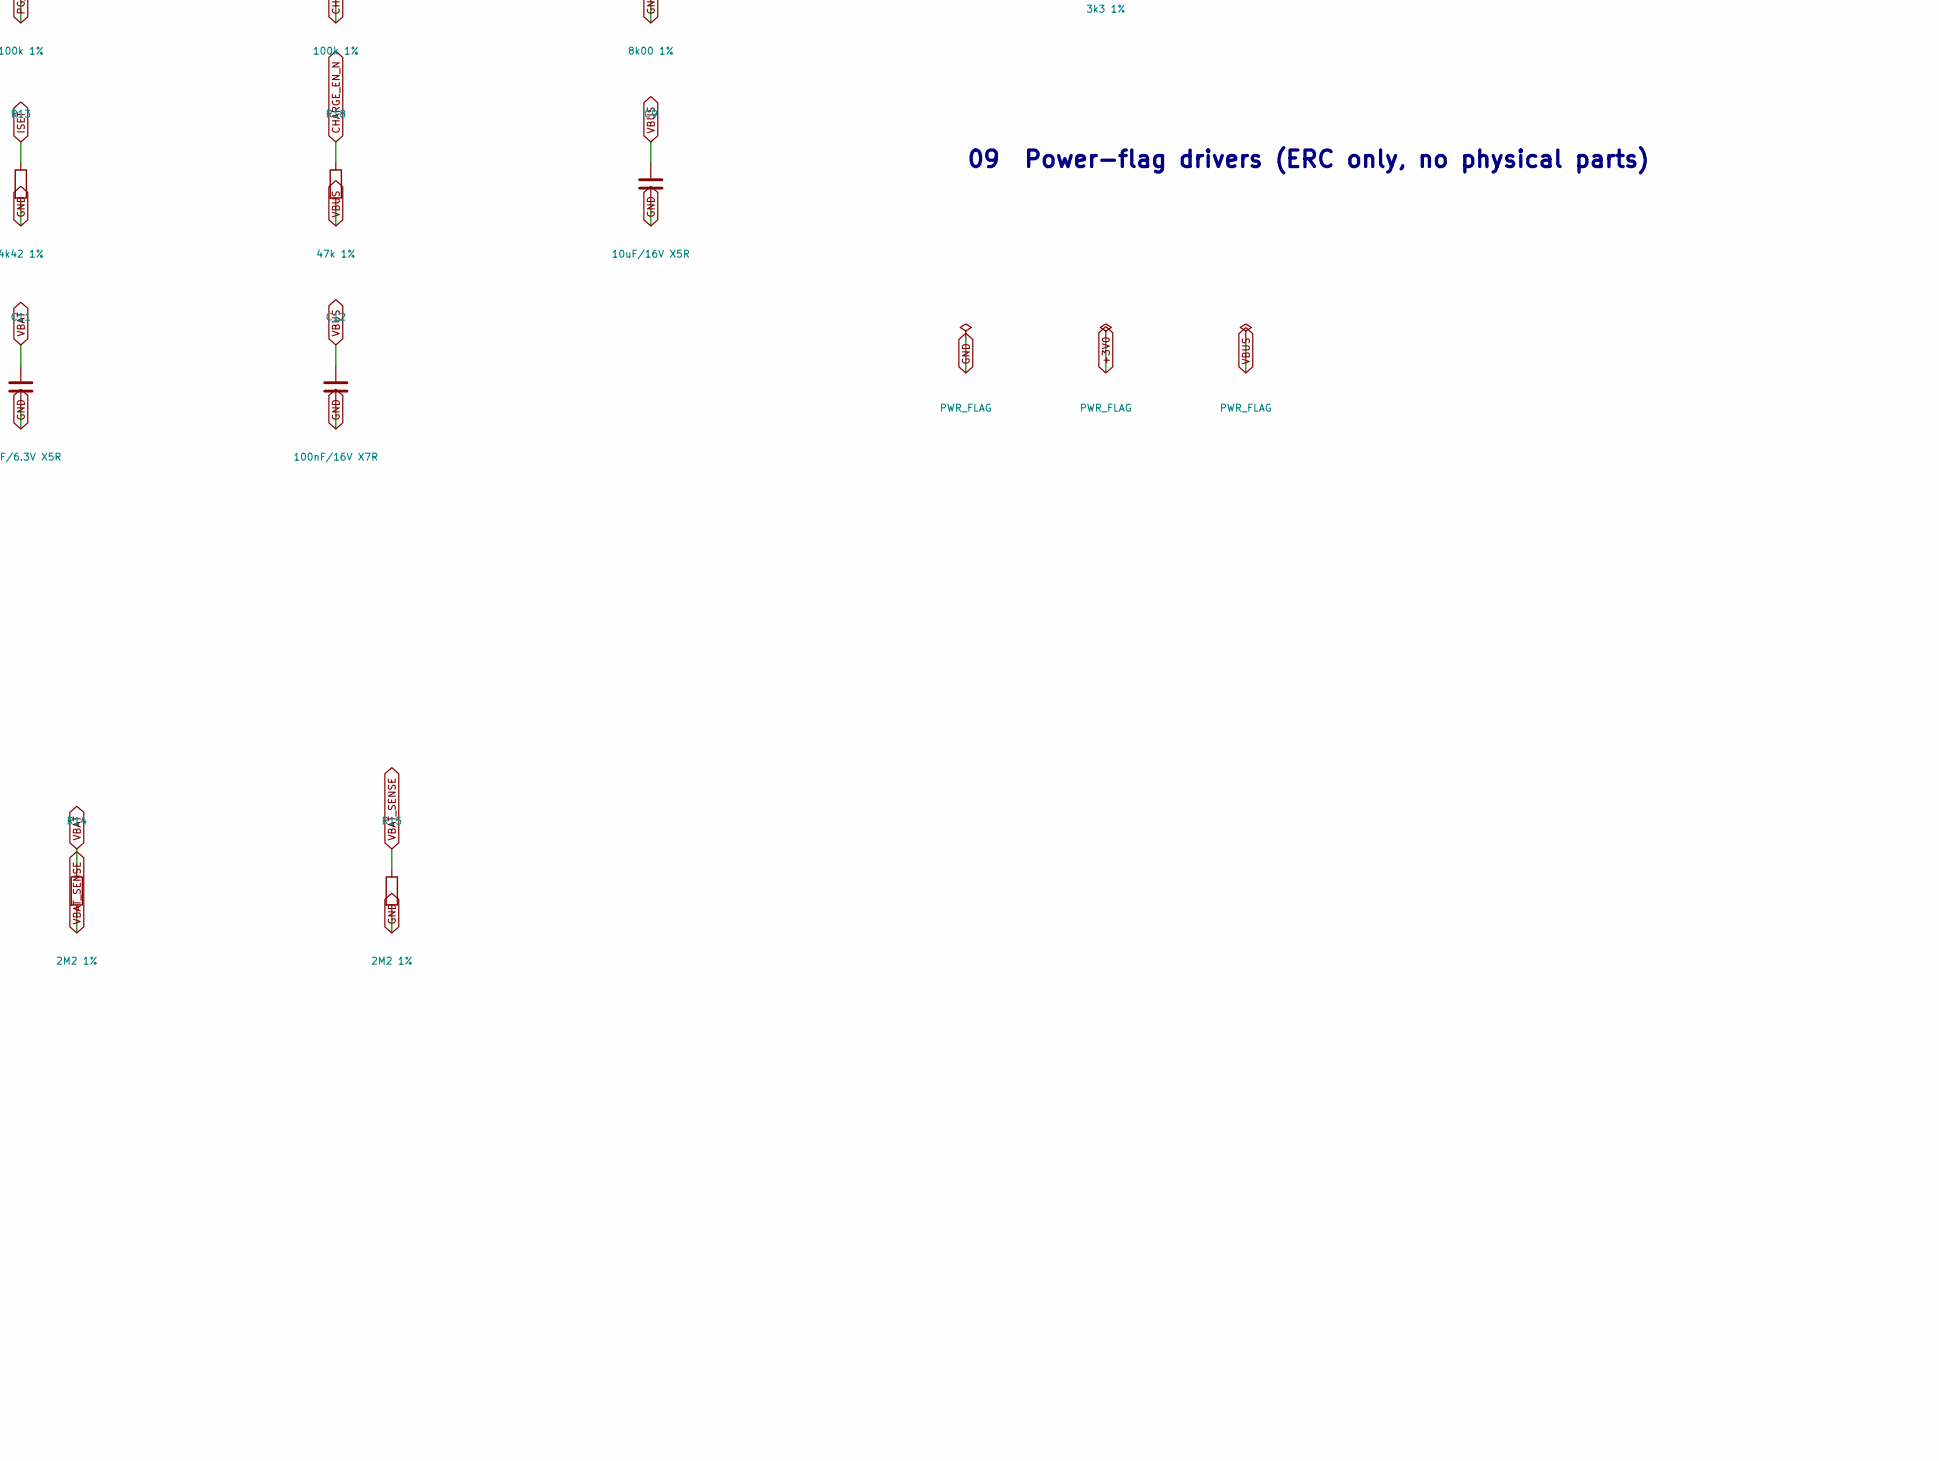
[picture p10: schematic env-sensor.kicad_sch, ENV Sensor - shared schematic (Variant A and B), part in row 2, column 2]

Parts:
C1: 22uF/6.3V X5R; C_0805_2012Metric
C2, C5, C6, C12, C13, C14: 100nF/16V X7R; C_0402_1005Metric
C3, C4: 1uF/16V X7R; C_0402_1005Metric
C7: 4.7uF/10V X5R; C_0603_1608Metric
C8: 10uF/6.3V X5R; C_0603_1608Metric
C9: 10uF/16V X5R; C_0805_2012Metric
C10, C11: 10uF/6.3V X5R; C_0805_2012Metric
D1: LED_GREEN; LED_0603_1608Metric
J1: USB-C 16P; USB_C_Receptacle_HRO_TYPE-C-31-M-12
J2: Molex PicoBlade 3P; Molex_PicoBlade_53261-0371_1x03-1MP_P1.25mm_Horizontal
L1: 2.2uH; L_Murata_DFE201610P
Q1: 2N7002; SOT-23
R1, R3, R4: 10k 1%; R_0402_1005Metric
R2: 3k3 1%; R_0402_1005Metric
R5: 0R; R_0402_1005Metric
R6: 267k 1%; R_0402_1005Metric
R7, R8, R9, R10: 100k 1%; R_0402_1005Metric
R11: 8k00 1%; R_0402_1005Metric
R12: 3k01 1%; R_0402_1005Metric
R13: 4k42 1%; R_0402_1005Metric
R14, R15: 2M2 1%; R_0402_1005Metric
R16, R17: 5k1 1%; R_0402_1005Metric
R18: 47k 1%; R_0402_1005Metric
SW1: SW_PROV; Panasonic_EVQPUJ_EVQPUA
TP1, TP17: GND; TestPad_D1.5mm_Bottom
TP2: VBUS; TestPad_D1.5mm_Bottom
TP3: VSYS; TestPad_D1.5mm_Bottom
TP4: +3V0; TestPad_D1.5mm_Bottom
TP5: VBAT; TestPad_D1.5mm_Bottom
TP6: EN; TestPad_D1.5mm_Bottom
TP7: BTN_PROV; TestPad_D1.5mm_Bottom
TP8: UART_TX; TestPad_D1.5mm_Bottom
TP9: UART_RX; TestPad_D1.5mm_Bottom
TP10: USB_DP; TestPad_D1.5mm_Bottom
TP11: USB_DM; TestPad_D1.5mm_Bottom
TP12: SDA; TestPad_D1.5mm_Bottom
TP13: SCL; TestPad_D1.5mm_Bottom
TP14: CHG_N; TestPad_D1.5mm_Bottom
TP15: PG_N; TestPad_D1.5mm_Bottom
TP16: TEST_MODE; TestPad_D1.5mm_Bottom
U1: ESP32-C6-MINI-1-N4; ESP32-C6-MINI-1
U2: SHT45-AD1F; Sensirion_DFN-4_1.5x1.5mm_P0.8mm_SHT4x_NoCentralPad
U3: TPS62840DLC; TI_DLC0008B_VSON-HR-8_2x1.5mm_P0.5mm
U4: BQ24074RGTR; VQFN-16-1EP_3x3mm_P0.5mm_EP1.6x1.6mm
U5: USBLC6-2SC6; SOT-23-6

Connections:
+3V0: C1.1, C2.1, C3.1, C6.1, C8.1, L1.2, R1.1, R2.1, R3.1, R4.1, R9.1, R10.1, TP4.1, U1.3 (3V3), U2.3 (VDD), U3.8 (VOS)
BTN_PROV: C5.1, SW1.1, TP7.1, U1.23 (IO9)
CC1: J1.A5 (CC1), R16.1
CC2: J1.B5 (CC2), R17.1
CHARGE_ENABLE: Q1.1 (G), R7.1, U1.24 (IO18)
CHARGE_EN_N: Q1.3 (D), R18.1, U4.4 (~CE)
CHG_N: R10.2, TP14.1, U1.29 (IO23), U4.9 (~CHG)
EN: C4.1, R1.2, TP6.1, U1.8 (EN)
EN_REG: R5.2, U3.4 (EN)
GND: C1.2, C2.2, C3.2, C4.2, C5.2, C6.2, C7.2, C8.2, C9.2, C10.2, C11.2, C12.2, C13.2, C14.2, J1.A1 (GND), J1.A12 (GND), J1.B1 (GND), J1.B12 (GND), J1.SH (SHIELD), J2.1, Q1.2 (S), R6.2, R7.2, R8.2, R11.2, R12.2, R13.2, R15.2, R16.2, R17.2, SW1.2, TP1.1, TP17.1, U1.1 (GND), U1.2 (GND), U1.11 (GND), U1.14 (GND), U1.36 (GND), U1.37 (GND), U1.38 (GND), U1.39 (GND), U1.40 (GND), U1.41 (GND), U1.42 (GND), U1.43 (GND), U1.44 (GND), U1.45 (GND), U1.46 (GND), U1.47 (GND), U1.48 (GND), U1.49 (GND), U1.50 (GND), U1.51 (GND), U1.52 (GND), U1.53 (GND), U2.4 (VSS), U3.1 (GND), U3.3 (MODE), U3.6 (STOP), U4.5 (EN2), U4.8 (VSS), U4.17 (VSS), U5.2 (GND)
ILIM: R11.1, U4.12 (ILIM)
ISET: R13.1, U4.16 (ISET)
ITERM: R12.1, U4.15 (ITERM)
LED_A: D1.2 (A), R2.2
LED_N: D1.1 (K), U1.25 (IO19)
PACK_TS: J2.2, U1.6 (IO3), U4.1 (TS)
PG_N: R9.2, TP15.1, U1.28 (IO22), U4.7 (~PGOOD)
SCL: R4.2, TP13.1, U1.16 (IO7), U2.2 (SCL)
SDA: R3.2, TP12.1, U1.15 (IO6), U2.1 (SDA)
SW_L: L1.1, U3.7 (SW)
TEST_MODE: TP16.1, U1.26 (IO20)
UART_RX: TP9.1, U1.30 (RXD0)
UART_TX: TP8.1, U1.31 (TXD0)
USB_DM: J1.A7 (D-), J1.B7 (D-), TP11.1, U1.17 (IO12), U5.1 (I/O1), U5.6 (I/O1)
USB_DP: J1.A6 (D+), J1.B6 (D+), TP10.1, U1.18 (IO13), U5.3 (I/O2), U5.4 (I/O2)
USB_ISEL: R8.1, U1.27 (IO21), U4.6 (EN1)
VBAT: C11.1, J2.3, R14.1, TP5.1, U4.2 (BAT), U4.3 (BAT)
VBAT_SENSE: C13.1, R14.2, R15.1, U1.5 (IO2)
VBUS: C9.1, C12.1, C14.1, J1.A4 (VBUS), J1.A9 (VBUS), J1.B4 (VBUS), J1.B9 (VBUS), R18.2, TP2.1, U4.13 (IN), U5.5 (VBUS)
VSET: R6.1, U3.5 (VSET)
VSYS: C7.1, C10.1, R5.1, TP3.1, U3.2 (VIN), U4.10 (OUT), U4.11 (OUT)

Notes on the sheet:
01 ESP32-C6 module
05 USB-C
08 Test / programming pads
02 Environmental sensor
04 Battery charger + power path
06 Battery + measurement
03 System regulator 3.30 V baseline
07 Button + status LED
09 Power-flag drivers (ERC only, no physical parts)

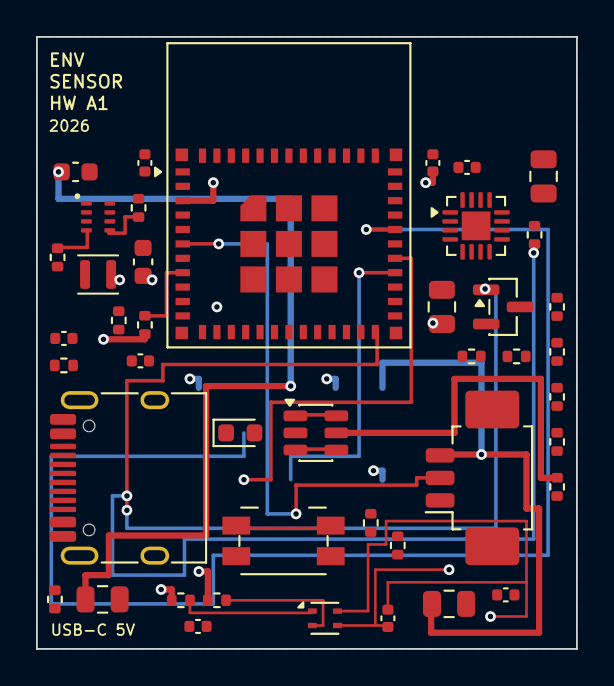
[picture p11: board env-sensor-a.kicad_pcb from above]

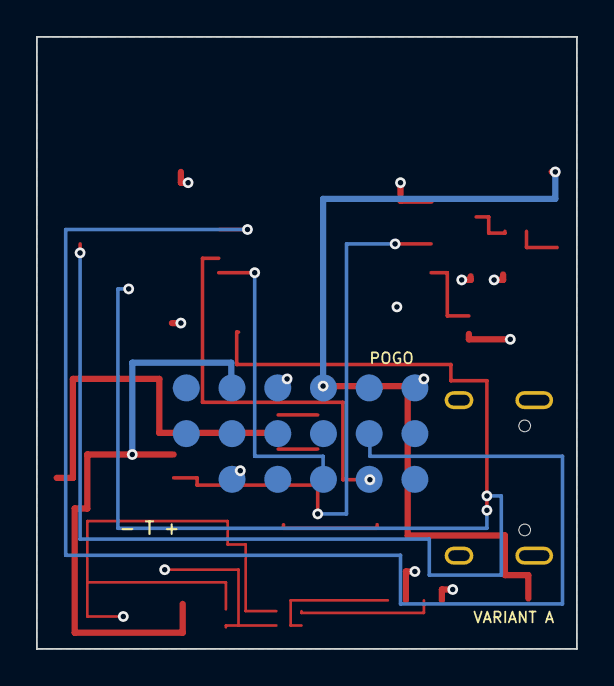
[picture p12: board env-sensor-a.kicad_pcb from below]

Board: 4 copper layers, 30.0 x 34.0 mm, 60 parts (17 on the bottom side), 31 nets.

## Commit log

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2026-08-25 docs: add component selection trade study for sensor and MCU
    Tests the vision document's provisional SHT40 + ESP32-C6 assumption against the
    alternatives raised in review.
    Sensor: rejects BME280 (±0.5 °C / ±3 %RH / 0.5 %RH per year would swamp the very
    A/B thermal effect this product exists to measure) and disqualifies BME680/688
    (a 200-400 °C VOC hotplate on the same die as the temperature element, plus a
    closed-source BSEC dependency). Upgrades the baseline to SHT45-AD1F: same
    footprint, address and driver as SHT40, but ±0.1 °C / ±1.0 %RH and an integrated
    PTFE membrane addressing contamination, the dominant multi-year failure mode.
    HDC3022 qualified as second source.
    MCU: confirm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
2026-08-25 feat(hw): add verified project footprint library
    Vendors the 15 footprints needed for the design from the official KiCad
    footprint library so a checkout builds identically without a system KiCad
    install, and authors the two that do not exist upstream:
    - TI_DLC0008B_VSON-HR-8_2x1.5mm_P0.5mm for the TPS62840DLC, built from the
    land pattern example in TI drawing 4224310/A (8 pads 0.6 x 0.25 mm, 0.5 mm
    pitch, 1.3 mm row centres, no exposed pad - the EP is DGR-only)
    - TestPad_D1.5mm_Bottom, a bottom-side pogo pad, since assembly is single-sided
    top and the fixture should be a flat plate
    README records provenance, licence, the verification basis for both authored
    footprints, and the DFE201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
2026-08-25 feat(boardgen): add shared design model, placer and offline rule checks
    The generator is the mechanism behind the project's central rule that A and B
    are one design: design.py holds the parts, netlist and net classes; variants.py
    holds the only variant-specific data (outline, sensor position, thermal zones);
    place.py anchors the mechanically constrained parts by hand and packs the
    passives by spiral search around their anchor, identically for both boards.
    check.py catches the failure modes a generated layout is prone to - courtyard
    overlaps, parts off the outline, pads inside the antenna keep-out, heat sources
    too near the sensor, and for Variant B anything at all on the thermal neck or
    isl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
2026-08-25 build: add make pipeline, DRC gate and manufacturing outputs
    KiCad 10 is available now, so the generated boards get checked and exported by
    KiCad itself rather than only by the generator's own rules.
    kicad-cli found what the offline checks could not, and the generator is fixed at
    source in every case:
    - a nested (justify) token stopped the boards loading at all
    - the RF keep-out was drawn 2 mm into the module body, so it swallowed the
    module's own ground pads; it now spans the full board width and stops exactly
    at the antenna boundary, which is also the correct RF answer
    - the USB-C receptacle's through-hole shield lugs were shorting a bottom-side
    pogo pad: the offline checker had ass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
    [bom.csv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]
2026-08-25 docs: add floorplan comparison, generated thermal model and A/B test plan
    The thermal model is generated from the live board geometry (make thermal), so
    it cannot drift from the boards it describes, and it sweeps the convection
    coefficient instead of asserting one - the conduction terms are solid, the
    convection term is not, and the honest output is a ratio plus a range.
    Two findings drive the floorplan comparison. On a 4-layer board the copper
    planes conduct 112x more heat than the FR-4, so Variant A's board is an
    isothermal slab and its sensor reads the PCB rather than the room under every
    plausible enclosure assumption - A is a good layout of a geometry that cannot
    win, and its value is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
2026-08-25 ci: gate on generator rules, output reproducibility and KiCad DRC
    Two jobs. The first runs the offline rule checks and then regenerates every
    generated file, failing if the working tree differs from what is committed -
    AGENTS.md requires generated artifacts to be both committed and reproducible,
    and this is what makes that claim testable. The second runs in the KiCad 10
    container, enforces the DRC gate and uploads the fab package as an artifact.
    Adds a README that states the project's status honestly: placement- and
    rule-complete, DRC-clean, not yet routed, phase 6 of 14.
2026-08-25 feat(sch): generate the shared schematic and gate on ERC + PCB parity
    The boards had a netlist but no schematic, so nothing could be reviewed by a
    human or checked by KiCad against the layout. This adds one generated schematic
    for both variants - a second schematic would be a second thing to keep in sync
    and a second thing to get wrong.
    Style is net-label driven: every pin gets a stub and a global label carrying its
    net name, laid out as nine titled blocks following the sheet split the vision
    document asked for. Blocks are packed by each symbol's real extents rather than
    a fixed pitch, because a fixed pitch let the tall module overlap the row beneath
    it. They are regions on one A1 sheet rat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
    [cpl-a.csv, cpl-b.csv, env-sensor-a-B_Cu.gbr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]
2026-08-26 build: add localPipeline.sh, a design-derived cost model and a docs/model check
    localPipeline.sh follows the same shape as the one in GarminActivityMap - a
    run_step helper, per-step STEP_DETAIL, a PASS/FAIL summary table, non-zero exit
    on failure - with the steps a hardware repo needs: toolchain, syntax, library
    integrity, generator rules, reproducibility, doc consistency, BOM, ERC, DRC +
    schematic parity, and fab outputs. It degrades to SKIP rather than FAIL when
    kicad-cli is absent, so it is useful on a machine without KiCad. All ten steps
    pass; a negative test (changing the neck width by 0.1 mm) correctly fails both
    the reproducibility and doc-consistency steps.
    tools/check_docs.py recom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
2026-08-26 feat(mech): add the parametric enclosure, and the two requirements it breaks
    Phase 7. The case is generated from the board model - outline, sensor position,
    antenna keep-out and every connector position are read from it, never retyped -
    so it cannot drift from the PCB it holds. tools/boardgen/enclosure.py produces
    the numbers and checks them; mechanical/env-sensor-case.scad turns them into
    solids; make mech renders STL when openscad is installed and says so when it is
    not.
    This is not decoration. docs/45-thermal-model.md shows Variant B's coupling
    swinging between 0.13 and 0.43 purely on how well the sensor chamber breathes,
    so the dividing wall at the neck and the vents over the island are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
    [case-a.scad, case-b.scad, env-sensor-case.scad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]
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2026-08-26 build: stop committing the enclosure meshes - CGAL triangulation is not stable
    The pipeline's reproducibility step failed on two of the four STLs after a
    rebuild from unchanged sources. It is not a defect in the model: OpenSCAD's CGAL
    triangulation is not deterministic between runs, so the same .scad yields
    byte-different meshes - a handful of facets get split differently each time.
    Same conclusion as the gerbers, different cause. The .scad files and the
    generated parameters are sources and stay committed and drift-checked; the STLs
    are build products. AGENTS.md now names both reasons separately rather than
    attributing everything to timestamps, and CI installs openscad, builds the
    meshes an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
    [case-a-base.stl, case-a-lid.stl, case-b-base.stl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]
2026-09-07 fix(hw): enable charger safety timers and reopen pack protection
    TI SLUS810N specifies open TMR for default timers; grounding disables them. Both variants inherit the fix. Generated artifacts follow separately; pack-temperature inhibit remains unqualified.
2026-09-07 fix(hw): wire the status LED for active-low drive
    Keep the verified library pin numbering and route supply through R2 to the anode. Add executable current-path and timer regressions; regenerated artifacts follow.
2026-09-07 fix(hw): preserve the regulator enable isolation link
    Do not fold EN_REG into VSYS: that bypassed R5 on both boards. TI SLVSEC6D Pin Functions defines EN as the shutdown control. Generated artifacts follow.
2026-09-07 fix(hw): use a 3.3 volt baseline with explicit rail qualification
    A 3.0 V nominal rail has no margin above the module minimum. Keep the common historical net name and make low-voltage characterization a separate experiment. Generated outputs follow.
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2026-09-07 fix(mech): remove lid interference with the board and components
    [env-sensor-case.scad]
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2026-09-07 fix(mech): relieve the lid ring around the chamber divider
    [env-sensor-case.scad]
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2026-09-08 fix(boardgen): confine B plane access to the main board near the neck
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2026-09-08 fix(hw): record the reviewed development DRC state after corrections
    KiCad 10.0.6: zero errors, zero parity, no ignored checks. A has 54 unconnected items and 6 capped warnings; B has 58 and 10. Waive only the previously reviewed U1/U2 embedded-keepout mismatches and exact isolated GND zones for development. Release remains blocked.
2026-09-08 chore(hw): regenerate both boards and previews after review fixes
    Emit shared electrical corrections, validated routing and strengthened rules. Development allowances: A54/B58 unrouted and A6/B10 warnings per e584c6a; zero errors and parity differences. Preserve native KiCad SVG formatting. These are draft boards.
    [bom.csv, env-sensor-a.kicad_pcb, env-sensor-b.kicad_pcb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]
2026-09-08 chore(mech): regenerate corrected enclosure geometry and fit report
    Reflect divider and USB opening corrections and dimension-based battery checks. Mesh bounds and seated lid intersections pass; physical pack qualification remains open.
    [params-a.scad, params-b.scad]
2026-09-09 feat(hw): define fail-safe battery and USB power architecture
    Select the protected LP702040 pack and keyed three-wire PicoBlade interface, feed its 103AT-2 NTC to both charger TS and the MCU ADC, and bound charge current for the cell.
    Default charging disabled through a VBUS-referenced CE pull-up and NMOS driver, and default USB current selection to USB100 until an enumerated host permits USB500. Resize both enclosures from the same pack envelope and document the physical qualification gate.
    [env-sensor-case.scad]
2026-09-09 chore(hw): regenerate both variants for power architecture
    Regenerate the shared schematic, both PCB layouts, symbol library, BOM, netlist, enclosure parameters, cost reports and floorplan previews from the updated electrical platform.
    Record the reviewed KiCad 10 development budget: zero errors and parity differences, with 59 unrouted items on A and 60 on B. These artifacts remain non-release drafts.
    [bom.csv, env-sensor-a.kicad_pcb, env-sensor-b.kicad_pcb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]
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2026-09-09 fix(ci): install make in KiCad workflow container
    The official KiCad image provides kicad-cli and Python but not GNU Make. Install it alongside OpenSCAD before invoking the repository pipeline in both quality and release jobs.
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2026-09-18 docs(docs): prioritize remaining work through the controlled series
    Reconstruct the completed review, pack architecture and CI work at d50053b. Separate open architecture, routing, assembly, firmware and physical qualification gates with owners and completion criteria. Record the rejected scratch routing experiment rather than enlarging warning allowances, and correct stale master-plan paths and board dimensions.
2026-09-18 docs(docs): record verified gates and corrective branch review
    All 14 development stages pass with 50 regressions and two KiCad negative tests. Live release-check, release-mode exports and packaging correctly reject the still-unrouted and unqualified hardware. Preserve the reviewed baseline, evidence, rejected routing experiment and remaining priorities without claiming prototype or product completion.
2026-09-18 docs(hw): record charger suspend and button wake blockers
    BQ24074 EN2 is fixed low, so charge inhibit cannot select USB standby. IO9 is not a C6 EXT1 wake pin. Track both architecture decisions before routing freeze and retain qualification holds.
2026-09-18 fix(boardgen): allow sensor vias outside the thermal areas
    Bottom-side SDA/SCL test pads cannot be reached under a global no-via rule. Limit the ban spatially for both variants and attempt their main-board branches without rerouting the island. Four KiCad controls pass; DRC remains zero errors/parity with unchanged 59/60 incomplete connections.
2026-09-18 build(boardgen): regenerate spatial sensor via rules
    Regenerate both variant rule files from the preceding main-board sensor routing fix. Existing board geometry and thermal neck routes are unchanged.
2026-09-18 feat(fw): add bounded C6 bring-up and traceable fixture capture
    Build a shared A/B ESP-IDF image with charging, USB500 and radio disabled. Read and CRC-check SHT45, report calibrated-divider ADC results with qualification flags, then sleep under a resetting watchdog. Capture validates chip/image identity, preserves failures and refuses serial overwrite. Pin SDK and CI image; test all single-bit sensor-frame faults and fixture rejection paths. Hardware, charging and full telemetry acceptance remain open.
2026-09-18 feat(prod): separate controlled prototype orders from product qualification
    First boards cannot depend on measurements that require those boards. Add a distinct 5+5 prototype review manifest and live-gated package path while preserving every product qualification requirement. Require complete clean layouts, electrical/sourcing/assembly/mechanical/order reviews, bring-up build and full manufacturing inputs. Six tests cover missing reviews, incomplete routing, CLI gate failure, archive contents and checksums. Current real prototype gate correctly rejects the unfinished design.
2026-09-18 docs(prod): update the implementation checkpoint and remaining handoffs
    Record the compiled bring-up image, fixture tooling and independent prototype path without closing physical gates. Publish the precise remaining priority order and reject external-router experiments that increased DRC failures.
2026-09-18 fix(prod): include library resolution tables in prototype archives
    Review found that the explicit prototype file list omitted the local symbol and footprint tables. Include both and assert their archive presence so reviewers can reopen the archived sources with the vendored libraries.
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2026-10-14 docs(docs): record prototype cleanup and atomic commit plan
    Preserve the original audit as history and document the current controlled prototype disposition. Prioritize stabilizing the existing changes, validating both variants, and separating source corrections from regenerated artifacts before pushing. Routing, supplier records and physical qualification remain open; this plan is not fabrication approval.
2026-10-14 fix(hw): align component libraries with manufacturer drawings
    Replace mismatched L1, charger, ESD, MOSFET and LED land patterns with source-traced adaptations retaining upstream licences. Match Kingbright numeric polarity in the symbol and footprint. Model only manufacturer-confirmed internal conductors in U5 and SW1; explicit symbol vendoring supports reviewed flat and split upstream libraries.
    Verification: manufacturer drawing desk review and focused KiCad jumper positive/negative controls pass. Exact purchasing candidates and capacitance/inductor assumptions are documented; assembler orientation, process and physical qualification remain open. Shared model adoption and regenerated A/B s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
2026-10-14 fix(hw): define the shared controlled prototype platform
    Separate runtime IO1 wake from the IO9 download strap, pull GPIO8 high for deterministic joint download, make EN2 controllable with valid-rail standby defaults, and isolate raw charger TS from the MCU using mandatory DNP R21. Adopt reviewed component packages and exact passive candidates, with C1/C8 capacitance bounds retained as documented assumptions. Correct the shared USB socket edge datum and widen B to accommodate the same electrical platform.
    ADR-001 and the EDS distinguish the locked prototype disposition from unresolved charging, unrestricted USB, supplier and physical qualification. Both variants move together; USB P/N namin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
2026-10-14 fix(fw): enforce standby controls and independent button wake
    Preload charge-disable and EN1/EN2 standby latches before releasing GPIO holds, use only external pull-ups on charger status inputs, and release EN controls to their hardware defaults before sleep. Arm IO1 wake only when the button is released to avoid a held-button reset loop. Fixture capture accepts the declared STANDBY policy and rejects unsupported current modes.
    Verification: pinned ESP-IDF v5.5.4 build, host sensor CRC/fault checks and capture regressions pass. Printed states are not physical qualification; product firmware, charging supervision and startup/suspend/wake measurements remain open.
2026-10-14 fix(mech): retain the PCB and clear the recessed USB cable
    Keep supports on the electronics body, add positive X/Y stops without loading the sensor neck, and remove the false top access hole for the side-actuated switch. Derive support height and complete wall/lid relief from the provisional cable-boot envelope, separating it from the pack swelling allowance. Carry corrected package maximum heights into both variants.
    Verification: 17 enclosure/STL tests, four mesh bounds, both seated lid/base and both USB case/pack empty-intersection checks pass. Generated enclosure reports and parameters follow separately. Printed tolerances, closure strength and actual pack/cable fit remain physical acce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
2026-10-14 fix(prod): require purchasing identity for fitted BOM lines
    Reject fitted lines missing an exact MPN, manufacturer or alternate/risk disposition rather than treating generic passives as purchasing-ready. Preserve unpopulated options and fixture-pad exclusions. Correct filtered-sensor material in cost descriptions and update historical bounding-area calculations for the wider B board.
    Verification: BOM identity and negative-control tests pass. Datasheet review and exact candidates are documented in docs/63; no substitute, live price, supplier lot or assembly approval is implied. Regenerated BOM and cost reports follow separately.
2026-10-14 fix(boardgen): preserve sensor keepouts and legal pad escapes
    Respect local pad rotation in routing obstacles, preserve the exact sensor package exclusion as a board rule area, and remove orphan copper instead of accepting warnings. Reserve four outward sensor exits and apply interacting net-class clearances. B rotates only its nonpolar island bypass capacitor; both variants retain the shared netlist. Number the battery cavity legend explicitly.
    Verification: host geometry regressions and actual KiCad island positive/negative controls pass, including forbidden package/antenna copper and an actively enforced USB coupling rule. Full-board routing and reviewed return paths remain open; regener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
2026-10-14 fix(hw): keep the USB connector silk inside the PCB edge
    The corrected HRO edge datum places the connector mouth beyond the PCB. Omit its off-board front silk and stop both side silk lines at local y=3.0 mm, inside the 3.19 mm board-edge datum. Preserve copper, holes, courtyard, pin numbering and the complete fabrication-layer body drawing. Both variants share this library adaptation.
2026-10-14 fix(boardgen): distinguish track branches and layers in UUIDs
    The generated A/B checkpoint contained duplicate segment identifiers because the seed used only net, local segment index and start point. Include layer, both endpoints and width so branches and opposite-layer via departures preserve distinct stable identities. A focused regression checks uniqueness and deterministic emission; copper geometry is unchanged.
2026-10-14 fix(boardgen): enforce power widths and prune dead route branches
    Place specific power and switch width constraints after the generic fabrication rule, use 0.4 mm power trunks, and permit narrow power copper only inside generated bounded escape corridors. Apply the larger actual net-class clearance and hole clearance to routing obstacles. Keep USB explicitly unrouted and the switch node on the top layer. Remove unfinished leaf branches and unused signal vias while preserving original connected polylines and sensor paths.
    Cache immutable board geometry and use deterministic A* search to make both-layout generation practical. Verification: cleanup/cache host controls and four real KiCad power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
2026-10-14 chore(hw): regenerate the controlled prototype checkpoint
    Regenerate shared schematic/BOM/netlist, both PCB projects/rules and floorplan SVGs from the electrical, library and routing corrections in 3c343e2, 135b78b, d863f52, 7802bdf, 0852837 and 7206b19. Preserve R21 DNP and the common A/B electrical platform.
    Fresh KiCad 10.0.6: zero ERC violations; both boards have zero DRC errors, warnings and schematic parity differences, with no ignored checks. Development routing exception: A59/B52 unconnected items remain, explicitly recorded in the budget; all old warning allowances are removed. Prototype and product manufacturing gates still require complete routing and real qualification evidence.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
2026-10-14 fix(boardgen): bound USB coupling gap and isolate rule controls
    KiCad counts parallel tracks inside the permitted gap range as coupled. The prior min/opt-only constraint had no upper bound, so widely separated parallel tracks passed. Add an explicit provisional 0.25 mm maximum around the existing 0.20 mm optimum, without claiming qualified impedance or stackup.
    Isolate the USB fixture from production copper and attach small terminals; reject a separated 6 mm pair and require a properly coupled pair to have zero errors. Isolate the sensor package rule from stronger thermal rules and verify removing that package rule changes the result. Both actual KiCad controls pass. These targeted tests ex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
2026-10-14 chore(hw): regenerate bounded USB coupling rules
    Regenerate both variant rule sets from the preceding maximum-gap correction. The shared electrical model and copper are unchanged; no manufacturing gate is waived.
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2026-10-15 docs(docs): compare manufacturers for three samples of each variant
    Research eleven vendors for Germany delivery, distinguishing assembly eligibility, public bare-board formulas, promotional floors and project quotations still required. Retain dated primary-source notes, explicit six-PCBA budget assumptions, procurement/panel/bulk tradeoffs, sensor/stackup/inspection criteria and a comparable RFQ specification. Correct the earlier three-board note rate and 51 mm B envelope and point to the dated review.
    No vendor outreach, design upload, order or binding quotation was made. Verification: independent EU price/MOQ review, budget arithmetic/local links/whitespace checks and all 15 local pipeli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
2026-10-21 fix(docs): cost fitted populations and qualify panel assumptions
    Exclude DNP placements, solder joints and component prices, count exact MPNs, and distinguish outline material from billing rectangles. Require explicit setup acceptance and independent panel fabrication allowance; label stale rates as historical and remove unsupported vendor and savings claims. Twelve focused cost/BOM regressions pass.
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2026-10-21 docs(docs): record verified cost correction checkpoint
    Close W1 against its atomic source and generated commits and the full 15-stage pipeline. Routing and all manufacturing/physical gates remain open.
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
